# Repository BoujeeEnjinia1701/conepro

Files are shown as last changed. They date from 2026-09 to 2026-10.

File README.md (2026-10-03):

# ConePro

     

**Area:** Situational Field Hardware · **TRL:** 3 of 9 (proof of concept on paper) · **Value-engineering target:** about $400 USD (hypothetical control target; estimated instrument cost $346) · **Difficulty:** 3 of 5

Portable dynamic cone penetrometer with a digital depth encoder and blow counter that logs penetration curves to a phone.

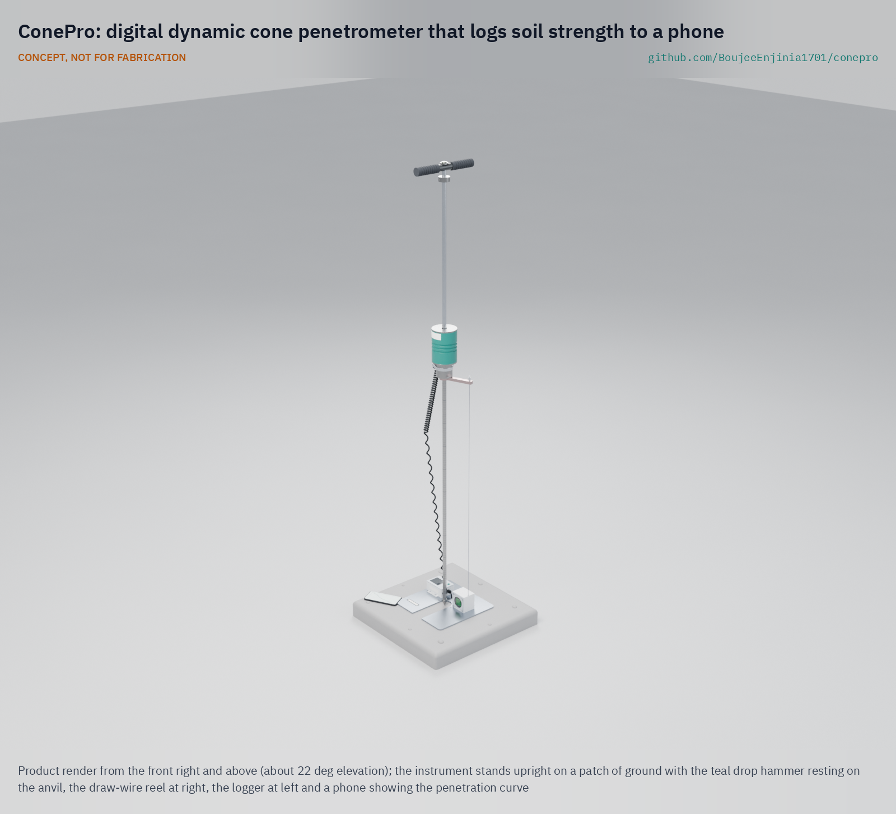
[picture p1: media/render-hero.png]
ConePro: digital dynamic cone penetrometer that logs soil strength to a phone, product render


[Exploded render](media/render-exploded.png) · [Detail render](media/render-detail.png) · [Interactive 3D model](media/viewer.html) · [Concept blueprint (PDF)](media/concept-blueprint.pdf) · [General arrangement CNP-DWG-001 (PDF)](cad/drawings/CNP-DWG-001.pdf) · [Calculations](docs/04-calcs/01-sizing.md) · [Prototype build plan](docs/05-build-plan.md) · [Design decisions](docs/06-design-decisions.md) · [Review note](docs/REVIEW.md)

## Concept rationale

The dynamic cone penetrometer is already the cheapest credible way to profile soil strength in the field, and decades of published correlations depend on its exact geometry. ConePro therefore changes nothing about the hammer, drop, rod or cone and adds only what the manual test lacks: an automatic depth reading, a blow count, a tilt check and a clean digital record. That lets one person do what took two, and keeps every result comparable with existing DCP data.

It is open and garage-buildable because the users who most need fast soil screening, such as small contractors, NGO engineers and rural road agencies, are the least able to buy or repair closed instrumented penetrometers. The steel parts are simple machined pieces any local shop can make, the electronics are off-the-shelf modules on three AA cells, and the sensor set is designed to clamp onto penetrometers people already own.

## Burning platform

Roads, shelters and water points all sit on ground whose strength is usually guessed rather than measured. The World Bank estimates that about [one billion rural people, one in eight people worldwide, live more than 2 km from an all-season road](https://datatopics.worldbank.org/sdgatlas/goal-9-industry-innovation-and-infrastructure/), and a 2026 dataset of 50 African countries and regions found an [average paved rate of only 17.4 %](https://essd.copernicus.org/articles/18/267/2026/) (Liu et al., *Earth System Science Data* 18, 267). The same authors note that most unpaved roads are dirt, and building or upgrading such a road starts from the strength of the ground beneath it.

Laboratory strength testing has long been skipped for reasons of time and cost: in 1956 Scala wrote that "very few road authorities use a strength test in evaluating the subgrade of a road" and proposed quick static and dynamic cone tests instead ([TRID record](https://trid.trb.org/View/1194062)). The DCP descends from that work. Even a well-resourced agency runs it as a two-person, pencil-and-form test: Minnesota's user guide describes one person on the hammer and a second reading and recording [the penetration for each blow](https://mdl.mndot.gov/index.php/_flysystem/fedora/2023-08/1993mrrdoc002.pdf). Removing that second person and the transcription step is what lets more points be tested per day where it matters.

## Where it could be used

### By industry

| Industry | Use |
| --- | --- |
| Low-volume and rural roads | Subgrade and gravel layer strength along a route, for DCP-based pavement design and maintenance planning |
| Humanitarian shelter and WASH | Screening ground for shelters, water tanks, latrines and access tracks where no lab is within reach |
| Utilities and civil contracting | Checking compaction of trench backfill and pipe bedding before reinstatement |
| Building and site preparation | A first look at pad and footing areas to decide where a geotechnical engineer should investigate |
| Mining and agriculture haul roads | Rapid checks of unsealed haul and farm roads after rain |
| Teaching and research | An open instrument and data format for soil mechanics courses and correlation studies |

### By country or region

| Country or region | Why it matters there |
| --- | --- |
| Burkina Faso | A Rural Access Index of [23.8 in 2020](https://datatopics.worldbank.org/sdgatlas/goal-9-industry-innovation-and-infrastructure/): only about one in four rural people live near a road usable year-round |
| Zambia and Kenya | Rural access ranges from [17 % in Zambia (2011) to 56 % in Kenya (2009)](https://datatopics.worldbank.org/sdgatlas/goal-9-industry-innovation-and-infrastructure/), so many earth and gravel roads are still to be built or upgraded |
| Peru | A Rural Access Index of [37.2 % in the 2017/18 update](https://documents1.worldbank.org/curated/en/543621569435525309/pdf/World-Measuring-Rural-Access-Update-2017-18.pdf), above 50 % in some Andean departments but below 5 % in Amazon regions, so many rural roads are still to be built on untested ground |
| Bangladesh | Rural access of [87 % in the World Bank's 2016 pilot](https://documents1.worldbank.org/curated/en/543621569435525309/pdf/World-Measuring-Rural-Access-Update-2017-18.pdf), the highest of the pilot countries, so much of the rural network already exists and the work shifts to checking and maintaining it |
| United States | Minnesota has used the DCP as an [acceptance tool for edge drain trench compaction since 1993](https://mdl.mndot.gov/index.php/_flysystem/fedora/2023-08/1993mrrdoc002.pdf), a high-income example of routine, repeated field testing |
| Australia and New Zealand | Scala's 1956 paper to the second Australia New Zealand Conference on Soil Mechanics and Foundation Engineering set out the quick cone tests from which the DCP descends ([TRID record](https://trid.trb.org/View/1194062); [Informit record](https://search.informit.org/doi/10.3316/informit.218423931293630)), a lineage ConePro keeps by leaving the hammer, rod and cone unchanged |

## What sparked the idea

The starting point was the construction of the Minnesota Road Research Project (Mn/ROAD) test road on Interstate 94 near Albertville ([MnDOT MnROAD](https://www.dot.state.mn.us/mnroad/)), where the Minnesota Department of Transportation ran more than 700 DCP tests during construction. That work led the department to write a [user guide to the dynamic cone penetrometer](https://mdl.mndot.gov/index.php/_flysystem/fedora/2023-08/1993mrrdoc002.pdf) ([catalog record](https://mdl.mndot.gov/items/m14731)). The guide shows both why the DCP spread and where it stalls: the instrument was valued for its portability and ease of use, yet the method it describes still needs a two-person crew, one on the hammer and one reading the rod against a reference and writing each blow on a standard form. ConePro takes that documented workflow and asks what it would take for one person to run it with the reading and the form done automatically.

## Problem

Early site assessments need soil bearing data, but lab geotech is slow. The manual dynamic cone penetrometer (ASTM D6951) is fast and cheap but needs two people, a rule and hand-written records, and existing instrumented penetrometers are closed and costly. Full problem statement: [docs/01-problem.md](docs/01-problem.md)

## Concept

Portable dynamic cone penetrometer with a digital depth encoder and blow counter that logs penetration curves to a phone. ConePro keeps the standard geometry (8 kg hammer, 575 mm drop, 20 mm 60 degree cone), measures penetration with a draw-wire sensor referenced to a plate on the ground, counts blows and reads rod tilt with a clamp-on Hall and accelerometer pad at the anvil, and sends each blow to a phone app that plots the profile and gives an indicative CBR. The sensor set is designed to fit existing standard penetrometers too. TRL 3 calculations give about 28 J at the cone, 850 mm per rod, about 40 h on three AA cells and $346 in parts; the instrument carried in its bag is about 15.8 kg, within the 16 kg target, and a 500 mm extension rod is an optional accessory for deeper tests. Depth accuracy and shock survival are still at risk. Results are for screening, not foundation design.

Full design precis: [docs/02-concept.md](docs/02-concept.md)

## Key components

- Hardened 20 mm, 60 degree cone and 16 mm steel rods
- 8 kg drop hammer with a 575 mm drop
- Draw-wire depth sensor on a ground reference plate (laser rangefinder as the fallback)
- Clamp-on sensor pad at the anvil: Hall-effect blow switch and tilt accelerometer on an isolator
- BLE logger on three AA cells
- Optional lever rod puller and 500 mm extension rod, carried separately

The priced bill of materials is in [bom/bom.csv](bom/bom.csv). Parametric geometry is in [cad/src/model.py](cad/src/model.py), with STEP and STL exports in `cad/step/` and `cad/stl/`.

## Building the prototype

The design has been made constructable: every part can be turned, drilled, cut, printed or bought, and every joint has a fixing (decision record CNP-DDR-004, accepted by Amish on 2026-10-02). The [prototype build plan](docs/05-build-plan.md) (CNP-BLD-001) shows how to make each of the 16 components and assemble them in 13 steps, with a making sketch for every made part (CNP-DWG-101 to 113), close-ups of the joints and a picture for every step. It is a plan, not a record of a build; building to it is TRL 4 work. Decisions still open are in the [design decisions register](docs/06-design-decisions.md).

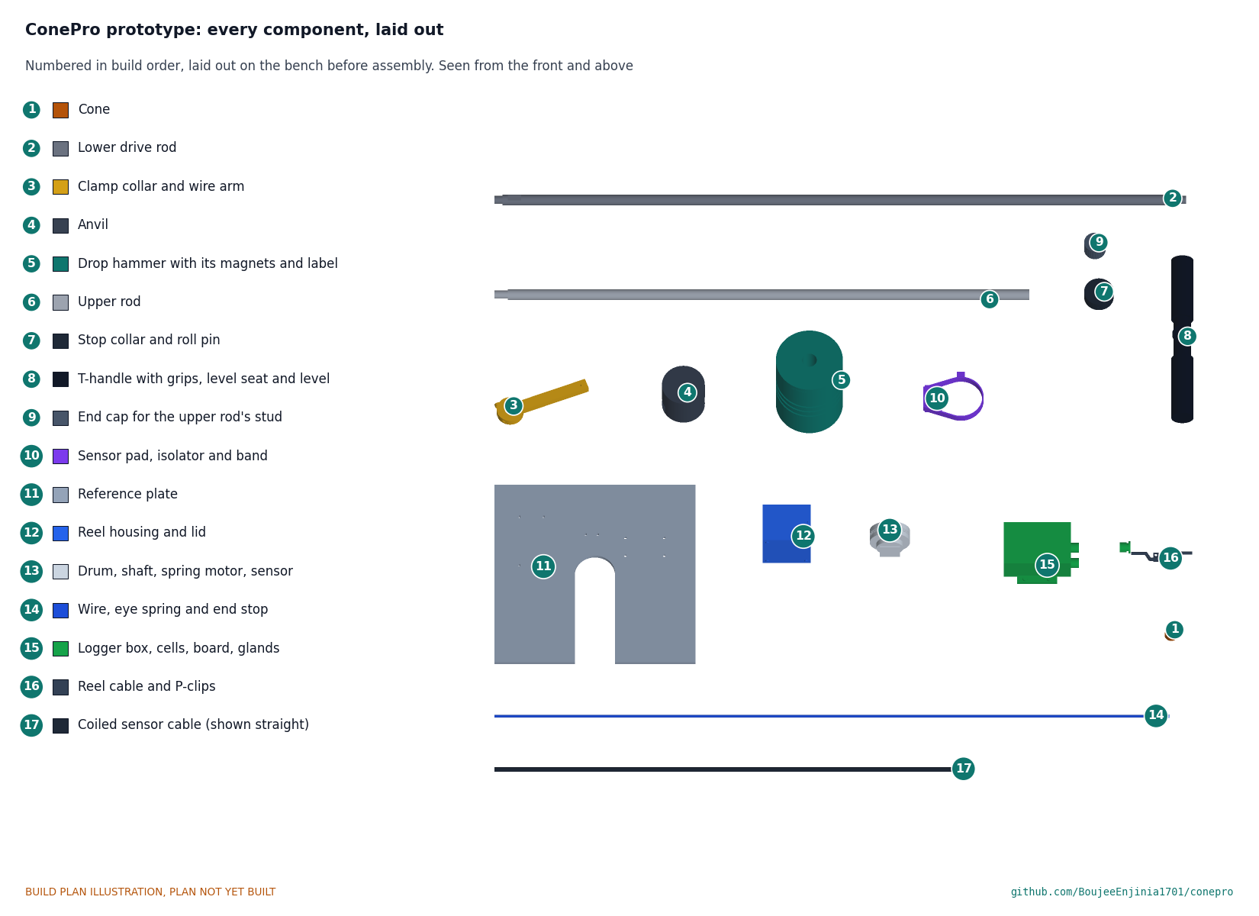
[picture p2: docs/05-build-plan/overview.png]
ConePro prototype: every component laid out in build order


## Safety

> **Safety:** Confirm utility locates before driving any rod into the ground. The 8 kg hammer can crush fingers, so keep hands on the handle only, and fit the end cap on the upper rod whenever it is off the anvil so the hammer cannot slide off; wear safety glasses and hearing protection. The hammer carries strong magnets; keep it away from implanted medical devices. ConePro results are indicative and must not be used on their own for foundation design. See the safety section of [docs/02-concept.md](docs/02-concept.md).

## Repository layout

| Folder | Contents |
| --- | --- |
| `docs/` | Problem, concept, requirements, calculations and design decisions |
| `cad/src/` | build123d Python source, the source of truth for all geometry |
| `cad/step/`, `cad/stl/` | Exported models for FreeCAD, other CAD tools and printing |
| `cad/drawings/` | 2D sketches and dimensioned drawings |
| `bom/` | Bill of materials |
| `electronics/` | KiCad schematics and PCB layouts |
| `firmware/` | Microcontroller code |
| `media/` | Renders, perspectives and photos |
| `build-log/` | Dated prototyping notes |

## Documentation

Controlled documents follow the portfolio [documentation standard](.kit/STANDARDS.md). Each carries a document ID (CNP-PRC-001 for the precis), a version and a revision history. Branded PDFs are built with `python .kit/render.py` and attached to GitHub Releases when a document is tagged, for example `CNP-PRC-001/v1.0`.

## Credits

Designed by Amish Chadha. See [CONTRIBUTORS.md](CONTRIBUTORS.md) for roles. To cite this design, use [CITATION.cff](CITATION.cff) (GitHub shows it as "Cite this repository").

AI assistance (Claude) was used to accelerate concept renders, prototype documentation and first-pass sizing calculations. Design direction and all decisions are Amish Chadha's, recorded in this repository's decision records (`docs/decisions/`).

## Licenses

- **Hardware** (CAD, drawings, BOM, electronics): [CERN-OHL-S v2](LICENSE)
- **Software** (firmware, scripts, notebooks): [MIT](LICENSE-SOFTWARE)

A project of the [Design Molecule](https://designmolecule.com) lab.

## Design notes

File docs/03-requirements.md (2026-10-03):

---
doc_id: CNP-REQ-001
title: ConePro requirements
project: ConePro
doc_type: Requirements
version: "0.9"
status: Draft
date: '2026-10-03'
author: Amish Chadha
license: CERN-OHL-S-2.0
revisions:
- version: "0.1"
  date: '2026-09-24'
  author: Amish Chadha
  change: Initial scaffold
- version: "0.2"
  date: '2026-09-25'
  author: Amish Chadha
  change: First measurable requirements for TRL 2, with status against the concept
- version: "0.3"
  date: '2026-09-25'
  author: Amish Chadha
  change: TRL 3 status from CNP-CAL-001; decisions in CNP-DDR-001 (R6 met by D1, R9 assumes the lever of D2, new R15 from D3); R10 total defined as carried in the bag
- version: "0.4"
  date: '2026-09-25'
  author: Amish Chadha
  change: Recommendations accepted by Amish (DDR-002); R5 restated to 850 mm per rod with the extension rod as a separate accessory; R10 met by the lighter plate, clamp and bag; status from CNP-CAL-001 v0.2
- version: "0.5"
  date: '2026-09-27'
  author: Amish Chadha
  change: Status from CNP-CAL-001 v0.3 after the reel housing change in CNP-DDR-003 (decided by Amish on 2026-09-27); R5 stroke 928 mm, 850 mm usable still met; R2 lean term 2.0 mm
- version: "0.6"
  date: '2026-09-30'
  author: Amish Chadha
  change: Status from CNP-CAL-001 v0.4 after the design for construction (CNP-DDR-004); R5 stroke 939 mm; R2 lean term 1.8 mm; R13 $335; R15 sensor set now includes the reel cable (line 17); no status changes
- version: "0.7"
  date: '2026-10-01'
  author: Amish Chadha
  change: Budget treated as a value-engineering target
- version: "0.8"
  date: '2026-10-02'
  author: Amish Chadha
  change: "Status from CNP-CAL-001 v0.6 after Amish's decisions of 2026-10-02 (grips, end cap, hammer grooves, spanner flats); R10 15.8 kg, heaviest piece 9.96 kg; R13 $346; no status changes"
- version: "0.9"
  date: '2026-10-03'
  author: Amish Chadha
  change: "R10 heaviest piece margin of 0.04 kg accepted by Amish on 2026-10-03"
---

# ConePro requirements

These requirements were checked by calculation at TRL 3 in CNP-CAL-001 v0.6 against the design decided in CNP-DDR-001, CNP-DDR-002 and CNP-DDR-003 and made constructable in CNP-DDR-004, with Amish's decisions of 2026-10-02 carried in. None is now not met: two are at risk, nine are met on paper and four cannot be verified until hardware exists. The two at risk are **R2** (depth accuracy) and **R11** (shock survival). Version 0.4 applies Amish's 2026-09-25 acceptance of the review recommendations (CNP-DDR-002): **R5** is restated as 850 mm per lower rod, with a 500 mm extension rod offered as a separately carried accessory instead of a 1,000 mm clause (D10), and **R10** is now met at about 15.7 kg (was 16.7 kg) with a 6 mm plate, an aluminum clamp and arm and a lighter bag (D9). Targets are still proposals, not yet validated with users, and will be revised after co-design (see CNP-PRB-001). Version 0.5 reflects the larger reel housing decided by Amish on 2026-09-27 (CNP-DDR-003): R5 stays met with a 928 mm stroke, and the lean term in R2 grows from 1.8 mm to 2.0 mm, so R2 stays at risk. R15 carries decision D3.

**Reference test.** A single test point driven to 850 mm in a medium-stiff soil averaging 15 mm per blow (about 57 blows), by one person, on level ground.

*Table 1. Requirements and status at TRL 3.*

| ID | Requirement | Target | Status at TRL 3 (CNP-CAL-001) | Verification (later) |
| --- | --- | --- | --- | --- |
| R1 | Standard DCP geometry | 8.0 kg hammer, 575 mm free drop, 16 mm rod, 20 mm cone with a 60 degree point, replaceable cone; tolerances as ASTM D6951 | Met (nominal): model gives 8.00 kg and 575 mm; tolerances to check against the standard | Drawing check against the standard |
| R2 | Depth measurement | Resolution 0.5 mm or finer; error within ±1 mm over a 1,000 mm range compared with a steel rule | **At risk:** 0.046 mm resolution; bench error ±0.98 mm worst case, ±0.49 mm root sum square; a 2 degree lean adds up to 1.8 mm at 850 mm after tilt correction; usable range set at 850 mm (D11) | Bench calibration |
| R3 | Blow detection | Every blow counted and no false counts from handling, over a 200-blow sequence | Not verifiable at TRL 3: Hall margin 2.3 times at the worst angle; three-signal logic (Hall, accelerometer peak, depth) | Bench blow sequence |
| R4 | Per-blow record | Depth after each blow logged within 0.5 s of impact, with blow number and time | Met (calculation): settled within 35 ms, recorded at 0.21 s | Firmware sketch review |
| R5 | Penetration range | 850 mm or more per lower rod; deeper tests with an optional 500 mm extension rod carried as a separate accessory, with automatic re-zero (restated by D10; was 1,000 mm or more with one extension rod) | Met: 939 mm stroke, 850 mm usable per rod; extension rod in BOM line 16 (optional); re-zero not verifiable at TRL 3 | Model check; field test |
| R6 | Verticality | Warn the operator when the rod is more than 5 degrees off vertical | Met by design (D1): accelerometer reads tilt to about ±0.3 degree; bubble level as backup | Bench tilt check |
| R7 | Phone output | Live plot of depth against blows; DCP index per layer; indicative CBR from the ASTM D6951 correlations with the soil type selected; CSV export with time, location and operator notes | Not verifiable at TRL 3 (app specified, not written) | App specification review |
| R8 | Works offline | No cell signal needed; logger stores 50 or more tests if the phone is absent or disconnects | Met (calculation): about 830 tests in 4 MB | Firmware sketch review |
| R9 | One-person test time | Reference test, including setup and rod extraction with the optional lever (D2), in 12 min or less by one person | Met (estimate), thin: 8.1 to 11.7 min | Timed trials |
| R10 | Portability | Total mass as carried in the bag, cells included and the optional lever and extension rod excluded, 16 kg or less; heaviest piece 10 kg or less; packed length 1.1 m or less | Met, thin: 15.8 kg (was 16.7 kg before D9); heaviest piece 9.96 kg with the grips and end cap, 0.04 kg under the limit (margin accepted by Amish, 2026-10-03); packed length about 1.08 m | Mass roll-up; weighing |
| R11 | Rugged electronics | Logger, sensors and connectors IP65; operate at 0 to 45 °C; anvil-mounted parts survive 10,000 blows | **At risk:** about 1,400 to 5,500 g mean at the anvil; about 540 g on the isolated pad against 10,000 g part ratings; cable and connector fatigue not calculated | Drop-count test |
| R12 | Battery life | 8 h or more of continuous logging on user-replaceable non-lithium cells | Met (calculation): about 40 h, about 20 h at 0 °C | Power measurement |
| R13 | Cost | Within the $400 value-engineering target (hypothetical control target, not a limit) for one complete instrument in parts (optional lever and extension rod excluded) | Within the value-engineering target: $346, $54 under; $412 with the lever and extension rod, $12 over the target | Priced BOM (`bom/bom.csv`) |
| R14 | Honest results | App states the correlation used and that results are indicative and not for foundation design | Not verifiable at TRL 3 (app not written) | App specification review |
| R15 | Retrofit fit (D3) | Sensor set (BOM items 8 to 12 and 17) fits a standard ASTM D6951 penetrometer with a 16 mm rod and a 50 to 80 mm anvil, without machining | Not verifiable at TRL 3: interfaces sized in the model; needs a commercial DCP to check | Fit check on a commercial DCP |

## Assumptions

- Soil behavior, blow rate and extraction time are estimates, not measurements. A practiced operator drops the hammer about once every 2.5 s; a slow one every 3.5 s.
- CBR correlations are those given in ASTM D6951 (from US Army Corps of Engineers work); other soils and regions may need local correlations.
- Mass estimates use steel at 7,850 kg/m³ and aluminum at 2,700 kg/m³ applied to the parametric model `cad/src/model.py`, plus catalog masses for bought parts (CNP-CAL-001, Table 2).
- Battery life assumes an average electronics draw of about 50 mA and about 2,000 mAh usable from AA alkaline cells at that current, halved at 0 °C.
- All other calculation assumptions are listed in CNP-CAL-001, Table 1.

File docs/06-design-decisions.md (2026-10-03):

---
doc_id: CNP-DEC-001
title: ConePro design decisions register
project: ConePro
doc_type: Design decisions register
version: "0.5"
status: Draft
date: '2026-10-03'
author: Amish Chadha
license: CERN-OHL-S-2.0
revisions:
  - version: "0.1"
    date: '2026-09-30'
    author: Amish Chadha
    change: Register opened with the open items from the review note, the decision records and the build plan work
  - version: "0.2"
    date: '2026-10-01'
    author: Amish Chadha
    change: Budget treated as a value-engineering target
  - version: "0.3"
    date: '2026-10-02'
    author: Amish Chadha
    change: Amish approved the recommendations for open decisions 1 to 7 (CNP-DDR-004 accepted with the thread-locker exception); moved to decisions made
  - version: "0.4"
    date: '2026-10-02'
    author: Amish Chadha
    change: Grips, end cap and hammer label priced in the BOM; value-engineering figures updated
  - version: "0.5"
    date: '2026-10-03'
    author: Amish Chadha
    change: "Amish accepted the R10 heaviest piece of 9.96 kg against 10 kg on 2026-10-03; row added to decisions made"
---

# ConePro design decisions register

Every design decision still to be made, and every decision made, in one place. Each decision is argued in full in its decision record under `docs/decisions/` or in the review note `docs/REVIEW.md`; this register is the index Amish works from. The build plan (`docs/05-build-plan.md`) describes the design as it stands and does not list open decisions.

## Open decisions

None. All open decisions were decided on 2026-10-02.

## To confirm when parts are bought

*Table 2. Items to check against the parts actually bought.*

| # | What to confirm | Why it matters | Source |
| --- | --- | --- | --- |
| 1 | The tolerances of ASTM D6951 for the cone, hammer mass and drop, against a copy of the standard | R1 is met only nominally until the tolerances are checked | CNP-CAL-001 section A |
| 2 | The bubble level is 20 mm across and about 6 mm tall | It sits in a 20 x 3 mm recess in the seat disc | CNP-DDR-004, P4 |
| 3 | The spring motor fits in 40 mm diameter x 8 mm and gives about 3 N retracted to 5 N extended | The reel layout and the wire slack and snap calculations assume it | CNP-CAL-001 [E5] |
| 4 | The angle sensor board is about 30 x 30 mm, 12-bit, with a matching diametric magnet | It mounts on the lid 1.4 mm from the shaft magnet | CNP-DDR-004, P8 |
| 5 | The flanged IP65 logger box, about 100 x 70 x 42 mm, and its flange hole spacing (82 mm across, 36 mm along) | It sets the four tapped holes in the plate | CNP-DDR-004, P9 |
| 6 | The M12 glands seal on 5 mm and 6 mm cable | IP65 entries for both cables (R11) | CNP-DDR-004, P10, P11 |
| 7 | The band clamp's range takes the anvil plus the pad (about 90 mm across) | It goes round the anvil and over the pad | CNP-DDR-004, P7 |
| 8 | The Hall switch and accelerometer are rated to 10,000 g shock, and the elastomer gives about 300 Hz isolation with the pad | The shock calculation assumes both | CNP-CAL-001 section G |
| 9 | The bearings are 6 x 13 x 5 mm and fit the 18 mm boss | The boss is printed to suit | CNP-DDR-004, P8 |

## Value engineering

Value-engineering target: USD 400 (a hypothetical control target, not a limit). Estimated cost of the constructable design: USD 346 (USD 54 under the target). This is the instrument; the kit with both optional accessories is USD 412 (USD 12 over the target).

- **Main cost drivers:** the mechanical penetrometer (items 1 to 7, USD 180), sensing and logging (items 8 to 12 and 17, USD 113), and the carry bag, hardware and consumables (USD 53); the optional lever (USD 50) and extension rod (USD 16) are outside the instrument total. The design for construction added USD 16 (the reel-to-logger cable at USD 6 and USD 10 of welding, fixings and reel parts).
- **Decided on 2026-10-02 and now priced:** rubber grips on the T-handle (BOM line 6, USD 6, about USD 3 each from a hardware or tool shop) and the end cap for the upper rod with the hammer label (line 14, USD 5: a small lathe part at about USD 4 and a printed label at about USD 1).
- **Savings worth trying:** trim the price of the optional accessories, which would bring the full kit closer to the target; and re-price the sensing parts at purchase.

## Decisions made

*Table 3. Decisions made, with the record that holds each.*

| Date | Decision | Decided by | Record |
| --- | --- | --- | --- |
| 2026-09-25 | TRL 2 review items D1 to D8: accelerometer tilt with a bubble level backup; optional lever extraction; sensor set designed to fit standard DCPs; draw-wire depth with a laser fallback; standard 8 kg geometry; Hall blow detection with cross-checks; electronics on the plate; three AA cells | Amish: "proceed with all of your recommendations across all batches. Make sure we don't proceed to TRL 4 on any of them." | [CNP-DDR-001](decisions/0001-trl2-review-decisions.md) |
| 2026-09-25 | D9 lighter carried set (6 mm plate, aluminum clamp, 0.40 kg bag); D10 R5 at 850 mm per rod with an optional extension rod; D11 reel details and 850 mm usable range; D12 disposable-cone practice for stiff ground | Amish: "i accept all your recommendations, go with them across all repos." | [CNP-DDR-002](decisions/0002-recommendations-accepted.md) |
| 2026-09-27 | Keep the 60 mm drum and grow the reel housing to 72 x 60 x 72 mm | Amish asked to "resolve the challenges for ConePro, BridgePulse, Grainguard and WellSense" and chose this option | [CNP-DDR-003](decisions/0003-reel-housing-size.md) |
| 2026-09-30 | Make the design physically buildable while drawing the build plan; changes recorded in CNP-DDR-004 and open for review; accepted on 2026-10-02 with one exception (below) | Amish: "If you are realising that the design cannot be built as per concept - fix the design assumptions to match and be physically feasible as you draw the illustrations." | [CNP-DDR-004](decisions/0004-design-for-construction.md) |
| 2026-09-30 | Open decisions go in this register, not in the build plan | Amish: "don't log outstanding decisions in this build plan - that is not the place for it. that should be in a separate design document logged and named as such" | This register |
| 2026-10-02 | Design for construction accepted, P1 to P12 as made, with one exception: no thread locker on the rod, anvil and cone joints; they are tightened with spanners and checked before each test, because they are undone for packing and for disposable cones | Amish: "i approve your recommendations for all 555 open decisions." | CNP-DDR-004, Tables 1 and 2 |
| 2026-10-02 | A screw-on end cap goes on the upper rod's M12 stud whenever the rod is off the anvil, with a label on the hammer saying so | Amish: "i approve your recommendations for all 555 open decisions." | CNP-DDR-004, A1 |
| 2026-10-02 | First co-design partner to approach: a low-volume road agency (a county or district road department) that already runs manual DCP tests on unpaved roads; a university pavement or geotechnical lab is the second choice, for example the civil engineering department at the University of Texas at Arlington | Amish: "i approve your recommendations for all 555 open decisions." | CNP-DDR-001 and CNP-DDR-002, O1 |
| 2026-10-02 | The clear windows in the reel housing and logger lid stay render-only features; the parts stay opaque | Amish: "i approve your recommendations for all 555 open decisions." | `docs/REVIEW.md`, 2026-09-26, item 2 |
| 2026-10-02 | Grip grooves on the hammer accepted; the hammer length is set at machining so it still weighs 8.00 kg | Amish: "i approve your recommendations for all 555 open decisions." | `docs/REVIEW.md`, 2026-09-26, item 3 |
| 2026-10-02 | Rubber grips of about 33 mm diameter added to BOM line 6 | Amish: "i approve your recommendations for all 555 open decisions." | `docs/REVIEW.md`, 2026-09-26, item 4 |
| 2026-10-02 | The coiled cable path as drawn in the renders accepted | Amish: "i approve your recommendations for all 555 open decisions." | `docs/REVIEW.md`, 2026-09-26, item 5 |
| 2026-10-03 | R10 heaviest piece of 9.96 kg against the 10 kg limit (0.04 kg margin) accepted | Amish: "TIght Margins - i accept the margins" | CNP-REQ-001, R10; CNP-CAL-001 v0.6; [REVIEW.md](REVIEW.md), session 2026-10-03 |

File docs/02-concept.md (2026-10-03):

---
doc_id: CNP-PRC-001
title: ConePro design precis
project: ConePro
doc_type: Design precis
version: "0.9"
status: Draft
date: '2026-10-02'
author: Amish Chadha
license: CERN-OHL-S-2.0
revisions:
- version: "0.1"
  date: '2026-09-24'
  author: Amish Chadha
  change: Initial scaffold
- version: "0.2"
  date: '2026-09-25'
  author: Amish Chadha
  change: Populate to TRL 2 (architecture, first-order numbers, safety, media)
- version: "0.3"
  date: '2026-09-25'
  author: Amish Chadha
  change: TRL 3 update; design choices decided (CNP-DDR-001); numbers replaced by CNP-CAL-001 results; parametric model, drawing CNP-DWG-001 and refreshed media
- version: "0.4"
  date: '2026-09-25'
  author: Amish Chadha
  change: Recommendations accepted by Amish (DDR-002); 6 mm plate, aluminum clamp and lighter bag (15.7 kg), optional extension rod, reel details accepted, stiff-ground guidance; numbers from CNP-CAL-001 v0.2; CNP-DWG-001 Rev P2
- version: "0.5"
  date: '2026-09-27'
  author: Amish Chadha
  change: Reel housing 72 x 60 x 72 mm round the 60 mm drum (CNP-DDR-003, decided by Amish on 2026-09-27); stroke 928 mm, 850 mm usable; numbers from CNP-CAL-001 v0.3; CNP-DWG-001 Rev P3
- version: "0.6"
  date: '2026-09-30'
  author: Amish Chadha
  change: Design for construction (CNP-DDR-004, open for Amish's review); M12 rod joints, one-piece clamp against the anvil, reel internals and fixings, reel-to-logger cable (BOM line 17); stroke 939 mm; $335; numbers from CNP-CAL-001 v0.4; CNP-DWG-001 Rev P5; build plan CNP-BLD-001
- version: "0.7"
  date: '2026-10-01'
  author: Amish Chadha
  change: Budget treated as a value-engineering target
- version: "0.8"
  date: '2026-10-02'
  author: Amish Chadha
  change: "Decisions of 2026-10-02 carried in: end cap for the upper rod, T-handle grips, hammer grip grooves, first co-design partner to approach"
- version: "0.9"
  date: '2026-10-02'
  author: Amish Chadha
  change: "Approved decisions carried into the model, BOM and calculations (CNP-CAL-001 v0.6): spanner flats on the cone, lower rod and anvil; grips, end cap and label priced; hammer 138.0 mm; heaviest piece 9.96 kg; 15.8 kg; $346"
---

# ConePro design precis

ConePro is a standard-geometry dynamic cone penetrometer (8 kg hammer, 575 mm drop, 20 mm 60 degree cone, as in ASTM D6951) with a draw-wire depth sensor referenced to a plate on the ground, a clamp-on sensor pad at the anvil that detects blows and reads rod tilt, and a small BLE logger, so one person can run a test while the phone plots penetration against blows and exports the record. The sensor set is designed to fit existing standard penetrometers too. The TRL 3 calculations (CNP-CAL-001 v0.4) give about 28 J at the cone per blow, 850 mm of usable penetration per lower rod, about 40 h of logging on three AA cells and $335 in parts, $65 under the $400 value-engineering target (a hypothetical control target, not a limit). With the changes Amish accepted on 2026-09-25 (CNP-DDR-002), the instrument carried in its bag weighs about 15.7 kg (was 16.7 kg) and meets the 16 kg target (R10), and a 500 mm extension rod is a separately carried accessory for tests deeper than 850 mm (R5). On 2026-09-27 Amish decided to keep the 60 mm drum and grow the reel housing to 72 x 60 x 72 mm (CNP-DDR-003), which trimmed the stroke from 940 mm to 928 mm. On 2026-09-30, under Amish's instruction to make the design physically buildable, the model was made constructable (CNP-DDR-004, accepted by Amish on 2026-10-02 with one exception: no thread locker on the rod, anvil and cone joints): threaded rod joints, a one-piece clamp that butts the anvil, a reel with its drum, spring motor and sensor inside, fixings for every part and a cable from the reel to the logger. The stroke is now 939 mm, and the prototype build plan (CNP-BLD-001, `docs/05-build-plan.md`) shows how to make and assemble every part. No requirement is now not met; depth accuracy (R2) and shock survival (R11) remain at risk.

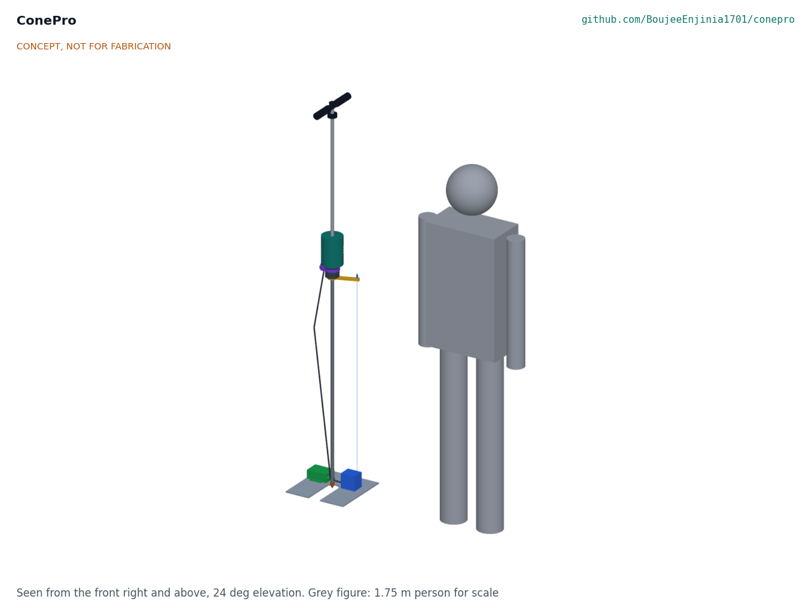
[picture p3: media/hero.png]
Hero render


*Figure 1. ConePro set up at the start of a test, with a 1.75 m person for scale. The cone tip rests on the ground through the slotted reference plate and the hammer rests on the anvil.*

## How it works

1. **Set up.** The operator lays the slotted reference plate on the ground, stands the cone in the plate's center hole, clamps the draw-wire arm to the rod just below the anvil and straps the sensor pad to the anvil. The app zeroes the depth with the cone point at the surface, and zeroes the tilt by turning the rod half a turn.
2. **Drive.** The operator holds the handle, lifts the 8 kg hammer to the top stop and lets it fall 575 mm onto the anvil. Each blow drives the rod and cone further into the soil.
3. **Sense.** A ring of magnets in the hammer face passes a potted Hall-effect switch in the sensor pad as the hammer lands, and the pad's accelerometer sees the impact peak. A blow counts only when both fire and the depth steps down or holds within 0.5 s. Between blows the accelerometer reads rod tilt. A draw-wire sensor on the plate measures how far the clamp arm has moved down, which equals the cone's penetration because the rod is rigid and the plate stays on the ground surface.
4. **Log.** The logger on the plate reads depth at 100 Hz, waits 0.2 s for the rod and wire to settle after each blow, and stores blow number, depth, tilt and time. It keeps the record even when no phone is connected.
5. **Show.** The phone app plots depth against blows, corrects depth for rod lean, splits the curve into layers of near-constant slope, and gives each layer's DCP index (mm per blow) and an indicative CBR from the ASTM D6951 correlations, with the correlation named on screen. It warns when the rod leans more than 5 degrees. The user exports a CSV with time, location and notes.
6. **Extract.** After the test the operator removes the plate over its slot and pulls the rod out with the optional lever rod puller, which is carried separately. For tests deeper than 850 mm the operator adds the optional 500 mm extension rod and the app re-zeroes. In stiff ground where the lever will not free the rod, the user guidance follows the disposable-cone practice: drive a disposable cone that stays in the ground, so the rod comes out through a hole slightly larger than itself (CNP-DDR-002, D12).

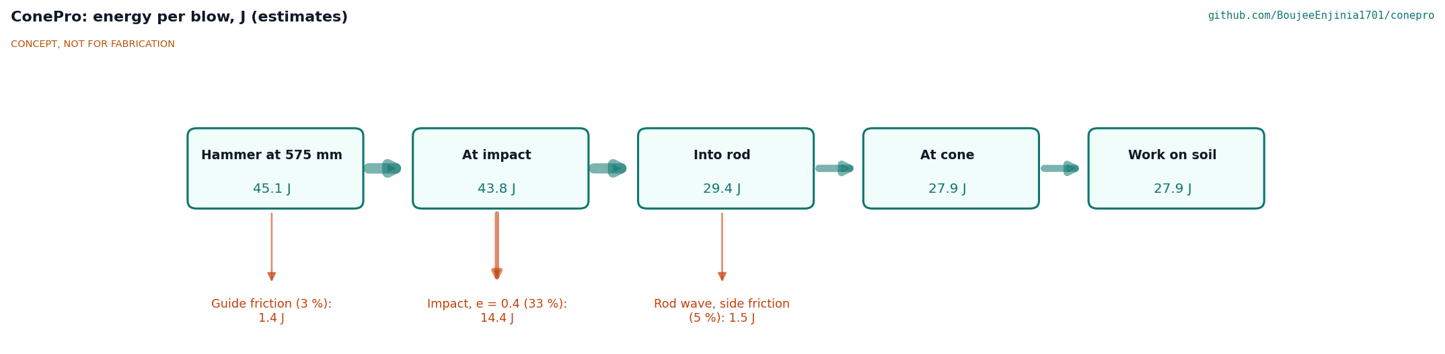
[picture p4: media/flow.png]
Energy flow


*Figure 2. Energy per blow from hammer to soil, in joules (estimates from CNP-CAL-001, section B). The impact loss depends on the restitution between hammer and anvil, which is assumed, not measured.*

## Main components

Numbers match the exploded view (Figure 3) and `bom/bom.csv`. Geometry is in the parametric model `cad/src/model.py` and on drawing CNP-DWG-001.

| # | Component | Choice | Notes |
| --- | --- | --- | --- |
| 1 | Cone | Hardened steel, 20 mm base, 60 degree point, 12 mm shoulder tapped M12 with 17 mm spanner flats, screwed onto the rod | Replaceable; a worn cone biases results |
| 2 | Lower drive rod | 16 mm steel, 1,000 mm between shoulders, M12 studs on both ends, 13 mm spanner flats near the bottom, engraved every 10 mm | Engraving is a manual backup scale and the calibration reference |
| 3 | Anvil and coupler | Steel, 64 mm diameter x 60 mm, tapped M12 at both ends, 55 mm spanner flats below the pad | Plain; the sensor pad clamps on (D3); the rod, anvil and cone joints carry no thread locker and are tightened with spanners (decided 2026-10-02) |
| 4 | Drop hammer | 8.0 kg steel, 100 mm OD x 22 mm bore x 138.0 mm, three grip grooves | Sixteen 8 x 4 mm magnets bonded in pockets in the lower face, outside the strike area; grip grooves, with the length set at machining to keep 8.00 kg (decided 2026-10-02) |
| 5 | Upper rod (hammer guide) | 16 mm steel, 778 mm above the anvil plus an M12 stud, running up through the handle; screw-on end cap on the stud whenever it is off the anvil | Gives the 575 mm free drop to the stop; the end cap keeps the hammer on the rod when packed (decided 2026-10-02) |
| 6 | Handle and top stop | 26 mm tube T-handle welded to the upper rod, 44 mm stop collar on a 6 mm roll pin, bubble level on a welded seat | Level is the tilt backup (D1); rubber grips about 33 mm across on the T-handle (decided 2026-10-02) |
| 7 | Reference plate | 300 x 300 x 6 mm aluminum, 60 mm center hole and slot | Depth reference on the ground surface; 6 mm to save mass (D9) |
| 8 | Draw-wire depth sensor | 60 mm grooved aluminum drum, single layer, constant-force spring, 12-bit angle sensor, groove keeper, preloaded eye spring | Drum must be metal for thermal stability; bought industrial sensor is the fallback |
| 9 | Anvil clamp and wire arm | One piece cut from 12 mm aluminum plate: split collar on the lower rod, butting the anvil underside, arm about 115 mm to the wire eye | Wire exit on the plate 105 mm from the rod; aluminum to save mass (D9) |
| 10 | Blow and tilt sensor pad | Hall switch and 3-axis accelerometer, potted, on a 300 Hz elastomer isolator, band clamp for 50 to 80 mm anvils | Top 8 mm below the anvil top, under the hammer overhang |
| 11 | BLE logger | Microcontroller with BLE, 4 MB flash, button and LED, three AA cells, IP65 box | Kept on the plate, away from impacts |
| 12 | Coiled sensor cable | Pad to logger, with a strain relief at each end | Follows the rod down during the test |
| 17 | Reel-to-logger cable | 4-core cable through glands, in two P-clips on the plate | Carries the angle sensor signal; added for construction (CNP-DDR-004) |
| 15 | Rod extraction lever (optional) | Lever puller with a self-gripping 16 mm rod clamp, about 10:1, about 3 kg | Carried separately; outside the R13 total (D2) |
| 16 | Extension rod (optional) | 16 mm steel, 500 mm, M12 studs and a 20 mm coupling sleeve, engraved every 10 mm, 0.79 kg | Carried separately with the lever; outside the R10 mass and R13 total (D10) |

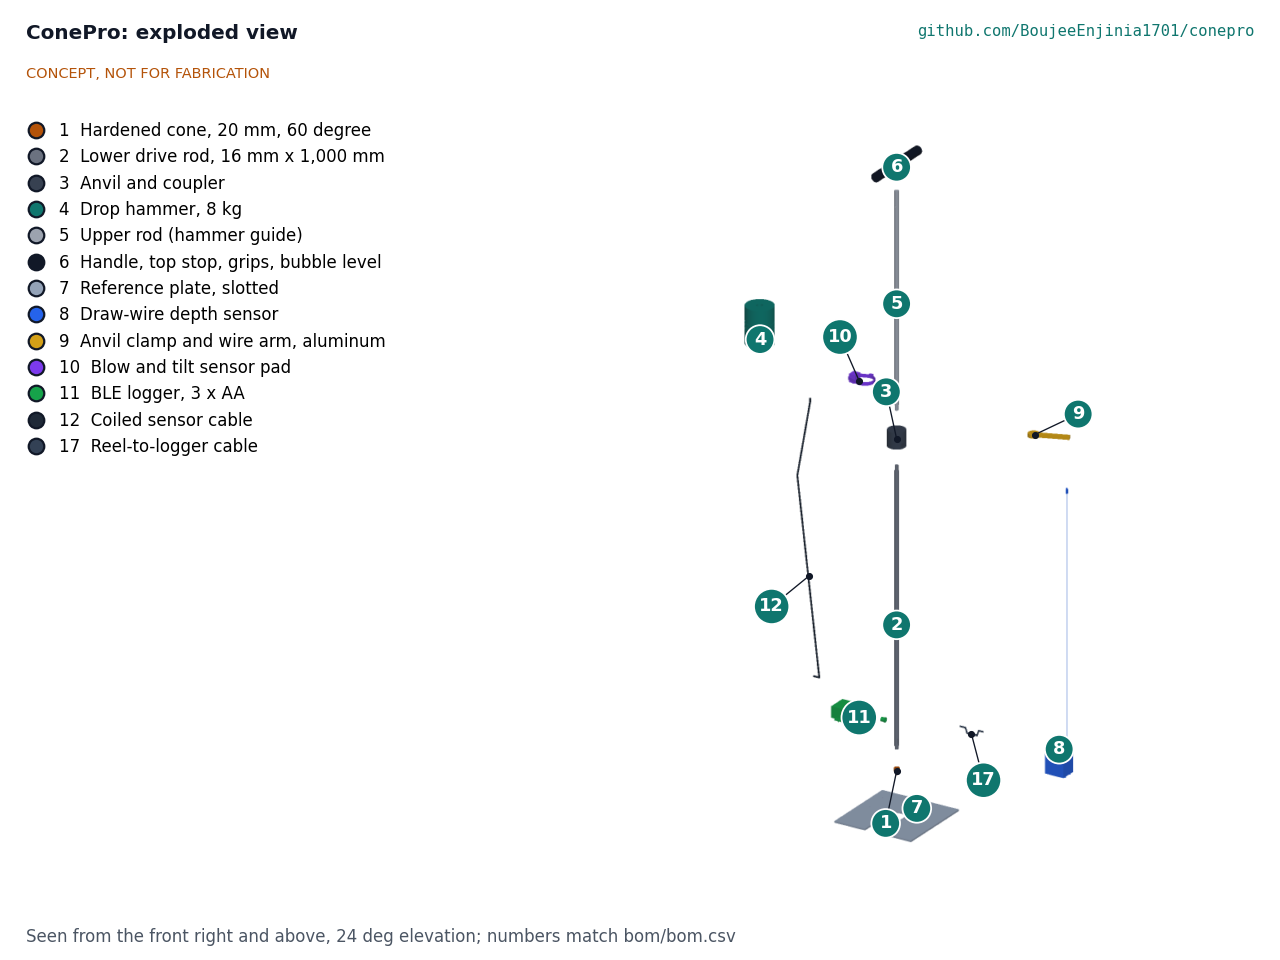
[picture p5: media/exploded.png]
Exploded view


*Figure 3. Exploded view with numbered callouts matching the BOM. The carry bag, hardware and the optional extraction lever and extension rod are not shown.*

## Key numbers

All values are estimates from CNP-CAL-001; the bracketed tag names the line of `docs/04-calcs/sizing.py` that prints each one.

*Table 1. Blow energy and timing.*

| Quantity | Estimate | Basis |
| --- | --- | --- |
| Potential energy per blow | 45.1 J [B1] | 8.0 kg x 9.81 m/s² x 0.575 m |
| Impact speed; fall time | 3.36 m/s; 0.342 s [B1] | Free fall over 575 mm |
| Energy reaching the cone | 27.9 J, 62 % (26.0 to 31.2 J) [B4] | 3 % guide friction; Hiley impact efficiency with restitution 0.4 (0.2 to 0.6) and 5.14 kg driven mass; 5 % rod and side friction |
| Mean dynamic soil resistance | 1.9 kN at 15 mm per blow; 14.0 kN at 2 mm per blow [B6] | Energy at the cone over penetration |
| Blow rate | 17 to 24 per minute | One blow every 2.5 to 3.5 s (assumed) |

**What the numbers mean for the user.** The ASTM D6951 correlation for most soils is CBR = 292 / DCP^1.12, with DCP in mm per blow (separate correlations apply to lean clays below CBR 10 and to fat clays). Table 2 shows how sharply the indicative CBR changes at small penetrations, which is why depth accuracy matters most in stiff layers.

*Table 2. Indicative CBR from the ASTM D6951 general correlation [E7].*

| DCP index (mm per blow) | 2 | 5 | 10 | 15 | 25 | 50 |
| --- | --- | --- | --- | --- | --- | --- |
| Indicative CBR (%) | 134 | 48 | 22 | 14 | 8 | 4 |

*Table 3. Depth measurement.*

| Quantity | Estimate | Requirement |
| --- | --- | --- |
| Resolution | 0.046 mm per count [E1] | R2 resolution met |
| Bench error over 1,000 mm, vertical rod | ±0.98 mm worst case; ±0.49 mm root sum square [E3] | R2 (±1 mm) at risk |
| Extra error from rod lean at 850 mm, after tilt correction | 0.95 mm at 1 degree; 1.79 mm at 2 degrees [E4] | Why the usable range stops at 850 mm (accepted, D11) |
| DCP index error, 10 blows at 2 mm per blow | ±4.9 % RSS (±9.8 % worst); CBR ±5.5 % [E8] | |
| Wire slack after a blow | 1.9 to 17 mm for 5 to 35 ms [E5] | Groove keeper and preloaded eye spring needed |
| Record latency | 0.21 s after impact [E6] | R4 met |
| Plate settlement or heave | Not calculable; static pressure only 0.24 kPa [E9] | Open question |

*Table 4. Range, mass, time, shock and power.*

| Quantity | Estimate | Requirement |
| --- | --- | --- |
| Stroke per lower rod | 939 mm, limited by the wire arm meeting the reel housing (72 x 60 x 72 mm round the 60 mm drum, CNP-DDR-003); 850 mm usable [D1, D2]; optional 500 mm extension rod [C7] | R5 (restated, D10) met |
| Assembled height | 1,875 mm [A3] | |
| Mass as carried in the bag | 15.8 kg (was 16.7 kg); 15.4 kg without the bag [C2, C6] | R10 (16 kg) met, thin |
| Heaviest piece | 9.96 kg, hammer captive on the upper rod with the grips and end cap [C3] | R10 (10 kg) met, 0.04 kg to spare |
| Packed length | About 1.08 m (longest piece 1,029 mm) [C4] | R10 met |
| Reference test time | 8.1 to 11.7 min [J1] | R9 met, thin |
| Shock at the anvil; at the isolated pad | 1,400 to 5,500 g mean; about 542 g [G1, G2] | R11 at risk |
| Tilt reading | ±0.3 degree after rotation zeroing [H1] | R6 met by design |
| Average current; battery life | 50.2 mA; 40 h, 20 h at 0 °C [K1, K2] | R12 met |
| Storage | About 830 tests in 4 MB [I1] | R8 met |

*Table 5. Cost [L1].*

| Group | Indicative cost |
| --- | --- |
| Mechanical DCP (items 1 to 7) | $180 |
| Sensing and logging (items 8 to 12, 17) | $113 |
| Carry bag, hardware and consumables (items 13, 14) | $53 |
| **Instrument total** | **$346** (R13, within the $400 value-engineering target) |
| Optional extraction lever (item 15) and extension rod (item 16) | $50 and $16, outside the instrument total |

## Key design choices

Amish decided the TRL 2 review items on 2026-09-25 by accepting every recommendation (CNP-DDR-001). The choices below are therefore decided, not proposed.

- **ASTM D6951 geometry (D5).** The standard 8 kg hammer and 575 mm drop, so users can apply published correlations and compare with existing DCP data. The 4.6 kg option is noted for later.
- **Depth by draw-wire from a ground plate (D4).** A draw-wire reel on the plate measures the clamp arm's movement. A laser time-of-flight sensor is the fallback to compare later. TRL 3 adds three details to meet the calculations: a metal, single-layer grooved drum; a groove keeper for the slack after each blow; and a preloaded spring at the arm eye to limit the snap tension.
- **Blow detection by Hall sensor with cross-checks (D6).** A blow counts when the Hall switch sees the hammer arrive, the accelerometer sees an impact peak and the depth steps down or holds within 0.5 s. A peak below half the full-drop value flags a short drop.
- **Tilt by accelerometer, with a bubble level as backup (D1).** The accelerometer in the sensor pad reads tilt between blows, and the app warns above 5 degrees and corrects depth for lean.
- **Electronics on the plate (D7).** Only the isolated sensor pad sees impacts.
- **Three AA cells (D8).** No lithium safety or shipping issues; sold everywhere.
- **Optional lever for extraction (D2).** A lever puller with a rod clamp, carried separately and outside the instrument cost and mass.
- **Sensor set fits standard DCPs (D3).** The clamp, band-mounted pad, plate and reel need no machining of the penetrometer (R15). The prototype is a complete instrument.

The TRL 3 calculations raised four further items, which Amish decided on 2026-09-25 by accepting every recommendation (CNP-DDR-002):

- **Lighter carried set (D9).** A 6 mm aluminum plate (1.29 kg, was 1.72 kg), an aluminum clamp and arm (0.12 kg, was 0.34 kg) and a 0.40 kg nylon roll bag (was 0.80 kg) bring the carried mass from 16.7 kg to 15.7 kg, within R10.
- **Extension rod as an accessory (D10).** R5 is restated as 850 mm per lower rod. A 500 mm extension rod is carried separately with the lever for deeper tests.
- **Reel details accepted (D11).** The metal single-layer grooved drum, groove keeper and preloaded eye spring stay in BOM line 8, and the usable range stays at 850 mm per rod. The bought industrial draw-wire sensor remains the fallback.
- **Stiff ground (D12).** No hardware change; the user guidance states the disposable-cone practice for ground where the lever cannot free the rod.

## Safety

> **Safety:** ConePro drops an 8 kg steel hammer onto a steel anvil every few seconds and drives a pointed steel rod into the ground. Treat buried services, crushed fingers, flying fragments, noise, back strain and misuse of the results as hazards at every test point.

- **Buried services.** A rod driven 1 m into the ground can strike electric cables, gas pipes and water mains. Get a utility locate before every test (in the United States, call 811 or use the state one-call service) and do not test within the marked tolerance zone.
- **Crushed fingers and hands.** The hammer lands with about 44 J. Keep hands on the handle only, never on the anvil, the hammer's lower face, the sensor pad or the clamp arm. The pad sits 8 mm under the hammer overhang, which is a pinch point: fit and remove it only with the hammer held at the top stop or removed.
- **Flying fragments and mushrooming.** Repeated steel-on-steel impact at thousands of g can chip the anvil or hammer face and spall hardened steel. Wear safety glasses, inspect the faces, and replace them when they mushroom or crack.
- **Magnets.** The hammer carries sixteen strong magnets. Keep it away from pacemakers and other implanted devices, and from cards and instruments that magnets can damage.
- **Draw-wire.** A wire that breaks or is released under tension can whip. Keep faces away from the reel and never let the arm snap back.
- **Noise.** Steel-on-steel impact is loud at close range. Hearing protection is recommended; the level is not yet estimated.
- **Lifting and posture.** The hammer is lifted about 57 times per test and the upper assembly weighs about 10 kg. Use a straight back and swap operators on long test days. Pull the rod only with the lever, never by back strength; stop if the lever will not move it (the pull force can exceed 3 kN in stiff ground), and use a disposable cone for further tests at that site (D12).
- **Rod whip and tipping.** A leaning rod can bend or kick sideways when struck. Stop when the app warns of lean (R6).
- **Hammer sliding off when packed.** Whenever the upper rod is off the anvil, a screw-on end cap on its M12 stud stops the 8 kg hammer sliding off onto the user's feet; a label on the hammer says so (decided 2026-10-02).
- **Sharp cone.** Cover the cone in transport.
- **Ground and site hazards.** Contaminated land, trench edges and traffic: follow site rules and do not test at the edge of an open excavation.
- **Misuse of results.** CBR values are indicative correlations. ConePro results must not be used on their own to design foundations or to decide that ground is safe to build on; they show where a qualified geotechnical engineer should investigate.
- **Batteries.** Alkaline AA cells carry little risk; remove them for storage to avoid leakage.

## Open questions

- Approach the first co-design partner: a low-volume road agency (a county or district road department) that already runs manual DCP tests on unpaved roads, with a university pavement or geotechnical lab as the second choice (decided 2026-10-02; not yet agreed).
- Measure the restitution, the magnet field with the steel hammer, the isolator response and the draw-wire error on a bench.
- Estimate plate settlement or heave under blows, and how to detect it (for example a second reference point).
- Define the blow and depth data format and the layer-splitting method; check against ORN 8 practice.
- Confirm commercial prices for instrumented penetrometers (not yet checked online).

Concept media: [blueprint sheet](../media/concept-blueprint.pdf), [interactive 3D model](../media/viewer.html). General arrangement: [CNP-DWG-001](../cad/drawings/CNP-DWG-001.pdf).

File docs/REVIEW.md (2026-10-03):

# Review note: ConePro

## Session 2026-09-25: /populate to a strong TRL 2

### What was done

- `docs/01-problem.md` (CNP-PRB-001 v0.2): problem, prior work (ASTM D6951, Scala, Kleyn, US Army Corps, TRL Overseas Road Note 8, PANDA), users, what ConePro does and does not give, constraints, out of scope, open questions. There was no co-design checklist to keep.
- `docs/03-requirements.md` (CNP-REQ-001 v0.2): 14 measurable requirements (R1 to R14) with targets and a status column, a reference test and assumptions.
- `docs/02-concept.md` (CNP-PRC-001 v0.2): how it works, numbered components, blow energy, CBR sensitivity, depth error, range, mass, test time, shock, power and cost estimates, design choices with options, safety, open questions.
- `cad/src/concept_media.py`: massing model of a standard DCP (cone, rods, anvil, 8 kg hammer, handle) with the reference plate, draw-wire sensor, anvil clamp, blow sensor, logger and cable, each with a BOM number; 1.75 m scale figure. It redraws the exploded view with leader lines, because the kit's on-part callouts hid the small sensor parts on a 1.9 m tall assembly, and it removes the renderer's temporary `media/_views*` folders.
- `media/`: `hero.png`, `concept-blueprint.png`, `.pdf` and `.svg`, `exploded.png`, `flow.png` (energy per blow, all values labeled as estimates), `model.glb` and `viewer.html`. No cutaway: the parts are solid or simple annular steel pieces, and the hero and exploded views already show how they fit.
- `bom/bom.csv`: 14 lines with indicative USD prices, lines 1 to 12 numbered to match the exploded view; `bom/bom-notes.md` updated.
- `README.md`: hero image and links line inserted before "## Problem"; problem, concept, key components and safety text brought in line with the precis.
- `docs/pdf/`: branded PDFs of the three controlled documents.

### Key results (estimates, to be checked at TRL 3)

| Quantity | Estimate | Requirement |
| --- | --- | --- |
| Energy per blow | about 45.1 J, about 33 J at the cone | R1 (standard geometry) met |
| Penetration per lower rod | about 850 mm | R5 met |
| Depth resolution and accuracy | about 0.05 mm resolution; about ±2 mm accuracy for a low-cost reel | **R2 at risk** (±1 mm target) |
| Total mass, heaviest piece | about 15.2 kg, about 9.8 kg | R10 met, thin margins |
| Reference test time (850 mm, 57 blows) | about 8 to 10 min | **R9 at risk** until extraction is chosen |
| Impact shock at the anvil | hundreds to a few thousand g | **R11 at risk** |
| Battery life, three AA cells | about 40 h | R12 met |
| Parts cost | about $296 | R13 ($400) met; `budget_usd` unchanged |

Requirements not met or at risk:

- **R6 (verticality warning) not met:** the concept has no tilt sensing on the rod.
- **R2 (depth ±1 mm) at risk:** a low-cost draw-wire reel may reach only about ±2 mm.
- **R3 (blow detection) and R11 (shock) at risk:** the Hall sensor pad sits on the anvil.
- **R9 (test time) at risk:** depends on the extraction method, which is open.

### Proposed, awaiting Amish

Status update: items 1 to 8 were Decided by Amish, 2026-09-25: go with recommendation (CNP-DDR-001, D1 to D8). Item 9 has no recommendation and remains Proposed, awaiting Amish.

1. **Verticality (R6).** (a) accelerometer in the anvil sensor pad; (b) bubble level on the handle; (c) accept no tilt sensing. Recommendation: (a) with (b) as a backup.
2. **Rod extraction.** (a) optional lever or farm jack with a rod clamp, about $40 to $60, carried separately; (b) upward hammer blows; (c) two-person pull. Recommendation: (a), outside the BOM total. Adding it would bring parts to about $336 to $356, still within budget.
3. **Complete instrument or also a retrofit sensor kit** for existing 16 mm ASTM DCPs (about $86 of sensing and logging parts). Recommendation: design the sensor set to fit standard DCPs and build the complete instrument for the prototype. This widens the pitch slightly; `project.yaml` is unchanged.
4. Depth sensing by draw-wire referenced to a ground plate, with a laser time-of-flight sensor as the fallback.
5. Standard 8 kg hammer geometry rather than the 4.6 kg option.
6. Blow detection by Hall sensor with a depth cross-check.
7. Electronics on the plate rather than on the rod.
8. Three AA cells rather than a lithium-ion cell.
9. First co-design partner and user group.

`project.yaml` pitch and problem were left unchanged: the findings do not make them wrong. The problem line says "soil bearing data"; the docs make clear ConePro gives a strength index and indicative CBR, not allowable bearing pressure.

### Safety concerns

- Buried services struck by the rod: utility locate before every test.
- Crushed fingers between the 8 kg hammer and the anvil or clamp arm (about 45 J per blow).
- Chipping and mushrooming of hardened steel faces: eye protection and face inspection.
- Impact noise (level not estimated) and back strain from lifting and extraction.
- Misuse of indicative CBR results for foundation design.

### Problems and gaps against the brief

- **Sources not checked online.** Web search was unavailable in this session (search budget used up and page fetches blocked), so prior work is cited from the literature by author, title and report number, with a link only for ASTM D6951. Commercial prices for instrumented penetrometers were not checked and are described only qualitatively. Confirm all citations at TRL 3.
- The legacy `cad/src/model.py` placeholder is untouched (TRL 3 work).

### Recommended next step

Review this note and the media, then decide items 1 to 3. If approved, run `/advance-trl3` to calculate the draw-wire error budget, anvil shock, blow energy transfer and mass roll-up, and to produce the parametric model and drawing sheet.

## Session 2026-09-25: TRL 3

Amish approved the TRL 2 review on 2026-09-25 ("proceed with all of your recommendations across all batches. Make sure we don't proceed to TRL 4 on any of them."). This session ran `/advance-trl3` and stopped at TRL 3.

### What was done

- `docs/decisions/0001-trl2-review-decisions.md` (CNP-DDR-001 v0.1): the eight TRL 2 items with a recommendation recorded as "Decided by Amish, 2026-09-25: go with recommendation" (D1 to D8); the co-design partner (O1) left open.
- `docs/04-calcs/01-sizing.md` (CNP-CAL-001 v0.1) and `docs/04-calcs/sizing.py`: geometry, blow energy, mass, range, draw-wire error budget, tilt error, wire slack dynamics, magnet field, shock, tilt, storage, test time, extraction force, power and cost, with a results table for R1 to R15. The script imports the model and the BOM and prints every number the note quotes.
- `cad/src/model.py`: parametric build123d model (ASTM geometry, derived hammer length and upper rod, plate, reel, clamp and arm, band-clamped sensor pad, logger, cable). Exports `cad/step/` and `cad/stl/` for `conepro-assembly`, `hammer-assembly`, `drive-train` and `sensor-set`.
- `cad/src/sheets.py` and `cad/drawings/CNP-DWG-001.svg`, `.pdf`, `.png`: general arrangement at Rev P1, front, top and right views at 1:20, detail A (anvil, sensor pad and clamp) at 1:5, isometric view and a dimension table, marked "CONCEPT, NOT FOR FABRICATION" and "PRELIMINARY, NOT FOR FABRICATION". The concept sheet keeps CNP-DWG-010, so DWG-001 was free.
- `bom/bom.csv`: 15 lines, all priced, with supplier types; `bom/bom-notes.md` updated.
- `cad/src/concept_media.py` now renders from `model.py`; `media/` refreshed (hero, blueprint, exploded, flow with the new energy split, GLB and viewer). All images were inspected; no `media/_views*` folders remain.
- CNP-PRB-001, CNP-PRC-001 and CNP-REQ-001 revised to v0.3; `project.yaml` at `trl: 3`, `trl_target: 3` with the evidence files; `README.md` updated. Pitch, problem and `budget_usd` ($400) unchanged, since the review recommended no change to them.
- Citations checked online: ASTM D6951 geometry and the CBR correlations, Scala (1956), Webster, Grau and Williams (GL-92-3, DTIC ADA251960), ORN 8 and PANDA were confirmed. Kleyn's report number was wrong (L2/74); it is L2/75, now corrected. The ORN 8 title and publisher (TRRL) were corrected. Scala's volume and issue number were not confirmed. Commercial prices for instrumented penetrometers are still unchecked.

### Requirements summary (CNP-CAL-001)

7 met, 2 at risk, 2 not met, 4 not verifiable at TRL 3.

| ID | Status | Key number |
| --- | --- | --- |
| **R5** | **Not met** (1,000 mm clause) | 938 mm stroke, 850 mm usable; no extension rod in the BOM |
| **R10** | **Not met** (total mass) | 16.7 kg carried in the bag against 16 kg; heaviest piece 9.8 kg and packed length 1.08 m are met |
| R2 | At risk | Bench error ±0.98 mm worst case, ±0.49 mm RSS against ±1 mm; a 2 degree lean adds up to 1.8 mm at 850 mm |
| R11 | At risk | About 1,400 to 5,400 g mean at the anvil; about 533 g on the isolated pad; cable and connector fatigue not calculated |
| R1, R4, R6, R8, R9, R12, R13 | Met | 8.00 kg and 575 mm; record at 0.21 s; tilt ±0.3 degree; 830 tests; 8.1 to 11.7 min; 40 h; $321 |
| R3, R7, R14, R15 | Not verifiable at TRL 3 | Blow sequence, app and retrofit fit need hardware |

Other findings: about 27.6 J reaches the cone, not 33 J as estimated at TRL 2; the impact at the anvil is thousands of g, not hundreds; the draw-wire goes slack for 5 to 36 ms after each blow, and with a rigid eye the snap tension could reach 291 N at 50 mm per blow, near or above the breaking load of the wire.

### Decisions recorded (CNP-DDR-001)

D1 accelerometer tilt sensing with a bubble level backup; D2 optional lever extraction, outside the BOM total; D3 sensor set designed to fit standard DCPs, complete instrument for the prototype; D4 draw-wire depth with a time-of-flight fallback; D5 standard 8 kg geometry; D6 Hall blow detection with cross-checks; D7 electronics on the plate; D8 three AA cells. The SwapCell cross-cutting decisions do not apply (ConePro uses AA cells).

### Proposed, awaiting Amish

Status update: items 2 to 5 are now Decided by Amish, 2026-09-25: go with recommendation (CNP-DDR-002, D9 to D12; see the next session). Item 1 has no recommendation and remains Proposed, awaiting Amish.

1. **First co-design partner and user group (O1).** No recommendation; to be picked per area later.
2. **R10 mass (new).** (a) a 0.40 kg bag, an aluminum clamp and arm, and a 6 mm plate, giving about 15.7 kg; (b) redefine R10 to exclude the bag (15.9 kg); (c) relax R10 to 17 kg. Recommendation: (a).
3. **R5 extension rod (new).** (a) add a 500 mm extension rod (about $15, 0.79 kg; total 16.4 kg even with item 2a, so R10 fails again); (b) relax R5 to 850 mm per rod and offer the extension rod as a separately carried accessory; (c) a longer lower rod (breaks the 1.1 m packed length). Recommendation: (b).
4. **Draw-wire reel details (new).** A metal single-layer grooved drum, a groove keeper and a preloaded eye spring (8 N, 2 N/mm), already in BOM line 8, and a usable range of 850 mm because of the tilt error near the end of the stroke. Recommendation: accept; the alternative is the bought industrial draw-wire sensor at higher cost.
5. **Stiff ground extraction (new).** The upper bound on the pull force is 5.5 kN at 5 mm per blow, beyond the 3 kN lever. Recommendation: note the disposable-cone practice for stiff ground in the user guidance; no hardware change now.

### Safety concerns

- Buried services struck by the rod: utility locate before every test.
- Crushed fingers between the hammer and the anvil; the sensor pad sits 8 mm under the hammer overhang, a new pinch point.
- Chipping and spalling of hardened steel faces under impacts of thousands of g: eye protection and face inspection.
- Strong magnets in the hammer (implanted medical devices) and a draw-wire that can whip if it breaks.
- Impact noise (level not estimated), back strain from lifting, and extraction forces that can exceed 3 kN in stiff ground.
- Misuse of indicative CBR results for foundation design.

### Problems and gaps

- No existing TRL 4 material was found (no tests, build procedures or firmware); `build-log/README.md` is the scaffold only.
- R3, R7, R14 and R15 cannot be shown on paper. The magnet field ignores the steel hammer, and the restitution, isolator and wire-stretch values are assumptions.

### Recommended next step

TRL 4 is on hold by Amish's instruction; do not start it. The next step is for Amish to decide items 1 to 5 above, after which CNP-REQ-001 and the BOM can be revised within TRL 3. For the record, TRL 4 would need: a bench build of the instrument, a test plan and report (TST, `environment: lab`) covering the draw-wire error against a steel rule, a 200-blow detection sequence, a 10,000-blow drop count on the sensor pad, tilt accuracy, battery life and timed trials, a firmware and app sketch, and build log entries.

## Session 2026-09-25: recommendations accepted

Amish wrote on 2026-09-25: "i accept all your recommendations, go with them across all repos." Every open item with a recommendation is now Decided by Amish, 2026-09-25: go with recommendation, recorded in `docs/decisions/0002-recommendations-accepted.md` (CNP-DDR-002 v0.1). The work stayed at TRL 3.

### Decisions applied and what changed

| # | Decision | Before | After |
| --- | --- | --- | --- |
| D9 | R10 mass, option (a): 6 mm plate, aluminum clamp and arm, 0.40 kg bag | 16.7 kg carried (plate 1.72 kg, steel clamp 0.34 kg, bag 0.80 kg); R10 not met | 15.7 kg carried (plate 1.29 kg, aluminum clamp 0.12 kg, bag 0.40 kg); R10 met, thin |
| D10 | R5, option (b): 850 mm per rod, extension rod as a separate accessory | R5 required 1,000 mm with an extension rod; no rod in the BOM; not met | R5 restated to 850 mm per rod; BOM line 16, optional 500 mm rod ($15, 0.79 kg); met |
| D11 | Draw-wire reel details and 850 mm usable range | Proposed | Accepted; BOM line 8 unchanged |
| D12 | Stiff-ground extraction: disposable-cone practice in user guidance | Proposed | Stated in CNP-PRC-001 (How it works, Safety); no hardware change |

Knock-on numbers from CNP-CAL-001 v0.2: instrument cost $321 to $319 (kit with lever and extension rod $384); stroke 938 to 940 mm; driven mass 5.35 to 5.12 kg; energy at the cone 27.6 to 28.0 J; isolated pad peak 533 to 543 g; `budget_usd` stays $400 (no change was recommended).

Files changed: `cad/src/model.py` (plate 6 mm, aluminum clamp), `cad/step/`, `cad/stl/`, `cad/src/sheets.py` and `cad/drawings/CNP-DWG-001.*` (Rev P1 to P2), `cad/src/concept_media.py` and `media/`, `docs/04-calcs/sizing.py` and CNP-CAL-001 v0.2, CNP-REQ-001 v0.4, CNP-PRC-001 v0.4, CNP-DDR-001 v0.2, new CNP-DDR-002 v0.1, `bom/bom.csv` (16 lines), `bom/bom-notes.md`, `project.yaml` (evidence list only), `README.md`, `docs/pdf/`.

README: added "Concept rationale", "Burning platform", "Where it could be used" and "What sparked the idea" before "Problem". The inspiration point is the Mn/ROAD test road construction in Minnesota (more than 700 DCP tests, two-person crew recording each blow on a form, per the Mn/DOT DCP user guide). `docs/01-problem.md` did not attribute the idea to any review, so it was left unchanged. PDFs, drawings and media were regenerated with the designmolecule.com footer.

### Requirement status (CNP-REQ-001 v0.4)

9 met, 2 at risk, 0 not met, 4 not verifiable at TRL 3 (was 7 met, 2 at risk, 2 not met, 4 not verifiable).

| ID | Status | Key number |
| --- | --- | --- |
| R2 | At risk | Bench ±0.98 mm worst case against ±1 mm; up to 1.8 mm more at 850 mm with a 2 degree lean |
| R11 | At risk | About 543 g at the isolated pad; cable, connector and isolator fatigue not calculated |
| R1, R4, R5, R6, R8, R9, R10, R12, R13 | Met | R5: 850 mm per rod; R10: 15.7 kg; R13: $319 |
| R3, R7, R14, R15 | Not verifiable at TRL 3 | Need hardware or the app |

### Still Proposed, awaiting Amish

1. **First co-design partner and user group (O1).** No recommendation; to be picked per area later.

### Cross-repo actions

None. No ConePro decision needs a change in another repo.

### TRL 4

TRL 4 remains on hold by Amish's instruction. The TRL 4 work these decisions imply (weighing the kit, fitting the extension rod and checking re-zero, stiff-ground extraction trials, plus the bench tests listed in the previous session) is decided in principle but not started.

### Safety

No new hazards. The extension rod adds one more joint to check before driving; the stiff-ground guidance tells the operator to stop rather than force the lever.

## Session 2026-09-26: sources strengthened

Amish asked for the weaker sources in the README to be fixed. Every link kept or added was fetched and checked against the claim. No controlled document changed; `docs/01-problem.md` did not share any of the replaced sources.

| Where | Old source | New source |
| --- | --- | --- |
| Burning platform, subgrade sentence | Uncited claim that most roads to be built are gravel and earth | Rewritten to what Liu et al. (*Earth System Science Data* 18, 267) state: most unpaved roads are dirt |
| Burning platform, lab testing sentence | Uncited claim that CBR testing is slow and far away | Scala (1956) abstract on why road authorities skip strength tests, [TRID record](https://trid.trb.org/View/1194062) |
| Burning platform and United States row | Mn/DOT catalog page (does not carry the quoted text) | Mn/DOT *User Guide to the Dynamic Cone Penetrometer* PDF itself |
| South Africa row | Uncited (Kleyn 1975 report, no online record found) | Row replaced by Peru: Rural Access Index 37.2 %, World Bank *Measuring Rural Access: Update 2017/18* |
| Bangladesh row | World Bank 2017/18 update, plus an uncited claim about embankment roads | Same World Bank report, row limited to what it states (87 % in the 2016 pilot, highest of the pilot countries) |
| Australia row | Informit record alone, plus an uncited claim about unsealed networks | Row reframed as Australia and New Zealand; TRID record of the 1956 conference paper added beside Informit; unsealed-network claim removed |
| What sparked the idea | Mn/DOT guide only, with the I-94 and Albertville location unsupported by it | MnDOT MnROAD page added for the location; "to characterize the pavement foundations" trimmed to "during construction", as the guide states |

The inspiration event (Mn/ROAD construction and the Mn/DOT DCP user guide) is unchanged. No budget change.

## Session 2026-09-26: product appearance model and photoreal renders

Amish chose this repo for the first batch of product renders on 2026-09-26. This session adds an appearance model for photoreal renders; the render images themselves (`media/render-hero.png`, `media/render-exploded.png` and a detail view) are produced later from it.

### What was done

- `cad/src/product_model.py` (new): `product_parts()` returns 52 appearance parts (39 shell, 5 internal, 2 accessory, 6 context), with color, material, BOM line, group and explode offset for each, plus `TITLE` and three `RENDER_VIEWS` (hero, exploded, detail). It imports `PARAMS`, `derived()` and `build_parts()` from `cad/src/model.py`, so every main dimension and interface is unchanged. It adds:
  - filleted and chamfered steel parts: hardened cone, anvil with its coupler seam, top stop collar with its set screw;
  - rod graduations every 10 mm (heavier every 100 mm) on the lower rod;
  - a painted teal drop hammer with bare steel strike faces, six grip grooves, the ring of 16 magnets in the lower face and an "8.0 kg" label patch;
  - a powder-coated T-handle with a tee, ribbed rubber grips and a bubble level with a clear vial;
  - an anodized reference plate with rounded corners, zero-depth ticks round the hole and a nameplate;
  - a two-part draw-wire reel housing with a parting line, lid screws, a clear window onto a grooved drum, the wire exit eyelet and the wire;
  - a split clamp collar with its clamp screw, a filleted wire arm, the wire eye and the preload spring;
  - a potted sensor pad on an elastomer isolator, with the stainless band clamp and its worm housing;
  - a logger box with a parting line, lid screws, a clear lid window onto three AA cells in a holder, a teal button, a lit green status LED, a cable gland and a label;
  - a coiled sensor cable with a strain relief;
  - a spare cone and rubber cone cover (accessory, exploded view only);
  - context: a compact patch of soil with a few pebbles, and a phone lying on the ground showing a penetration curve.
- Self-check previews with the kit's matplotlib renderer (clear parts left out): `/tmp/conepro-prod/prev-hero.png`, `prev-exploded.png`, `prev-detail.png` (scratch files, not in the repo).
- `README.md`: hero image now points to `media/render-hero.png`, and an "Exploded render" link opens the links line.

### Where the appearance model differs from model.py

Each item is Proposed, awaiting Amish.

1. **Draw-wire drum drawn at 48 mm, not 60 mm.** A 60 mm drum (`drum_d`) cannot fit inside the 60 x 56 x 60 mm reel housing (`reel_box`) once it has walls, so the render shows a 48 mm drum. The calculations need the 60 mm drum (0.046 mm per count). Recommendation: keep the 60 mm drum and grow the housing to about 72 x 60 x 72 mm; that raises the reel top by 12 mm and cuts the stroke from 940 mm to about 928 mm, which still clears the 850 mm usable range.
2. **Reel housing and logger lid windows.** Both housings get a clear window so the drum and cells show in the renders. Recommendation: keep them as render features only and use opaque parts in the design unless Amish wants inspection windows, since each window adds a seal to an IP65 box.
3. **Hammer grip grooves and magnet pockets.** Six shallow grooves and 16 magnet pockets change the hammer mass slightly. Recommendation: accept; the BOM already says the mass is trimmed to 8.0 kg, so length is set at machining.
4. **Rubber grips on the T-handle.** Grips of about 33 mm diameter over the 26 mm tube are not in BOM line 6. The overall 260 mm width is unchanged. Recommendation: add grips to the BOM line 6 spec (a few dollars).
5. **Coiled cable path.** The cable keeps the model's end points and bend point but is drawn as a tight coil near the pad and a stretched coil below, and ends in a gland on the logger lid. Recommendation: accept as drawn.
6. **No cable from the reel to the logger.** Neither `model.py` nor the BOM shows how the angle sensor board in the reel reaches the logger, so none is drawn. Recommendation: add a short cable (or a connector on the plate) to BOM line 12 and to the model at the next update.

### TRL

This is an appearance model only: no tolerances, no fabrication detail, nothing past TRL 3. `trl` stays 3, and TRL 4 remains on hold.

## Session 2026-09-27: owner decision applied

Amish asked on 2026-09-27 to "resolve the challenges for ConePro, BridgePulse, Grainguard and WellSense". For ConePro that is item 1 of the 2026-09-26 session: the draw-wire drum drawn at 48 mm because the 60 mm drum did not fit its housing. Decided by Amish on 2026-09-27: keep the 60 mm drum and grow the reel housing to about 72 x 60 x 72 mm, accepting about 12 mm less stroke. Recorded in `docs/decisions/0003-reel-housing-size.md` (CNP-DDR-003 v0.1, new, added to `trl_evidence` in `project.yaml`).

### What changed

- `cad/src/model.py`: `reel_box` 60 x 56 x 60 mm to 72 x 60 x 72 mm. The reel exit point and every other dimension and interface are unchanged.
- `cad/src/product_model.py`: the 48 mm `DRUM_SHOWN` stand-in is removed; the drum is drawn from `drum_d` (60 mm) inside the larger housing, with the drum axis, window, window bezel and lid parting line resized to suit. 52 parts, all valid; no interference between drum and housing.
- `cad/step/`, `cad/stl/` regenerated; `cad/src/sheets.py` and `cad/drawings/CNP-DWG-001.*` Rev P2 to P3; `media/` concept media regenerated (`hero.png`, `concept-blueprint.*`, `exploded.png`, `flow.png`, `model.glb`, `viewer.html`).
- CNP-CAL-001 v0.3 (`docs/04-calcs/01-sizing.md`), CNP-REQ-001 v0.5, CNP-PRC-001 v0.5, `bom/bom.csv` line 8 (housing size stated), `bom/bom-notes.md`, `docs/pdf/` rebuilt.

### Result

- Reel top 66 to 78 mm above the ground. Stroke per lower rod 940 to 928 mm, still limited by the wire arm on the reel housing; the 850 mm usable range holds with a 78 mm margin [D1, D2]. R5 stays met.
- Knock-on from the shorter free wire: lean error at 850 mm after tilt correction 0.94 to 1.07 mm at 1 degree and 1.77 to 2.02 mm at 2 degrees [E4]; rigid-eye snap tension 41 to 283 N became 44 to 304 N, still limited to 9 to 35 N by the preloaded eye spring [E5]. R2 stays at risk.
- Cost ($319), carried mass (15.7 kg) and `budget_usd` ($400) unchanged. Requirement count unchanged: 9 met, 2 at risk (R2, R11), 4 not verifiable at TRL 3.

### Renders

The photoreal renders (`media/render-hero.png`, `media/render-exploded.png`, `media/render-detail.png`) need regenerating: YES, all three views. The reel housing is larger in every view, and the drum is now 60 mm (visible through the window in the hero and detail views and as a separate part in the exploded view). The render images were not regenerated in this session.

### Still Proposed, awaiting Amish

- Items 2 to 6 of the 2026-09-26 session (render-only windows, hammer grooves and magnet pockets, T-handle grips in BOM line 6, coiled cable path, reel-to-logger cable).
- O1: first co-design partner and user group.

### TRL

`trl` stays 3; TRL 4 remains on hold. No fabrication detail was added. No new safety concerns.

## Session 2026-09-27: kit 1.5.0 and image quality

- Kit 1.5.0 synced: STANDARDS v1.5 (sections 12 to 15: product renders, storefront images and image quality, public release, authorship and signing), `.kit/cards.py`, `.kit/image_qc.py`, `.kit/release_gate.py`, issue templates, and the `/render-product` and `/release` commands. `CLAUDE.md` now matches `.kit/CLAUDE.md`.
- Every `media/render-*.png` recaptioned from its original render with the new layout: the title, concept label and repository sit in a band above the render and the view note in a band below it, each line wrapped to the image width, so no text overlaps other text or the render or runs off the image. `media/card.png` and `media/social-preview.png` regenerated with the same rules.
- `python .kit/image_qc.py` and `python .kit/release_gate.py` pass. trl stays 3.

## Session 2026-09-30: design for construction and prototype build plan (kit 1.7.0)

Amish approved the build plan format on 2026-09-30 and asked for it across all repos, with outstanding decisions kept out of the build plan and in a separate design decisions register. He also wrote: "If you are realising that the design cannot be built as per concept - fix the design assumptions to match and be physically feasible as you draw the illustrations." This session applies both to ConePro. `trl` stays 3; nothing was built or bought.

### What was done

- Kit 1.7.0 installed (`.kit/`, `.claude/commands/`); `CLAUDE.md` matches `.kit/CLAUDE.md`.
- `cad/src/model.py` rewritten to a constructable model: `build_components()` gives 39 separate parts and fixing sets; `build_parts()` fuses them into the BOM-numbered parts the calculations, drawing and concept media use; `python cad/src/model.py --check` runs 64 constructability checks (contacts, clearances, and no overlap between any two components). All 64 pass.
- New decision record `docs/decisions/0004-design-for-construction.md` (CNP-DDR-004 v0.1, Draft), made under Amish's 2026-09-30 instruction to make the design physically buildable; open for his review.
- `bom/bom.csv`: specs of lines 1 to 11, 14 and 16 now carry the joints and fixings; line 17 (reel-to-logger cable) added; `bom/bom-notes.md` updated.
- Calculations rerun: CNP-CAL-001 v0.4 (`docs/04-calcs/sizing.py` now also allows for the magnet recess and line 17); CNP-PRC-001 v0.6; CNP-REQ-001 v0.6. No requirement changes status: 9 met, 2 at risk (R2, R11), 4 not verifiable at TRL 3.
- STEP and STL regenerated; general arrangement CNP-DWG-001 Rev P4 to P5; concept media regenerated (`hero.png`, `concept-blueprint.*`, `exploded.png` now with the kit's own numbered callouts, `flow.png`, `model.glb`, `viewer.html`).
- `cad/src/build_plan_media.py` (new): overview, 13 making sketches (CNP-DWG-101 to 113, rods drawn as broken views), 10 joint close-ups, 13 step pictures, a plate hole layout and a block wiring diagram, all from the model.
- `docs/05-build-plan.md` (CNP-BLD-001 v0.1) and `docs/06-design-decisions.md` (CNP-DEC-001 v0.1) written; both added to `trl_evidence`; `design_state: constructable` in `project.yaml`; README links line and "Building the prototype" section added.

### Design changes made for construction (CNP-DDR-004)

1. Cone shoulder 5 to 12 mm, tapped M12 x 1.75, 14 mm deep (cone 29.3 mm overall); instrument 1,867 to 1,874 mm tall.
2. M12 studs on the rod ends and M12 tapped holes 24 mm deep in both anvil faces; every joint seats on a square shoulder.
3. Upper rod runs through the stop collar (6 mm roll pin, drilled at the set drop) and through the T-handle tube (welded); upper rod 776 mm above the anvil plus a 20 mm stud.
4. Bubble level is a 20 mm bullseye in a seat disc welded to the rod top.
5. Sixteen magnet pockets on an 82 mm circle, outside the anvil strike area, magnets 0.5 mm below the face; hammer 136.5 mm long to stay at 8.00 kg.
6. Clamp collar and arm cut in one piece from 12 mm aluminum plate (was a collar with an arm through the rod), with a saw slit and M5 clamp screw; its top now butts the anvil underside (was 4 mm below it), so the anvil carries it at every blow.
7. Sensor pad face curved on a curved 4 mm isolator; the band goes round the anvil and over the pad (it ran through the pad); cable strain relief boss.
8. Reel housing given walls, posts, a bearing boss, a screwed lid, a drum on a shaft in two bearings, a spring motor, shaft magnet and sensor board; the drum's edge is under the wire exit, so the housing centre moved 30.7 mm toward the rod (exit point and housing size unchanged).
9. Reel screwed to the plate from below into heat-set inserts; logger is a flanged box screwed to tapped plate holes.
10. Reel-to-logger cable added (BOM line 17, $6), with glands and two P-clips (closes item 6 of the 2026-09-26 session, subject to Amish's review of CNP-DDR-004).
11. Two M12 glands in the logger end wall for the coiled cable and the reel cable.
12. Wire through the arm eye, preload spring and a crimped end stop drawn.
13. Optional extension rod gets M12 studs and a 20 mm coupling sleeve ($15 to $16).

Knock-on numbers: stroke 928 to 939 mm (850 mm usable unchanged); lean error at 850 mm after tilt correction 1.07 to 0.95 mm (1°) and 2.02 to 1.79 mm (2°); rigid-eye snap tension 44 to 304 N became 42 to 284 N; driven mass 5.12 to 5.09 kg; carried mass 15.7 kg unchanged; heaviest piece 9.83 kg; instrument cost $319 to $335; kit with both optional accessories $401 ($1 over the $400 value-engineering target; instrument $65 under it).

### Proposed, awaiting Amish

All are in `docs/06-design-decisions.md`:

1. Accept CNP-DDR-004 as a whole.
2. Hammer can slide off the upper rod when it is unscrewed from the anvil; recommendation: a screw-on end cap on the stud (adds to the safety case).
3. Carried over: O1 co-design partner; render windows, hammer grip grooves, T-handle grips and coiled cable path (2026-09-26 items 2 to 5).

### Stale images (made on Amish's Mac, not regenerated here)

`media/render-hero.png`, `media/render-exploded.png`, `media/render-detail.png`, `media/card.png` and `media/social-preview.png` are stale: the clamp is now one piece against the anvil, the handle has a seat and bullseye level instead of a block level, the pad sits under its band, the reel housing sits 30.7 mm nearer the rod and the logger has flanges, glands and a second cable. `cad/src/product_model.py` needs the same updates before they are rendered again.

### Safety

No new hazard in the product. The build adds welding (handle) and lathe work on hardened steel, covered by the build plan's safety stops. The packing hazard of the hammer sliding off the upper rod is listed as open decision 2.

### Recommended next step

Amish reviews CNP-DDR-004 and the open decisions in the register. TRL 4 remains on hold; when it is released, the build plan is the starting point for the bench build.

## Session 2026-10-02: open decisions decided

On 2026-10-02 Amish approved every recommendation written for the open decisions: "i approve your recommendations for all 555 open decisions." Nothing was built or tested; TRL 4 remains on hold.

### Decisions recorded

7 decisions moved from "Open decisions" to "Decisions made" in the design decisions register, dated 2026-10-02. Design for construction (CNP-DDR-004) accepted with one exception (no thread locker on the rod, anvil and cone joints) and its item A1 (end cap on the upper rod); a low-volume road agency named as the first co-design partner to approach; render-only windows, hammer grip grooves, T-handle grips and the cable path accepted.

### Documents changed

- `docs/01-problem.md` (CNP-PRB-001 v0.4)
- `docs/02-concept.md` (CNP-PRC-001 v0.8)
- `docs/05-build-plan.md` (CNP-BLD-001 v0.2)
- `docs/06-design-decisions.md` (CNP-DEC-001 v0.3)
- `docs/decisions/0001-trl2-review-decisions.md` (CNP-DDR-001 v0.3)
- `docs/decisions/0002-recommendations-accepted.md` (CNP-DDR-002 v0.2)
- `docs/decisions/0004-design-for-construction.md` (CNP-DDR-004 v0.3)
- `README.md` (not a controlled document)
- `bom/bom-notes.md` (not a controlled document)
- `docs/pdf/`: every controlled document re-rendered.

### Follow-up actions to carry approved decisions into the design

The model, drawings, build plan pictures, BOM quantities and prices, and calculations were not changed in this session. These actions carry the approved decisions into them:

1. Decision 1 (model): Add spanner flats to the rods (and the anvil and cone if needed) in cad/src/model.py so the joints can be tightened with spanners now that no thread locker is used; re-run the constructability checks.
2. Decision 1 (drawings): CNP-DWG-001 and the making sketches of the rods, anvil and cone (CNP-DWG-101 to 104): add the spanner flats; remove any thread-locker note.
3. Decision 1 (pictures): Build plan pictures of joints 1 and 2 and steps 1, 3 and 6: remove any thread-locker callout and show the spanner flats.
4. Decision 2 (model): Model the screw-on end cap for the upper rod's M12 stud and the label position on the hammer.
5. Decision 2 (bom): Add the end cap and the hammer label to BOM line 14 and price them.
6. Decision 2 (calcs): CNP-CAL-001: add the end cap's mass to the packed mass and heaviest-piece checks (R10); a few grams.
7. Decision 2 (pictures): Build plan pictures: show the end cap in step 5 and in the packing stop S6.
8. Decision 5 (drawings): Hammer making sketch: add the grip grooves and the note that the length is set at machining to keep 8.00 kg.
9. Decision 5 (model): Add the grip grooves to the hammer in cad/src/model.py and adjust its length to keep 8.00 kg.
10. Decision 6 (bom): BOM line 6: add rubber grips of about 33 mm diameter and reprice the line.
11. Decision 6 (model): Add the rubber grips to the T-handle in the model and the appearance model.
12. Decision 4 (pictures): At the next render session on Amish's Mac, keep the windows render-only and redraw the renders, card and social preview to the constructable design (clamp, handle, pad and reel position).

### Points found in the review

Raised when the recommendations were written (2026-10-01) and not yet acted on:

- The value-engineering section compares the kit with both optional accessories (USD 401) against the USD 400 target; the like-for-like figure is the instrument at USD 335, USD 65 under.
- The build plan applies medium thread locker to joints that must be undone for packing (upper rod to anvil) and for disposable cones, which conflicts with routine disassembly.
- Renders and appearance model still show the concept clamp, handle, pad and reel position.

## Session 2026-10-02: approved follow-ups carried out

Amish approved on 2026-10-02 that every follow-up action from the open-decision sign-off be carried out ("APPROVED CHANGES, COMPLETE THESE"). Nothing was built or tested; TRL 4 remains on hold.

### Follow-ups

1. Decision 1 (model): done. Spanner flats in `cad/src/model.py`: 17 mm across on the top 10 mm of the cone shoulder (3.4 mm wall left to the tapping drill), 13 mm across and 20 mm long on the lower rod 8 mm above its bottom shoulder, 55 mm across and 17 mm long on the anvil 3 mm above its bottom face (2 mm below the sensor pad). The upper rod has no flats: it is turned by its T-handle. New checks added; 73 checks, 0 failed. STEP and STL regenerated.
2. Decision 1 (drawings): done. CNP-DWG-001 Rev P6 (flats, no thread locker, grooves, grips, end cap in the notes); CNP-DWG-101, 102 and 104 at Rev P2 with the flats and no thread-locker note (CNP-DWG-103, the clamp, has no rod joint and is unchanged).
3. Decision 1 (pictures): done. Joints 1 and 2 and steps 1, 3 and 6 redrawn: no thread locker, flats shown and named.
4. Decision 2 (model): done. `end_cap()` in `cad/src/model.py` (aluminum, 32 mm diameter x 24 mm, tapped M12 21 mm deep, fluted grip); checks for the cap on the stud, the hammer resting on it and the cap 10 mm wider than the hammer bore; `hammer-assembly.step` and `.stl` now show the packed state with the cap. The hammer label is modeled (25 x 50 mm, front face, above the grooves).
5. Decision 2 (BOM): done. Line 14 adds the end cap (about USD 4) and the label (about USD 1): USD 18 to USD 23.
6. Decision 2 (calcs): done. End cap 0.045 kg in the packed and heaviest-piece masses (CNP-CAL-001 v0.6, [C1] to [C4]); packed hammer assembly 810 mm long.
7. Decision 2 (pictures): done. Step 5 shows the end cap going on; a new picture, `docs/05-build-plan/packing-s6.png`, shows it at safety stop S6.
8. Decision 5 (drawings): done. CNP-DWG-105 Rev P2: three grip grooves 6 mm wide and 2 mm deep, length set at machining to keep 8.00 kg, label position.
9. Decision 5 (model): done. Grooves in the model; the derived hammer length grows from 136.5 mm to 138.0 mm to keep 8.00 kg, so the upper rod is 778 mm above the anvil (798 mm cut), the stop collar 713.0 mm and the pin hole 722.0 mm above the shoulder, and the instrument 1,875 mm tall. CNP-DWG-106 and 107 Rev P2 carry the new lengths.
10. Decision 6 (BOM): done. Line 6 adds two closed-end rubber grips about 33 mm across (about USD 3 each): USD 20 to USD 26.
11. Decision 6 (model): done. Grips (33 mm OD, 100 mm long) on the tube ends in `cad/src/model.py`, with fit checks, and ribbed grips in the appearance model; CNP-DWG-108 Rev P2 and joint 5 show them.
12. Decision 4 (renders): not done: the photoreal renders, card and social preview are made on Amish's Mac. The appearance model is ready for it (below).

### Appearance model and render scenes

`cad/src/product_model.py` now builds on the constructable parts of `cad/src/model.py`: the one-piece clamp and arm, the pinned stop collar and welded T-handle with the 33 mm grips, the curved pad under its band, the reel at its constructable position (drum edge under the exit), the flanged logger with its glands, the grooved hammer with its label, the spanner flats, and the end cap lying beside the plate. The windows in the reel lid and logger lid stay render-only, as decided. Views kept: hero, exploded, detail. Scenes exported to `/home/claude/renders/conepro` (one .npz and .json per view and `conepro__jobs.json`). No photoreal images, card or social preview were made.

### Key results

- No requirement changed status: 9 met, 2 at risk (R2, R11), 0 not met, 4 not verifiable at TRL 3.
- R10: carried mass 15.7 kg to 15.8 kg (grips 0.08 kg, end cap 0.04 kg); heaviest piece 9.83 kg to 9.96 kg, **only 0.04 kg under the 10 kg limit**. Any further mass on the hammer assembly breaks R10.
- R13: value-engineering target: USD 400. Estimated cost of the constructable design: USD 346 (USD 54 under the target). The kit with both optional accessories is USD 412 (USD 12 over).
- Small knock-on changes in CNP-CAL-001 from the heavier handle: driven mass 5.14 kg, 27.9 J at the cone, isolated pad peak about 542 g.

### Documents changed

- `cad/src/model.py`, `cad/src/sheets.py`, `cad/src/build_plan_media.py`, `cad/src/concept_media.py`, `cad/src/product_model.py`; `cad/step/`, `cad/stl/`
- `cad/drawings/CNP-DWG-001` Rev P6; `CNP-DWG-101`, `102`, `104`, `105`, `106`, `107`, `108` Rev P2 (others regenerated unchanged)
- `docs/05-build-plan/`: overview, joints 1, 2 and 5, steps 1, 3, 5, 6 and 13, new `packing-s6.png` (all pictures regenerated)
- `media/`: hero, concept blueprint, exploded, flow, model.glb
- `docs/04-calcs/sizing.py` and `docs/04-calcs/01-sizing.md` (CNP-CAL-001 v0.6)
- `docs/03-requirements.md` (CNP-REQ-001 v0.8)
- `docs/02-concept.md` (CNP-PRC-001 v0.9)
- `docs/05-build-plan.md` (CNP-BLD-001 v0.3)
- `docs/06-design-decisions.md` (CNP-DEC-001 v0.4)
- `bom/bom.csv`, `bom/bom-notes.md`, `README.md` (not controlled documents)

### Cross-repo actions

None.

### Safety

The end cap and the hammer label carry decision A1 into the design; safety stop S6 now has its own picture. With no thread locker, the joint check before each test (S4) is the only guard against a joint working loose.

### Recommended next step

Render session on Amish's Mac from the exported scenes (hero, exploded, detail), then card and social preview.

## 2026-10-02: photoreal renders redone on the constructable design

Rendered with Blender Cycles on Amish's Mac from the updated appearance model; captioned with `.kit/photo_caption.py`; `media/card.png` and `media/social-preview.png` regenerated with `.kit/cards.py`. Views: hero, exploded, detail. image_qc passes. Appearance deviations are those logged above as proposed, awaiting Amish.

## 2026-10-03: decisions recorded

Amish decided on 2026-10-03: "TIght Margins - i accept the margins". For ConePro this is the heaviest piece at 9.96 kg against the 10 kg limit of R10 (0.04 kg margin).

- `docs/06-design-decisions.md` (CNP-DEC-001) and `docs/03-requirements.md` (CNP-REQ-001) updated.

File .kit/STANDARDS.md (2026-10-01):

---
doc_id: OHP-STD-001
title: Documentation and drawing standard
project: Open Hardware Portfolio
doc_type: Standard
version: "1.7"
status: Released
date: 2026-09-30
author: Amish Chadha
license: CC-BY-SA-4.0
revisions:
  - version: "1.0"
    date: 2026-09-24
    author: Amish Chadha
    change: First release of the standard
  - version: "1.1"
    date: 2026-09-24
    author: Amish Chadha
    change: Adopt Technology Readiness Levels (section 9) for project maturity
  - version: "1.2"
    date: 2026-09-24
    author: Amish Chadha
    change: Portfolio phase cap (section 10), concept media standard (section 11), CLAUDE.md guardrails
  - version: "1.3"
    date: 2026-09-24
    author: Amish Chadha
    change: Scale figure, interactive 3D viewer and flow diagrams added to concept media; session slash commands
  - version: "1.4"
    date: 2026-09-26
    author: Amish Chadha
    change: Every sheet and render names the project and its GitHub repository; overall dimensions, ISO centre lines and 300 dpi PNG on sheets; titles name the device and view labels state the viewing direction; optional photoreal renders with Blender
  - version: "1.5"
    date: 2026-09-27
    author: Amish Chadha
    change: Product renders (section 12), storefront images and image quality check (section 13), public release and release gate (section 14), authorship, citation and commit signing (section 15)
  - version: "1.6"
    date: 2026-09-29
    author: Amish Chadha
    change: Licensing metadata with REUSE (section 16), Zenodo DOI and Software Heritage archiving (section 17), release gate checks REUSE and a single CITATION.cff license, archive.py
  - version: "1.7"
    date: 2026-09-30
    author: Amish Chadha
    change: Concept and constructable design states; design decisions register (DEC) kept apart from the build plan; prototype build plan (BLD, section 18) with pictures by component is required TRL 3 evidence; every repo targets TRL 3 during the populate phase; build_views.py; /to-trl3 and /build-plan commands
---

# Documentation and drawing standard

Every project in the portfolio uses this standard, so that each precis, write-up and sketch looks the same and carries its own version history. The standard ships as a kit in each repo's `.kit/` folder. The kit version is in `.kit/KIT_VERSION`.

## 1. Document types and IDs

Every controlled document has a unique ID in the form `PRJ-TYP-NNN`.

- `PRJ` is the three-letter project code listed in section 7.
- `TYP` is the document type code from the table below.
- `NNN` is a sequence number within that project and type, starting at 001.

| Code | Type | Typical file |
| --- | --- | --- |
| PRC | Design precis | `docs/02-concept.md` |
| PRB | Problem statement | `docs/01-problem.md` |
| REQ | Requirements | `docs/03-requirements.md` |
| CAL | Calculation or sizing note | `docs/04-calcs/*.md` |
| DDR | Design decision record | `docs/decisions/*.md` |
| BOM | Bill of materials | `bom/bom.csv` |
| DWG | Drawing or sketch sheet | `cad/drawings/*.svg` |
| BLD | Prototype build plan (section 18) | `docs/05-build-plan.md` |
| DEC | Design decisions register (section 18) | `docs/06-design-decisions.md` |
| TST | Test plan or test report (front matter adds `environment: lab` or `relevant`) | `docs/05-tests/*.md` |

Example: `TBK-PRC-001` is the ThermaBrick design precis.

## 2. Revision scheme

| Artifact | While in draft | When released | Change after release |
| --- | --- | --- | --- |
| Documents | 0.1, 0.2, 0.3 ... | 1.0 | 1.1 for minor edits, 2.0 for a design change |
| Drawings | Rev P1, P2 ... (preliminary) | Rev A | Rev B, C ... |

- Every change to a controlled document adds a row to its revision history before the commit.
- The `version` field in front matter always equals the newest row in `revisions`. The renderer rejects a document where they differ.
- Status is one of `Draft`, `In review`, `Released` or `Superseded`. Draft and In review documents print with a status band on every page.
- Every release is tagged in Git as `<doc_id>/v<version>`, for example `TBK-PRC-001/v1.0`. Drawings are tagged `TBK-DWG-001/revA`.
- Git history is the full audit trail. The in-document revision table is the human-readable summary.

## 3. Document front matter

Every Markdown document under version control starts with this block:

```yaml
---
doc_id: TBK-PRC-001
title: ThermaBrick design precis
project: ThermaBrick
doc_type: Precis
version: "0.1"
status: Draft
date: 2026-09-24
author: Amish Chadha
license: CERN-OHL-S-2.0
revisions:
  - version: "0.1"
    date: 2026-09-24
    author: Amish Chadha
    change: Initial draft
---
```

Quote version numbers so YAML keeps `1.0` as text instead of turning it into a number. List revisions newest last.

## 4. Writing style

- Chicago Manual of Style.
- No em dashes. Restructure the sentence instead.
- Lead each section with its conclusion, then support it.
- SI units throughout, in the form `12 kW`, `450 °C`, `3.2 m`. Imperial values may follow in parentheses.
- Number every figure and table ("Figure 2", "Table 1") and give each a caption.
- State every assumption in the calculation that depends on it.
- Put safety notes in a blockquote starting with **Safety:**.

## 5. Visual identity

| Element | Specification |
| --- | --- |
| Typeface | IBM Plex Sans for text, IBM Plex Mono for code and values (SIL Open Font License, bundled in `.kit/fonts`) |
| Ink | `#111827` |
| Secondary text | `#4B5563` |
| Rules and grid | `#D1D5DB` |
| Accent (one only) | `#0F766E` teal |
| Document page | US Letter, 20 mm margins |
| Drawing sheet | ANSI B landscape (431.8 x 279.4 mm) |
| Footer | Document ID, version, status, license and designmolecule.com on every page |

## 6. Drawing and sketch conventions

- Units are millimeters unless the title block says otherwise.
- Third-angle projection, marked with the symbol in the title block.
- Line weights: visible outlines 0.5 mm, hidden lines 0.25 mm dashed, center lines 0.18 mm chain.
- The title block contains the project, title, drawing number, revision, scale, units, projection, sheet, author, date, material or notes, and license.
- Every sheet and every render names the project and its GitHub repository (from `repo:` in `project.yaml`), at the top of the sheet and in the title block, so a printed or forwarded sheet is never anonymous.
- The drawing title names the device, not only the drawing type (for example "Handheld near-infrared resin scanner: general arrangement").
- Every view label states its scale and viewing direction (for example "Scale 1:1; side elevation looking along +Y"), and every isometric or render states where it is seen from.
- Orthographic views generated with `add_ortho` carry overall dimensions (length and depth on the top view, height on the front view) and ISO 128 centre lines on cylinders; hidden lines are dashed. Tolerances are not shown before TRL 4.
- Sheets are exported as SVG, PDF and a 300 dpi PNG.
- The revision table in the top right of the sheet lists every revision.
- Concept sketches use the same sheet and title block and carry the label "CONCEPT, NOT FOR FABRICATION".
- Geometry comes from `cad/src/*.py` (build123d). Sheets are generated by `.kit/drawing.py` and never edited by hand.

## 7. Project codes

| Code | Project | Code | Project | Code | Project |
| --- | --- | --- | --- | --- | --- |
| TBK | ThermaBrick | PCF | PicoFlow | HLT | HelioLite |
| CCB | CharCube | DRN | DustRunner | TRT | TremorTrace |
| STC | StepCue | FXH | FlexHand | CPD | ColdPod |
| SCL | SunClave | STR | SteamRoot | GGD | GrainGuard |
| SDL | SeedLine | ZBX | ZeerBox | RMS | RootMesh |
| DWD | DewDrive | SSK | StillStack | PPR | PotPress |
| WWT | WaterWatch | LMF | LumaFlow | FCL | FieldCell |
| CNP | ConePro | CVC | CulvertCrawl | EGD | EmberGuard |
| SNF | SnapFrame | CGM | CargoMule | SCM | StepClimber |
| SWC | SwapCell | PLP | PalletPilot | FTK | FlatTrike |
| WWK | WaterWalker | GRR | GrowRider | SSP | SunSpoke |
| SGN | StepGen | PBX | PowerBox | WML | WasteWise-ml |
| WSC | WasteWise Scan | RFE | ReflowEconomy | | |
| OHP | Portfolio-wide | | | | |

## 8. Build and publish

- `python .kit/render.py` checks every controlled document and renders it to `docs/pdf/<doc_id>_v<version>.pdf`.
- `python .kit/drawing.py` (called from each project's `cad/src/sheets.py`) builds drawing sheets as SVG and PDF in `cad/drawings/`.
- The GitHub Action in `.github/workflows/docs.yml` runs the checks on every push and attaches PDFs to a GitHub Release whenever a release tag is pushed.
- Public releases follow section 14: `python .kit/release_gate.py` must pass, and the release tag is `v0.<TRL>.0` (for example `v0.3.0` at TRL 3).

## 9. Technology Readiness Level (TRL)

Each project states its maturity as a Technology Readiness Level on the NASA and US DOE 1 to 9 scale. The TRL rates this specific design, not the underlying technology. A sand battery is commercial elsewhere, but a new sand battery design starts at TRL 2 until evidence shows otherwise.

| TRL | Definition | Evidence the repo must contain |
| --- | --- | --- |
| 1 | Basic principles observed | Problem statement (PRB) |
| 2 | Technology concept formulated | Draft precis (PRC) and requirements (REQ) |
| 3 | Analytical or experimental proof of concept | Calculation note (CAL), working build123d model with STEP export, drawing sheet (DWG), priced BOM with every unit cost filled in, prototype build plan (BLD) with pictures, `design_state: constructable` |
| 4 | Components validated in the lab | Test report (TST) with `environment: lab`, build log entries |
| 5 | Validated in a relevant environment | Test report (TST) with `environment: relevant` |
| 6 | System prototype demonstrated in a relevant environment | Precis at version 1.0 or later with status Released, a drawing at a lettered revision (Rev A or later), and a system-level TST with `environment: relevant` |
| 7 to 9 | Operational demonstration through proven in service | Beyond portfolio scope; claim only with a named deployment partner and evidence |

Rules:

- `project.yaml` records `trl` (current level), `trl_target` (the level the current effort aims for) and `trl_evidence` (the files that support the claim).
- `python .kit/render.py --check` fails if the evidence for the claimed TRL is missing. CI runs this check on every push.
- Documentation alone cannot go past TRL 3. TRL 4 and above require hardware and a test report.
- TRL and visibility are independent. A repo can be public at TRL 3 as a documented design ready to build.
- A change of TRL is recorded in the build log with the date and the evidence that justified it.

## 10. Portfolio phase and TRL cap

`.kit/PHASE.yaml` sets the current phase. During the **populate** phase every repo is capped at **TRL 3**: `trl` and `trl_target` may not exceed 3, and the check fails if they do. Every repo targets the cap: `trl_target` must equal 3, so a new repo is taken all the way to TRL 3 (scaffold, populate and advance, see `/to-trl3`). Work that belongs to TRL 4 or later (building or testing hardware, test articles, test plans and reports, build-log entries, purchasing lists, PCB layouts) must not be started. The prototype build plan (BLD, section 18) is TRL 3 paper work and is required. Where it already exists it is kept, flagged in the check output, and not extended. Only Amish changes `PHASE.yaml`.

Every repo carries a `CLAUDE.md` with the working rules for AI sessions: the TRL cap, decision rights (nothing is recorded as decided unless Amish decided it), one step per session, and a mandatory `docs/REVIEW.md` before stopping.

## 11. Concept media

Every repo at TRL 2 or above explains its idea visually. Media are generated from a build123d massing model with `.kit/concept.py`, never drawn by hand, so they stay in step with the design.

| File | Required | Purpose |
| --- | --- | --- |
| `media/hero.png` | TRL 2+ | Shaded isometric render with a 1.75 m person for scale; the website card image |
| `media/concept-blueprint.png` and `.pdf` | TRL 2+ | Blueprint concept sheet: orthographic and isometric views, scale, key figures, title block |
| `media/model.glb` and `media/viewer.html` | TRL 2+ | Interactive 3D viewer (glTF plus model-viewer) for the website |
| `media/cutaway.png` | When the inside matters | Section view showing internal parts |
| `media/exploded.png` | Recommended | Exploded view with numbered callouts matching the BOM |
| `media/flow.png` | When energy or material moves | System, energy or material flow diagram with losses |

Session commands in `.claude/commands/` (`/populate`, `/advance-trl3`, `/rein-in`, `/refresh-media`) carry the standard prompts, so every Claude Code session starts from the same instructions.

At TRL 2 a massing model is enough: correct overall proportions and main components. All concept media carry "CONCEPT, NOT FOR FABRICATION". The check warns when required media are missing at TRL 2 and fails at TRL 3.

## 12. Product renders

Every repo at TRL 3 shows the product as it would look, not only as a massing model.

- `cad/src/product_model.py` is the appearance model. It defines `product_parts()` (named parts with a shape and a material), `TITLE` ("Name: what it is") and `RENDER_VIEWS`. It is for renders only: every main dimension comes from `cad/src/model.py`, never typed in again.
- Where the appearance model departs from `model.py` (a chamfer, a label, a fastener drawn for realism), record the deviation in `docs/REVIEW.md` as "Proposed, awaiting Amish".
- Scale comes from context, not from a floating figure: a hand or forearm for handheld objects, and the posed mannequin (`mannequin()` in `.kit/context_parts.py`: stand, walk, push, ride, sit, reach) for anything a person uses at body scale.
- Renders are made with `.kit/export_views.py` (one scene per view) and `.kit/photoreal.py` (Blender Cycles), then captioned with `.kit/photo_caption.py`. Files are `media/render-<view>.png`; `media/render-hero.png` is required.
- Every caption names the project, the repository and the viewing direction, and carries "CONCEPT, NOT FOR FABRICATION".
- Captions never sit on the render. `.kit/photo_caption.py` adds a header band (title, concept label, repository) above the render and a footer band (view note) below it, wraps every line to the image width, and steps the font down to a floor before adding a line.
- The README opens with `media/render-hero.png`.
- Software-only and scene repositories (no single product) may use a scene render as the hero instead of a product model.

## 13. Storefront images

Two images, both made from `media/render-hero.png` by `python .kit/cards.py .`:

| File | Size | Purpose |
| --- | --- | --- |
| `media/card.png` | 800 x 800 | Square thumbnail for the organization profile page |
| `media/social-preview.png` | 1280 x 640, under 1 MB | GitHub social preview, shown when a repository link is shared |

- The social preview shows the area, name, one-line description, the first sentence of the pitch, the brand line and the repository address. Design Molecule repos read "Design Molecule · open hardware concept, TRL n"; OpenRatio repos read "OpenRatio · research and educational prototype, TRL n".
- GitHub has no API for the social preview. Upload it under the repository's Settings, Social preview, on release day.
- Regenerate both images whenever `render-hero.png` changes.

### Image quality

Every render, card and social preview must be clear and readable. `python .kit/image_qc.py` checks each one, and the release gate blocks on any failure:

| Check | Rule |
| --- | --- |
| Layout | Made by the current `photo_caption.py` or `cards.py`, which store the text layout in the PNG |
| Text inside the image | Every line at least 1.2 % of the image width from each edge; nothing runs off the side |
| No overlap | No line of text touches another line, and no caption text sits on the render |
| Text size | Render captions at least 1.05 % of the image width in pixel height (17 px at 1600 px); social preview text at least 16 px |
| Resolution | Renders at least 1200 px wide; card 800 x 800; social preview 1280 x 640 and under 1 MB |
| Sharpness | The render is not blurred or upscaled (edge sharpness at least 15 on the `image_qc.py` scale) |

Long titles and notes wrap to more lines rather than shrinking below the floor. The social preview shortens the pitch sentence with an ellipsis only if it cannot fit at the smallest size.

## 14. Public release

A repository goes public only when Amish approves it, and only after `python .kit/release_gate.py` passes. The gate checks:

1. `render.py --check` passes (document control, TRL cap, concept media).
2. Storefront: hero render, card, social preview under 1 MB, README leading with the hero, and every image passing the image quality check (section 13).
3. Issue templates in `.github/ISSUE_TEMPLATE/`: question, build report, design suggestion. The build report template restates that the design is a TRL 3 concept, not released for fabrication (OpenRatio: a research and educational prototype, not a medical device).
4. `CITATION.cff` valid, with an author ORCID.
5. License files match `project.yaml`.
6. No em dashes in the repository's own text.
7. BioMedical and OpenRatio repos use soft, non-clinical wording: "research and educational prototype, not a medical device".
8. No secrets anywhere in the history (gitleaks).
9. No links to sibling repositories that are still private.
10. REUSE files present (`REUSE.toml`, `LICENSES/`, `.github/workflows/reuse.yml`) and `reuse lint` passes (section 16).
11. `CITATION.cff` names exactly one license, because Zenodo rejects a list (section 17).

It warns, without blocking, when the README lacks a Safety heading or a "not for fabrication" statement, when `CITATION.cff` has no DOI yet, and when the README lacks the Zenodo DOI, REUSE or Software Heritage badge, so a person can confirm.

On release day, per repository:

- A signed, annotated tag `v0.<TRL>.0` on `main`.
- A GitHub release with short notes (what it is, TRL, status, licenses, how to cite) and a design pack, `<repo>-v0.<TRL>.0-design-pack.zip`, holding `cad/step`, `cad/drawings`, `docs/pdf`, `bom`, README, licenses and `CITATION.cff`.
- Description from the first sentences of `pitch` (350 characters at most), website `https://designmolecule.com` (OpenRatio: `https://openratio.ai`), topics from `project.yaml`.
- Before the first release, the repository is switched on in Zenodo (section 17), so the release is archived and gets a DOI.
- Visibility switched to public last, after the release exists.
- The social preview uploaded and the organization profile updated with the new cards.
- After the release: the concept DOI written to `CITATION.cff` and a Software Heritage save requested (section 17).

The internal working files (`CLAUDE.md`, `.kit/CLAUDE.md`, `.claude/commands/`, `docs/REVIEW.md`) stay public, and open "Proposed, awaiting Amish" items stay visible as open questions (Amish, 2026-09-27).

## 15. Authorship, citation and signing

- Amish Chadha is the author of every design, ORCID 0009-0000-8079-7141. Commits are authored as Amish Chadha <amish@designmolecule.com>.
- `CITATION.cff` lists Amish (with ORCID) first, then any credited contributors; `CONTRIBUTORS.md` and the README Credits section agree with it.
- `CITATION.cff` names one license: the hardware license (CERN-OHL-S-2.0), or the software license in a software-only repository. The full split between hardware and software licenses lives in `REUSE.toml` and the README. Once the repository is archived, `CITATION.cff` carries the concept DOI in `doi:`.
- Work done with Claude carries the trailer `Co-Authored-By: Claude <noreply@anthropic.com>` (with the model name), and the README Credits section says designs are developed with AI assistance.
- Every commit and tag pushed to GitHub is signed with Amish's SSH signing key, so GitHub shows it as Verified. Commits prepared elsewhere are re-signed on Amish's Mac before they are pushed.
- Once a repository is public, its history is never rewritten.

## 16. Licensing metadata (REUSE)

Every file states its copyright and license in a machine-readable way, following the REUSE Specification 3.3 (https://reuse.software). A repository is set up with:

```
python .kit/archive.py reuse
```

This writes three things and adds the REUSE and Software Heritage badges to the README badge line:

- `REUSE.toml`, built from the licenses in `project.yaml`. Everything is under the hardware license by default. Scripts, firmware, notebooks, web viewers, workflows and agent commands are under the software license. `cad/` and `electronics/` stay under the hardware license even where they are written as Python. The bundled IBM Plex fonts are OFL-1.1 (IBM Corp.). Copyright is "<first commit year> Amish Chadha".
- `LICENSES/`, with the full text of each license used (`reuse download`). The root `LICENSE` and `LICENSE-SOFTWARE` files stay for GitHub's license detection.
- `.github/workflows/reuse.yml`, which runs the REUSE check (fsfe/reuse-action) on every push and drives the README badge.

A new kind of file that falls outside these rules gets a new annotation in `REUSE.toml` rather than a header comment. `reuse lint` must pass before every commit that adds files, and the release gate enforces it.
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

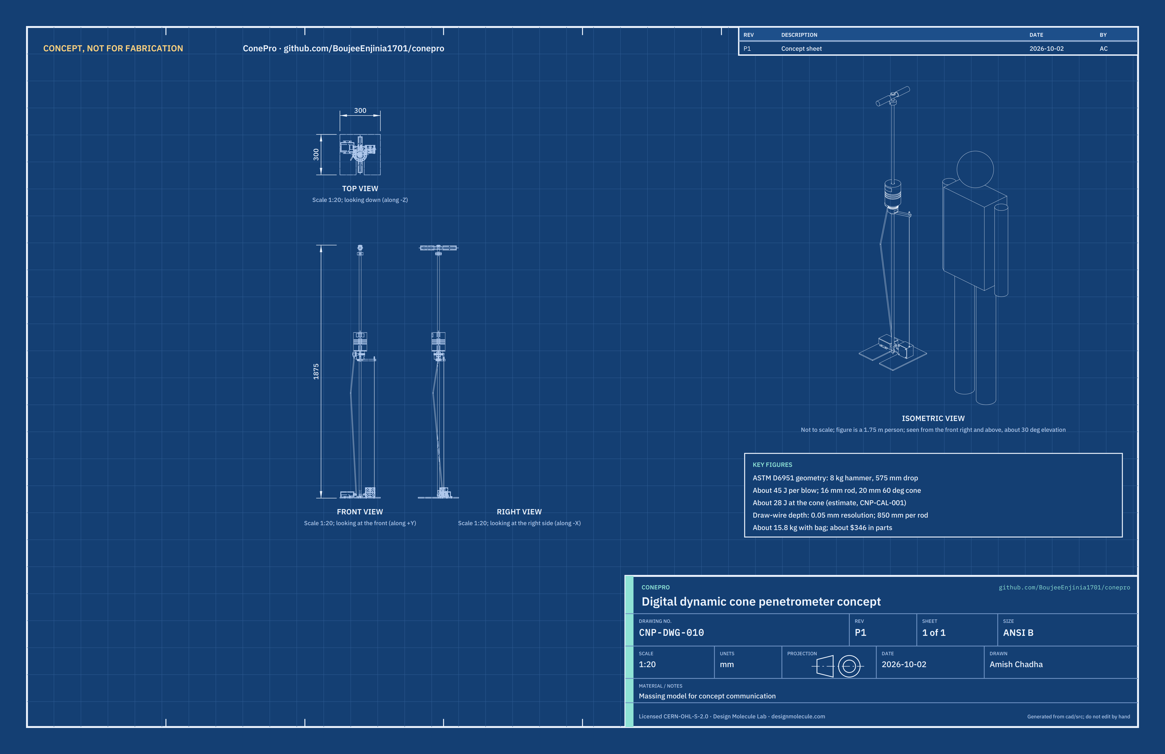
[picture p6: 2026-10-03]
media/concept-blueprint.png

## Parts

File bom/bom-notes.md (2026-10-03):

# BOM notes

- Costs are indicative USD prices for one prototype, estimated in September 2026 without supplier quotes. Every line is priced.
- Line numbers 1 to 12 and 17 match the exploded-view callouts in `media/exploded.png`. Lines 13 to 16 have no callout.
- Instrument total (lines 1 to 14 and 17): $346 against the $400 value-engineering target in `project.yaml` (a hypothetical control target; R13 within the target). Checked by `docs/04-calcs/sizing.py` [L1].
- Line 15, the rod extraction lever ($50), and line 16, the 500 mm extension rod with its coupling sleeve ($16), are optional and carried separately (CNP-DDR-001, D2; CNP-DDR-002, D10), so they are excluded from the instrument total and the R10 carried mass. With both the kit is $412, $12 over the value-engineering target; see the Value engineering section of the design decisions register (`docs/06-design-decisions.md`).
- TRL 3 changes: accelerometer and isolator added to the sensor pad (line 10, D1) with a band clamp instead of an anvil pocket (D3); bubble level on the handle (line 6, D1); magnets specified in the hammer (line 4); grooved aluminum drum, groove keeper and preloaded eye spring on the draw-wire reel (line 8, CNP-CAL-001 section E); optional lever (line 15, D2).
- DDR-002 changes (Amish, 2026-09-25): 6 mm plate, $28 to $24 (line 7); aluminum clamp and arm, $8 to $10 (line 9); 0.40 kg nylon roll bag instead of a 0.80 kg canvas bag, price unchanged (line 13); optional extension rod added (line 16). Instrument total $321 to $319; carried mass 16.7 kg to 15.7 kg.
- DDR-003 change (decided by Amish on 2026-09-27): the printed reel housing on line 8 grows from 60 x 56 x 60 mm to about 72 x 60 x 72 mm so the 60 mm drum fits with walls. The extra printed plastic is a few grams and a few cents, so the line price ($35) and the 0.30 kg reel mass estimate are unchanged. Stroke falls from 940 mm to 928 mm; the 850 mm usable range is unchanged.
- Decided on 2026-10-02 (CNP-DEC-001) and priced on 2026-10-02: two closed-end rubber grips about 33 mm across on the T-handle, line 6 $20 to $26 (about $3 each, hardware or tool shop price); a turned aluminum end cap for the upper rod's M12 stud (about $4, a small lathe part) and a printed "fit the end cap" label for the hammer (about $1), line 14 $18 to $23; no thread locker on the rod, anvil and cone joints, which now carry spanner flats (lines 1 to 3; no price change, a few minutes of milling each); hammer grip grooves and length set at machining (line 4, no price change). Instrument total $335 to $346. Mass: grips 0.08 kg and end cap 0.04 kg; carried mass 15.7 kg to 15.8 kg, heaviest piece 9.96 kg (CNP-CAL-001 v0.6).
- Not included: AA cells, the user's phone, and disposable cones for stiff ground (user guidance only, CNP-DDR-002, D12).
- Supplier types are given where no single supplier is known. Machined parts assume a local machine shop.
- DDR-004 changes (design for construction, 2026-09-30, made under Amish's instruction to make the design physically buildable; accepted by Amish on 2026-10-02 with one exception: no thread locker on the rod, anvil and cone joints): specs of lines 1 to 11, 14 and 16 now give the joints, fixings and sizes the build plan uses (M12 studs and tapped holes, magnet pockets, pinned stop collar and welded handle, one-piece clamp, reel internals and inserts, flanged logger box and glands, 20 mm coupling sleeve on the extension rod); line 17, the reel-to-logger cable, added ($6). Prices: line 6 $16 to $20 (welding), line 8 $35 to $38 (bearings, inserts, spring motor), line 14 $15 to $18 (screws, pin, inserts, epoxy), line 16 $15 to $16 (sleeve). Instrument total $319 to $335.

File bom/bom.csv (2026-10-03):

item | qty | spec | supplier | unit_cost_usd | make_buy | notes
1 Hardened cone | 2 | 20 mm base diameter, 60 degree point, 12 mm parallel shoulder (about 29 mm overall), M12 tapped 14 mm deep in the top face, 17 mm spanner flats on the top 10 mm of the shoulder, hardened tool steel (ASTM D6951 geometry); one spare | Local machine shop | 6.00 | make | Indicative price; replace when worn
2 Lower drive rod | 1 | 16 mm steel rod (hardened or 4140 class), 1,000 mm between shoulders, M12 x 12 mm stud turned on the bottom end (cone) and M12 x 20 mm stud on the top end (anvil), 13 mm spanner flats 20 mm long starting 8 mm above the bottom shoulder, engraved every 10 mm | Local machine shop | 25.00 | make | Indicative price; engraving is a manual backup scale and the scale-factor calibration reference
3 Anvil and coupler | 1 | Steel, 64 mm diameter x 60 mm, M12 tapped 24 mm deep in both end faces, 55 mm spanner flats 17 mm long starting 3 mm above the bottom face; no sensor pocket (pad clamps on) | Local machine shop | 20.00 | make | Indicative price
4 Drop hammer | 1 | 8.0 kg steel, 100 mm OD x 22 mm bore x about 138 mm (length set at machining to keep 8.00 kg), three grip grooves 6 mm wide and 2 mm deep at mid-height, a "fit the end cap" label (line 14), with 16 magnets (8 mm x 4 mm, N42) bonded in 8.2 mm pockets on an 82 mm circle in the lower face, 0.5 mm below the face and outside the anvil strike area | Local machine shop or steel stockist | 55.00 | make | Indicative price; mass trimmed to 8.0 kg; magnets about $5 from a magnet supplier
5 Upper rod (hammer guide) | 1 | 16 mm steel rod, about 778 mm plus an M12 x 20 mm stud on its bottom end, 6 mm cross hole for the stop collar pin; runs through the T-handle tube to the level seat, giving a 575 mm free drop to the stop collar | Local machine shop | 18.00 | make | Indicative price
6 Handle and top stop | 1 | 26 x 2.5 mm tube T-handle 260 mm wide with a 16 mm cross hole, welded to the upper rod, with two closed-end rubber grips about 33 mm diameter x 100 mm pushed over the tube ends; 44 x 18 mm stop collar fixed by a 6 mm roll pin; 30 x 5 mm level seat disc welded to the rod top; 20 mm bullseye bubble level (D1 backup) | Local machine shop plus hardware shop | 26.00 | make | Indicative price; level about $4; rubber grips about $3 each from a hardware or tool shop (added 2026-10-02); welding by a local shop if needed
7 Reference plate | 1 | 300 x 300 x 6 mm aluminum plate with a 60 mm center hole and a 60 mm slot to lift off around the rod; 4 countersunk holes for the reel, 6 holes tapped M4 for the logger flanges and P-clips | Metal stockist | 24.00 | make | Indicative price; 6 mm to save mass (CNP-DDR-002)
8 Draw-wire depth sensor | 1 | Printed IP65 housing (body and screwed lid, 72 x 60 x 72 mm) with four heat-set M4 inserts, grooved single-layer aluminum drum 60 mm diameter x 20 mm on a 6 mm shaft in two bearings, constant-force spring motor, about 1,000 mm of 0.45 mm coated 7x7 steel wire, groove keeper, exit eyelet, shaft magnet and 12-bit magnetic angle sensor board, preloaded eye spring and wire end stop | Electronics distributor plus local machine shop and print | 38.00 | make | Indicative price; bought industrial draw-wire sensor is the fallback at higher cost
9 Anvil clamp and wire arm | 1 | Aluminum (6061 class) collar and arm cut in one piece from 12 mm plate: 40 mm boss with a 16 mm bore, saw slit and M5 clamp screw, arm 16 mm wide reaching about 115 mm to a 3.2 mm wire eye; the collar butts the anvil underside | Local machine shop | 10.00 | make | Indicative price; aluminum to save mass (CNP-DDR-002)
10 Blow and tilt sensor pad | 1 | Hall-effect switch and 3-axis MEMS accelerometer (rated 10000 g shock) potted in a printed pad with a curved face, on a 4 mm curved elastomer isolator, with a cable strain relief; stainless band clamp (12 mm band) round the anvil and over the pad, for 50 to 80 mm anvils | Electronics distributor | 14.00 | buy | Indicative price; shock survival to be shown at TRL 4
11 BLE logger | 1 | BLE microcontroller module, 4 MB flash, button, LED, three AA cell holder, IP65 box about 100 x 70 x 42 mm with mounting flanges, two M12 cable glands | Electronics distributor | 35.00 | buy | Indicative price; cells not included
12 Coiled sensor cable | 1 | Coiled 6-core cable about 1.2 m extended, with strain reliefs and an IP65 connector | Electronics distributor | 10.00 | buy | Indicative price
13 Carry bag | 1 | Lightweight coated nylon roll bag, about 0.40 kg, for rods, hammer assembly and plate, about 1.08 m long | Outdoor or tool supplier | 30.00 | buy | Indicative price; replaces a 0.80 kg canvas bag (CNP-DDR-002); no exploded-view callout
14 Hardware and consumables | 1 | Thread locker for the screws only (not the rod, anvil and cone joints), epoxy, M4 countersunk and pan-head screws, M5 clamp screw, 6 mm roll pin, heat-set inserts, cone cover, cable ties, spare magnet; aluminum end cap for the upper rod's M12 stud (32 mm diameter x 24 mm, tapped M12 21 mm deep, fluted grip); printed vinyl label for the hammer ("fit the end cap when the rod is off the anvil") | Local hardware shop | 23.00 | buy | Indicative price; end cap about $4 as a small lathe part and label about $1 (added 2026-10-02); no exploded-view callout
15 Rod extraction lever | 1 | Lever rod puller with a self-gripping 16 mm rod clamp and foot plate, about 10:1, rated about 5 kN, about 3 kg | Local machine shop or tool supplier | 50.00 | make | Optional; carried separately; excluded from the R13 instrument total (D2); no exploded-view callout
16 Extension rod | 1 | 16 mm steel rod, 500 mm, M12 x 20 mm stud on each end, engraved every 10 mm, with a 20 mm OD x 40 mm coupling sleeve tapped M12 through, for tests deeper than 850 mm | Local machine shop | 16.00 | make | Optional; carried separately with the lever; excluded from the R13 instrument total and the R10 carried mass (CNP-DDR-002); no exploded-view callout
17 Reel-to-logger cable | 1 | 4-core shielded cable about 0.5 m, 5 mm OD, through M12 glands at both ends, held to the plate by two P-clips | Electronics distributor | 6.00 | buy | Indicative price; added for construction (CNP-DDR-004)

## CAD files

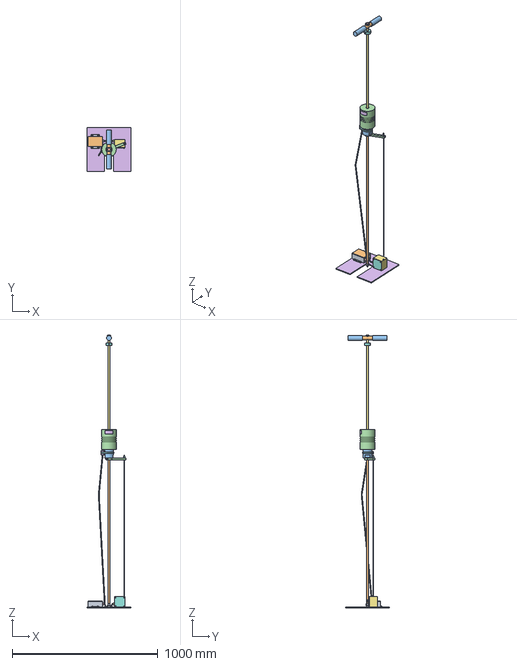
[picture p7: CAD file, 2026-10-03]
cad/step/conepro-assembly.step
300.0 x 300.0 x 1875.3 mm

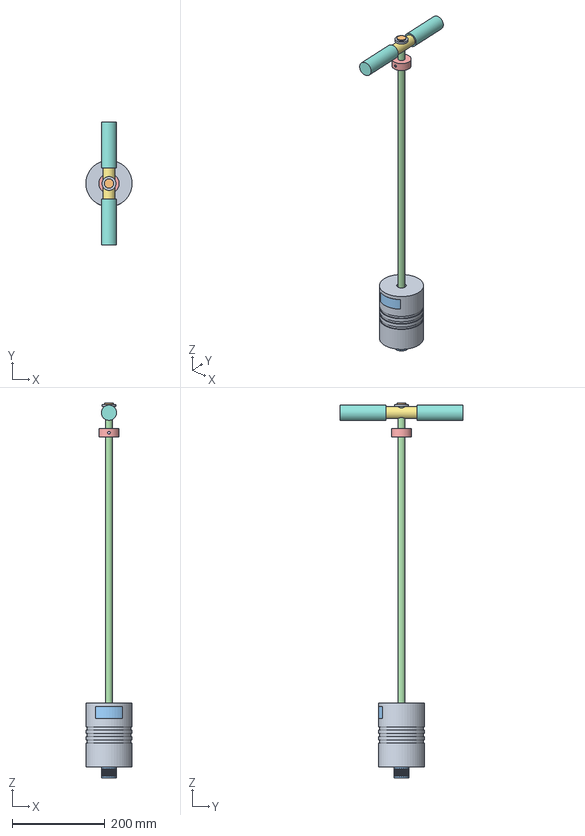
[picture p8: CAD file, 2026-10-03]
cad/step/hammer-assembly.step
99.9 x 266.0 x 810.0 mm

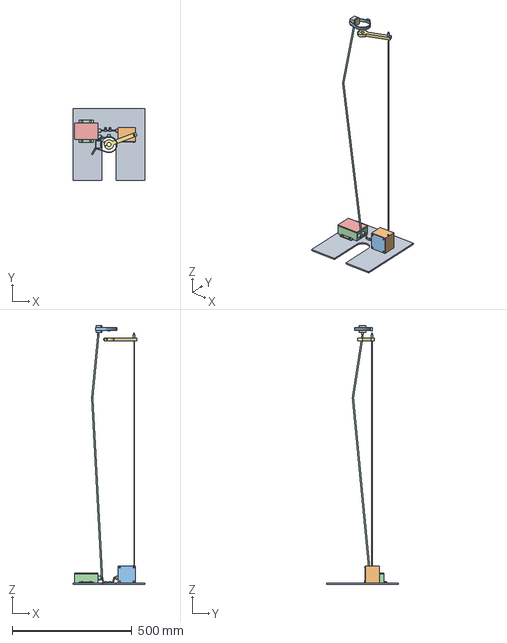
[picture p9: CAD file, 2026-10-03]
cad/step/sensor-set.step
300.0 x 300.0 x 1081.3 mm

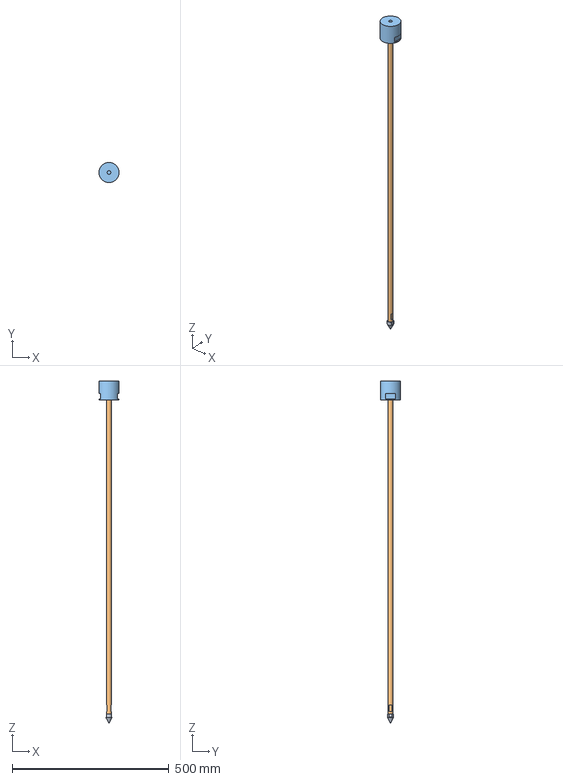
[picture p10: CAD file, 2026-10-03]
cad/step/drive-train.step
63.9 x 64.0 x 1089.3 mm

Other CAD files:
cad/stl/conepro-assembly.stl
cad/stl/drive-train.stl
cad/stl/hammer-assembly.stl
cad/stl/sensor-set.stl

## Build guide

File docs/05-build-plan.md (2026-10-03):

---
doc_id: CNP-BLD-001
title: ConePro prototype build plan
project: ConePro
doc_type: Build plan
version: "0.3"
status: Draft
date: '2026-10-02'
author: Amish Chadha
license: CERN-OHL-S-2.0
revisions:
  - version: "0.1"
    date: '2026-09-30'
    author: Amish Chadha
    change: First build plan; design made constructable (CNP-DDR-004)
  - version: "0.2"
    date: '2026-10-02'
    author: Amish Chadha
    change: "Decisions of 2026-10-02 carried in: no thread locker on the rod, anvil and cone joints (checked before each test); end cap on the upper rod's stud when off the anvil"
  - version: "0.3"
    date: '2026-10-02'
    author: Amish Chadha
    change: "Approved decisions carried into the model and pictures: spanner flats on the cone, lower rod and anvil; hammer grip grooves and label; rubber grips; end cap shown in step 5 and at safety stop S6; sketches CNP-DWG-101, 102 and 104 to 108 at Rev P2"
---

# ConePro prototype build plan

**Plan, not yet built.** How to build the first proof-of-concept prototype, component by component. Building and testing to it is TRL 4 work. Decisions still to be made are kept in the design decisions register ([docs/06-design-decisions.md](06-design-decisions.md)), not here.

## 1. What you are building

Figure 1. Every component, laid out and numbered in build order

*Figure 1. Every component laid out on the bench and numbered in build order.*

The prototype is a complete dynamic cone penetrometer with its sensor set: a hardened cone and a 1 m steel drive rod, a steel anvil, an 8 kg drop hammer sliding on an upper rod with a stop collar and a T-handle, and, on a slotted aluminium plate that lies on the ground, a draw-wire reel that measures how far the rod has gone down and a small logger box. A sensor pad strapped to the anvil counts the blows and reads the rod's lean. Figure 1 shows the 17 components in the order you make or fit them. Thirteen are made in a small workshop: the cone, both rods, the anvil, the hammer, the stop collar, the T-handle, the end cap for the upper rod, the clamp and arm, the reference plate, the printed reel housing and pad, and the turned drum; the bought logger box is drilled. The rest are bought and fitted: the bearings, spring motor and sensor boards, the wire, the band clamp, the cables, glands and fixings. The work is lathe turning and threading, sawing, drilling and tapping steel and aluminium, one welding job (the handle), two 3D prints, and wiring bought modules. The parts cost about $346 from the bill of materials.

> **Safety:** The finished instrument drops an 8 kg hammer 575 mm onto a steel anvil. Keep fingers off the anvil, the hammer face and the sensor pad whenever the hammer is on the rod, and never stand the upper rod on its end with the hammer free to slide off; whenever the upper rod is off the anvil, its M12 stud carries the screw-on end cap. The hammer carries sixteen strong magnets: keep it away from pacemakers and other implanted devices. Hardened steel can chip: wear safety glasses for turning, drilling and every test blow. Welding needs a welding screen, gloves and a clear, ventilated space, or have a local shop do it.

## 2. What changed to make it buildable

The concept showed what ConePro does; some of its parts could not be made or joined as drawn. Each change below keeps what the instrument does. They are recorded in decision record CNP-DDR-004, accepted by Amish on 2026-10-02, and, for the changes Amish decided that day, in the design decisions register.

*Table 1. Changes from the concept.*

| Component | The concept had | The buildable design has | Why |
| --- | --- | --- | --- |
| Cone | A 5 mm parallel shoulder above the point | A 12 mm shoulder with an M12 tapped hole (Figure 2) | Room for the thread; the 20 mm, 60° point is unchanged |
| Rod joints | Plain rod ends meeting the cone and anvil | M12 studs on the rod ends, tapped holes in the cone and anvil, each seated on a square shoulder (Figures 3 and 6) | Blows pass through the shoulders; one thread size throughout |
| Stop collar and handle | A collar and handle stem overlapping the rod, with no fixing | The upper rod runs through the collar (roll pin) and through the handle tube (welded) (Figures 12 and 14) | The drop is set on the real hammer before pinning |
| Bubble level | A block resting on the round handle tube | A bullseye level bonded in a seat welded to the rod top (Figure 14) | Sits square on the rod axis |
| Hammer magnets | No defined position, in the striking face | Pockets on an 82 mm circle, outside the anvil strike area, 0.5 mm below the face (Figure 9) | The magnets are never struck |
| Clamp and wire arm | An arm through the rod, joined to nothing, and a collar held only by friction | One piece cut from 12 mm plate, its top butting the anvil underside (Figures 5 and 6) | The anvil carries it at every blow |
| Sensor pad and band | A band running through a flat pad | A curved pad on a curved isolator, with the band over the pad (Figure 16) | Full contact; a stock band clamp |
| Draw-wire reel | A solid block, drum under the exit | Housing, lid, drum, shaft, spring motor and sensor, with the drum's edge under the exit (Figures 21 and 22) | The wire leaves the drum straight up |
| Reel and logger | No fixing to the plate | Screws from below into the reel; a flanged logger box screwed down (Figures 20 and 26) | The plate still lies flat |
| Rod joint fixing | Thread locker on the rod, anvil and cone joints | No thread locker; spanner flats on the cone, the lower rod and the anvil, and the upper rod turned by its handle (Figures 2, 4 and 7) | The joints are undone for packing and for disposable cones; tightened with spanners and checked before each test |
| Hammer | A plain cylinder | Three grip grooves and a "fit the end cap" label, its length set at machining to keep 8.00 kg (Figure 8) | A safer grip when lifting and packing |
| Handle | A bare tube with end caps | Closed-end rubber grips about 33 mm across on both tube ends (Figure 13) | A firmer, warmer grip |
| Packing | Nothing to stop the hammer sliding off the upper rod | A screw-on end cap on the upper rod's stud whenever it is off the anvil (step 5 and safety stop S6) | The hammer cannot fall onto the user's feet |
| Wiring | No cable from the reel to the logger; no cable entries | A reel-to-logger cable in two P-clips; two glands in the logger (Figures 25 and 26) | The depth sensor can reach the logger; IP65 entries |

## 3. Making the components

Make and check each component before the assembly step that needs it. Sizes are in millimetres. Lathe tolerance is 0.1 mm and workshop tolerance 0.5 mm unless a step says otherwise; drawings do not carry tolerances before TRL 4. On the plate, positions are measured from its centre: "X" toward the reel side, "Y" away from the slot.

### 3.1 Cone (make 2, one spare)

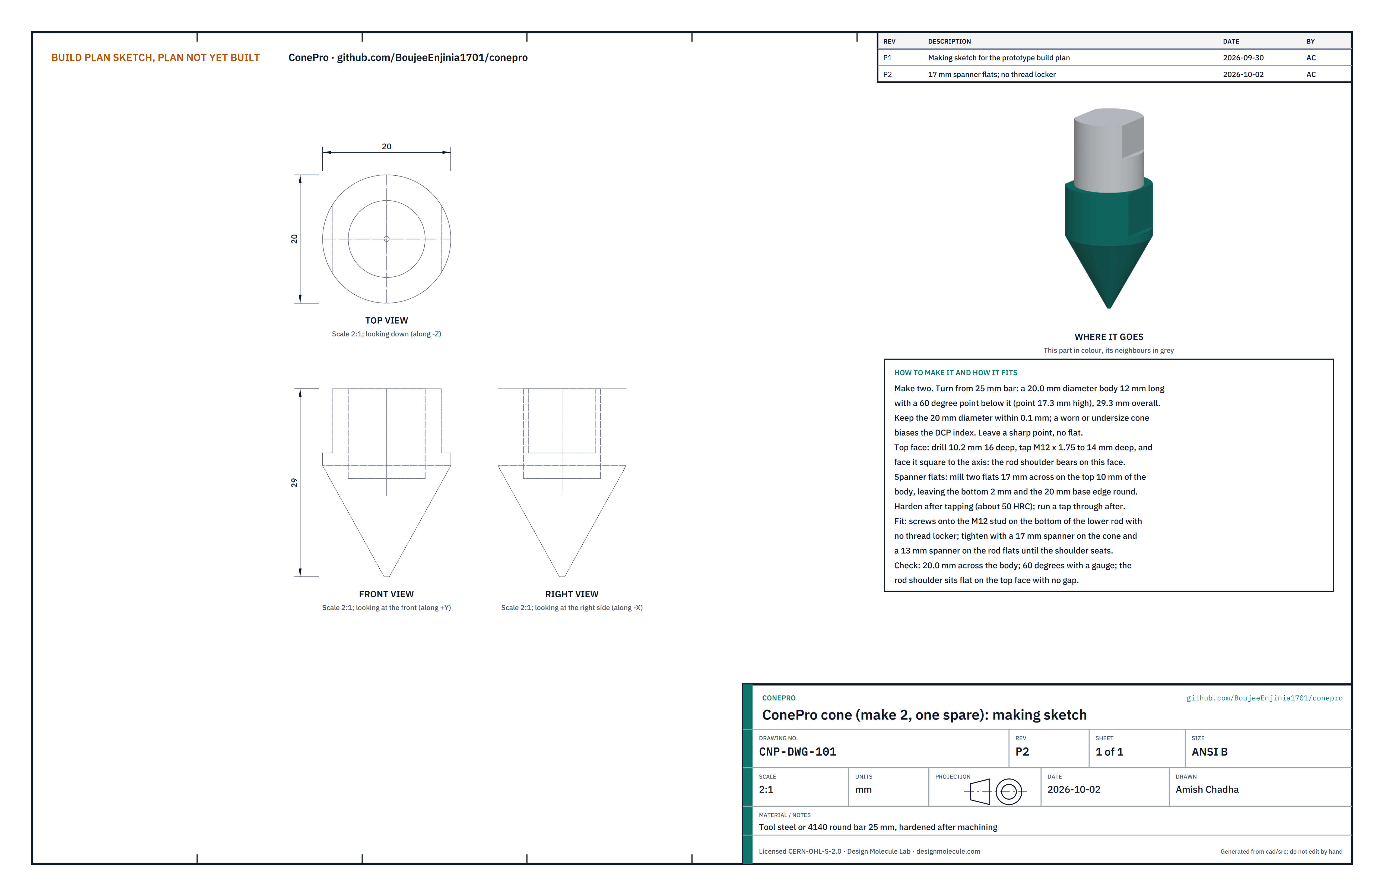
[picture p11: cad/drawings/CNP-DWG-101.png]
Figure 2. Making sketch of the cone


*Figure 2. Cone making sketch (CNP-DWG-101).*

**What it is and what it is made from.** The hardened point that is driven into the soil. Tool steel or 4140 class round bar 25 mm, hardened after machining.

**How to make it.**

1. Turn a 20.0 mm diameter body 12 mm long with a 60° point below it; the point is 17.3 mm high and the cone 29.3 mm overall. Leave a sharp point.
2. Face the top square to the axis: the rod's shoulder bears on it.
3. Drill 10.2 mm 16 mm deep in the top face and tap M12 x 1.75 to 14 mm deep.
4. Mill two spanner flats 17 mm across on the top 10 mm of the body, leaving the bottom 2 mm and the 20 mm base edge round.
5. Harden to about 50 HRC, then run the tap through again.

**How it fits the parts next to it.**

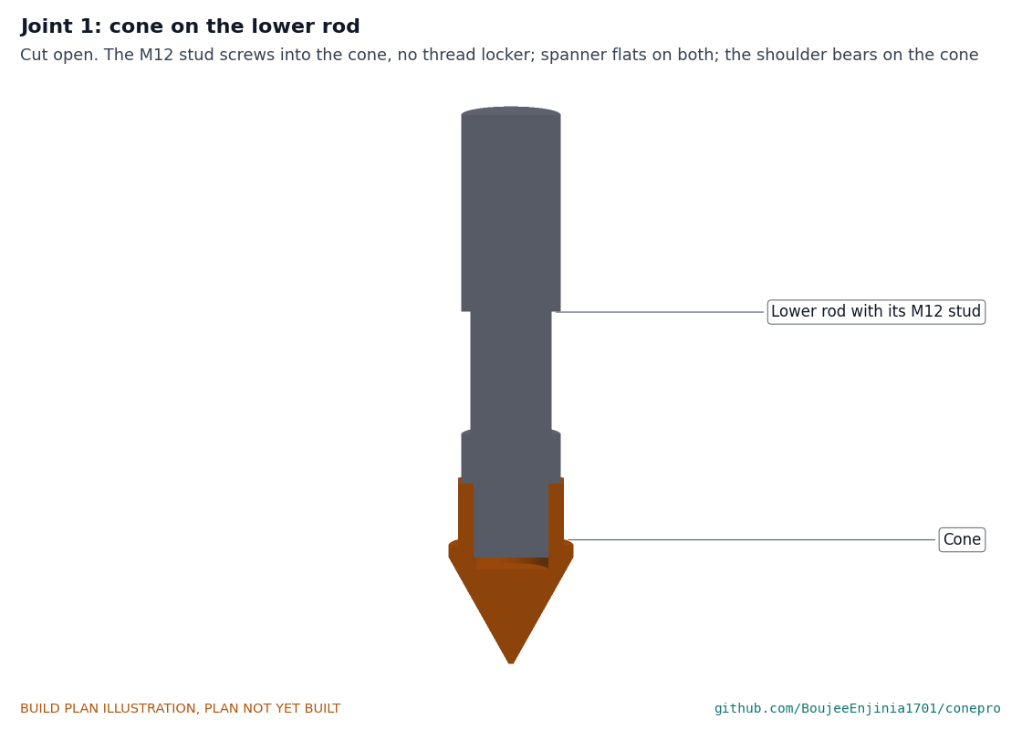
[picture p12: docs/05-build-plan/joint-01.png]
Figure 3. Joint 1: cone on the lower rod


*Figure 3. The rod's 12 mm stud screws into the cone; the rod's shoulder seats on the cone's top face.*

The cone screws onto the bottom stud of the lower rod, with no thread locker, until the shoulder seats; it is tightened with a 17 mm spanner on the cone's flats and a 13 mm spanner on the rod's flats, and checked before each test. A 2 mm gap is left at the bottom of the tapped hole, so the shoulder, not the stud, carries the blows.

**Check before moving on.** 20.0 mm across the body; 17 mm across the flats; 60° against a gauge; the rod shoulder sits flat on the cone with no visible gap.

### 3.2 Lower drive rod

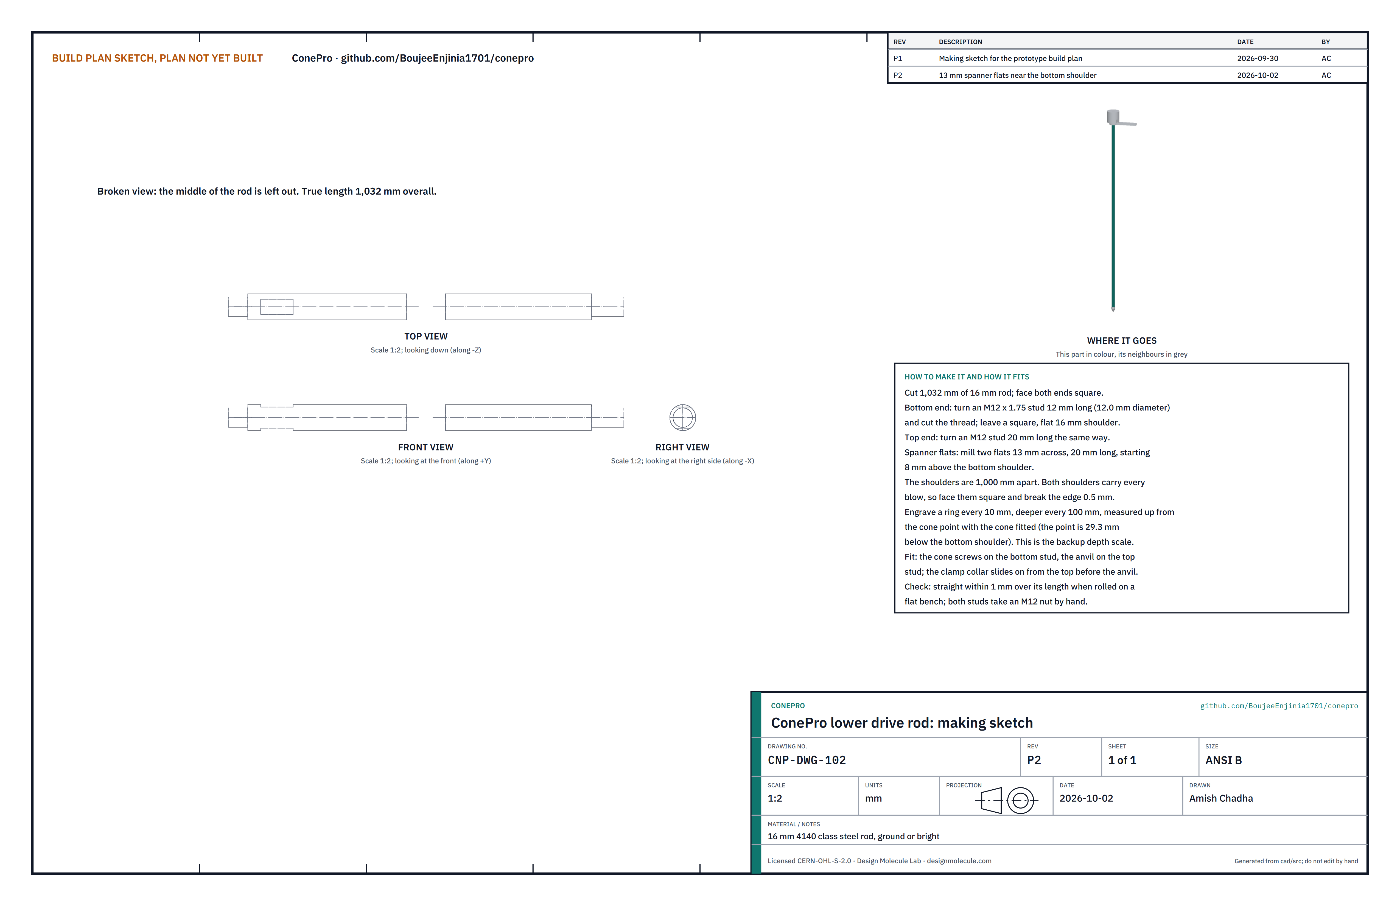
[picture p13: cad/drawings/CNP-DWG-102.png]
Figure 4. Making sketch of the lower drive rod


*Figure 4. Lower drive rod making sketch (CNP-DWG-102), drawn broken; it is 1,032 mm overall.*

**What it is and what it is made from.** The 1 m rod that carries the blows from the anvil to the cone. 16 mm steel rod, 4140 class, ground or bright.

**How to make it.**

1. Cut 1,032 mm and face both ends square.
2. Turn an M12 x 1.75 stud 12 mm long on the bottom end and one 20 mm long on the top end, each with a square, flat shoulder; the shoulders are 1,000 mm apart. Break the shoulder edges 0.5 mm.
3. Mill two spanner flats 13 mm across and 20 mm long, starting 8 mm above the bottom shoulder.
4. Engrave a ring every 10 mm, deeper every 100 mm, measured up from the cone point with the cone fitted (the point is 29.3 mm below the bottom shoulder). This is the backup depth scale and the calibration reference.

**How it fits the parts next to it.** The cone screws onto the bottom stud (Figure 3), the anvil onto the top stud (Figure 6). The clamp collar slides on from the top before the anvil goes on.

**Check before moving on.** Straight within 1 mm when rolled on a flat bench; both studs take an M12 nut by hand.

### 3.3 Clamp collar and wire arm

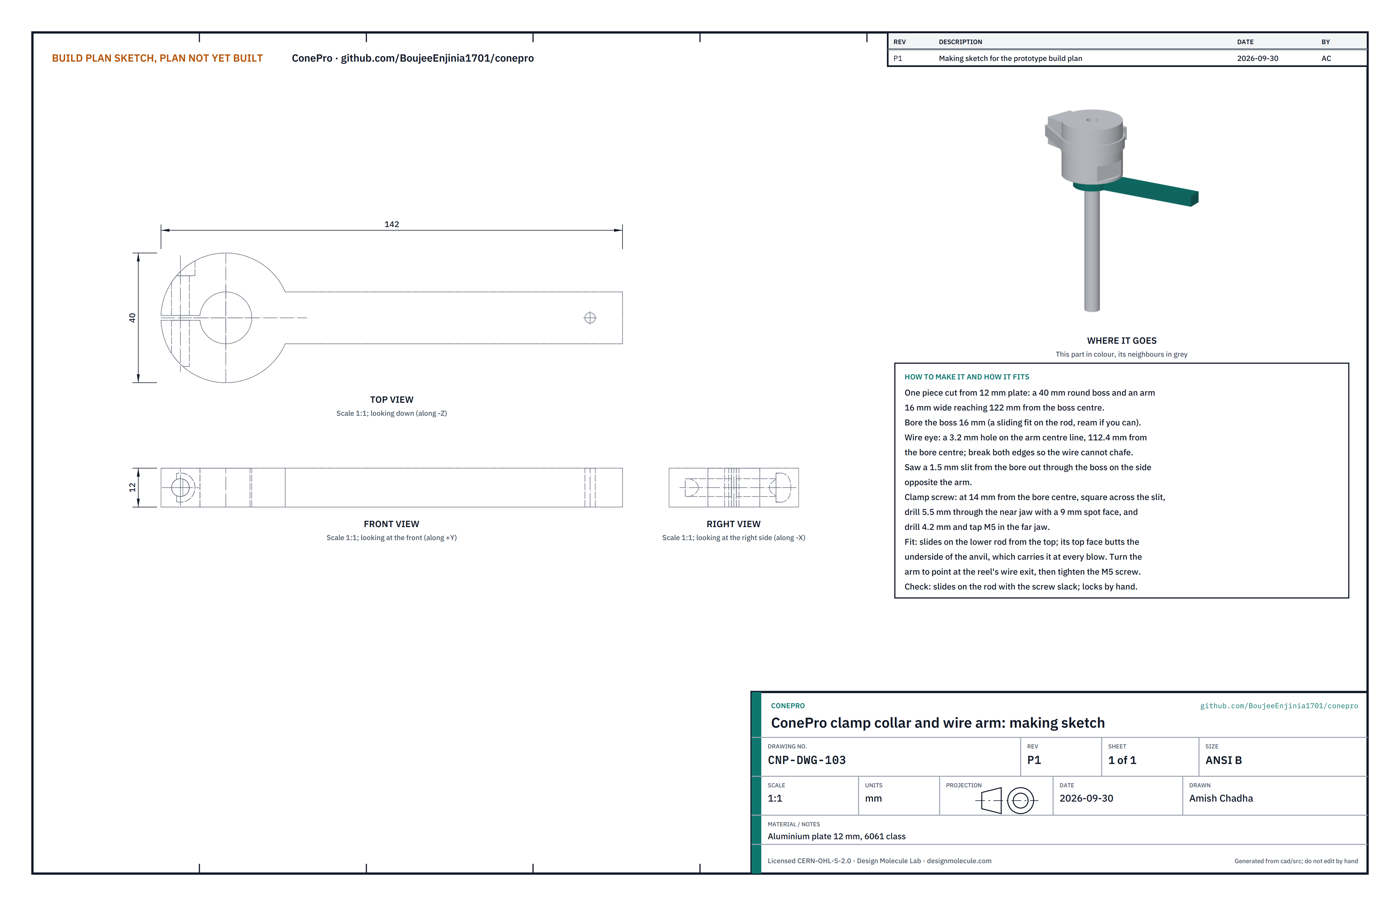
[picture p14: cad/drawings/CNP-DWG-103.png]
Figure 5. Making sketch of the clamp collar and wire arm


*Figure 5. Clamp collar and wire arm making sketch (CNP-DWG-103).*

**What it is and what it is made from.** The arm that the draw wire pulls on: it goes down with the rod, so the wire measures the cone's penetration. One piece of 6061 class aluminium plate 12 mm thick.

**How to make it.**

1. Mark out a 40 mm round boss and an arm 16 mm wide reaching 122 mm from the boss centre. Cut it out with a bandsaw or jigsaw and file to the lines.
2. Bore the boss 16 mm, a sliding fit on the rod (ream if you can).
3. Drill the 3.2 mm wire eye on the arm's centre line, 112.4 mm from the bore centre, and round both edges of the hole so the wire cannot chafe.
4. Saw a 1.5 mm slit from the bore out through the boss on the side opposite the arm.
5. Clamp screw: 14 mm from the bore centre and square across the slit, drill 5.5 mm through the near jaw with a 9 mm spot face for the head, then drill 4.2 mm and tap M5 in the far jaw. Fit an M5 x 25 socket screw.

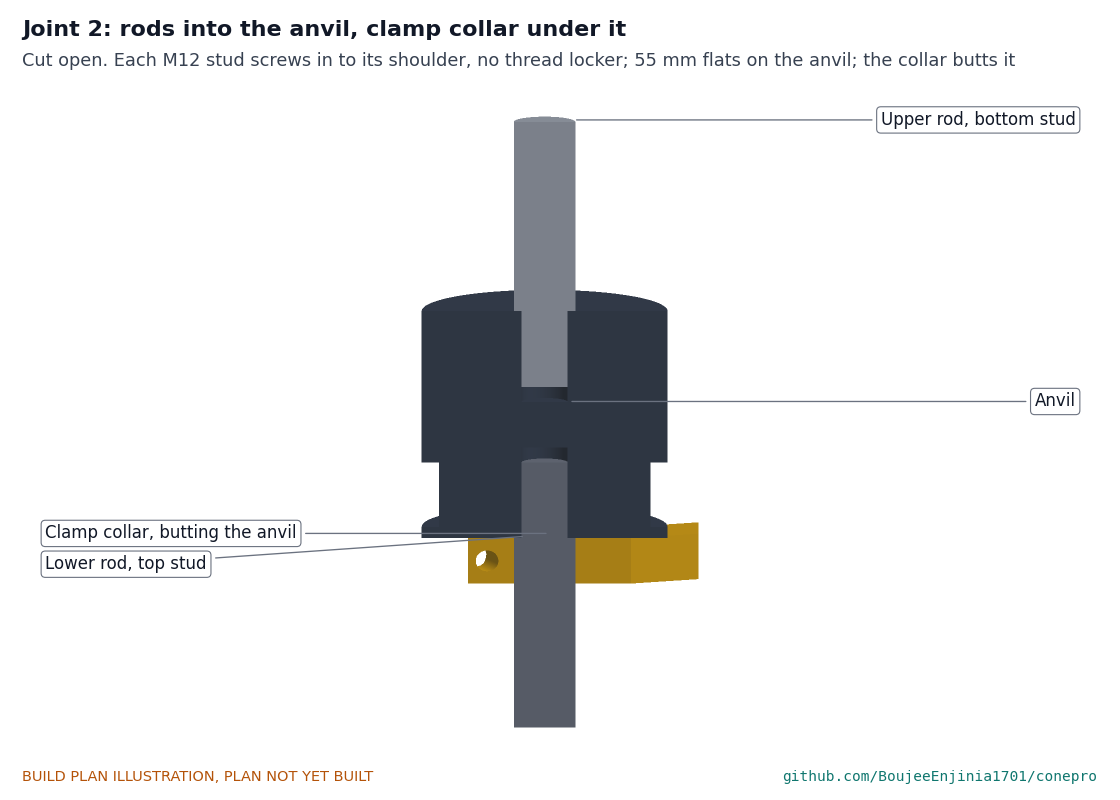
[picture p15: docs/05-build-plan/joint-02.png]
Figure 6. Joint 2: rods into the anvil, clamp collar under it


*Figure 6. The collar's top face butts the underside of the anvil.*

**How it fits the parts next to it.** The collar slides onto the lower rod from the top and is pushed up against the anvil's underside, which carries it at every blow. Turn the arm until its eye is straight above the reel's wire exit, then tighten the M5 screw.

**Check before moving on.** The collar slides on the rod with the screw slack and locks by hand with it tight.

### 3.4 Anvil

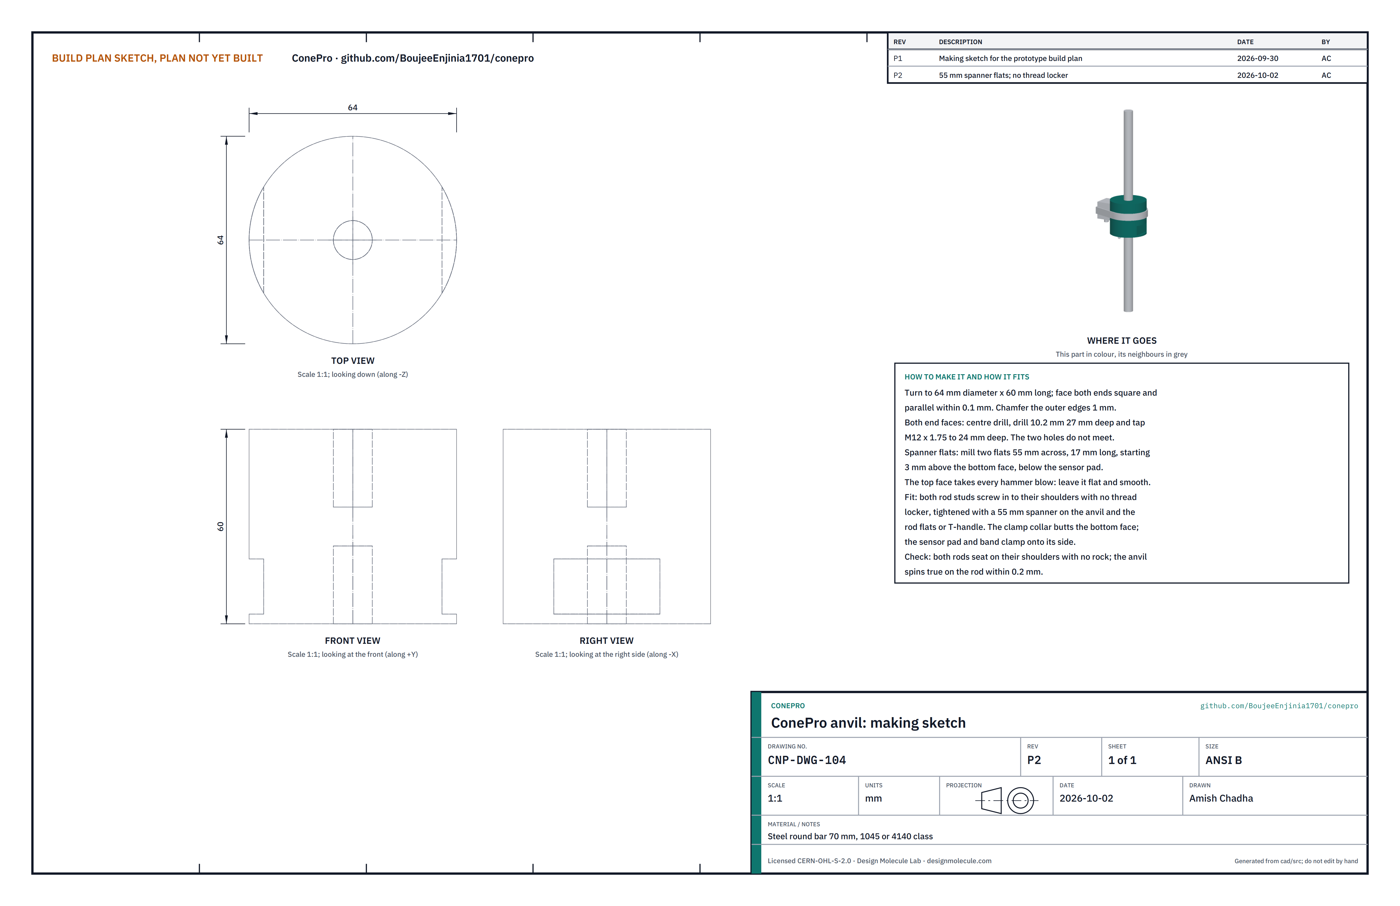
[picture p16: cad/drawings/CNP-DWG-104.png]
Figure 7. Making sketch of the anvil


*Figure 7. Anvil making sketch (CNP-DWG-104).*

**What it is and what it is made from.** The steel block the hammer strikes; it also joins the two rods. 1045 or 4140 class round bar 70 mm.

**How to make it.**

1. Turn to 64 mm diameter x 60 mm; face both ends square and parallel within 0.1 mm; chamfer the outer edges 1 mm.
2. In both end faces, centre drill, drill 10.2 mm 27 mm deep and tap M12 x 1.75 to 24 mm deep. The two holes do not meet.
3. Mill two spanner flats 55 mm across and 17 mm long, starting 3 mm above the bottom face, so they stay below the sensor pad.

**How it fits the parts next to it.** The lower rod's top stud screws into the bottom hole and the upper rod's stud into the top hole, each to its shoulder with no thread locker, tightened with a 55 mm spanner on the anvil's flats and a 13 mm spanner on the lower rod's flats, or by turning the T-handle for the upper rod (Figure 6). The clamp collar butts the bottom face; the sensor pad and band clamp onto the side.

**Check before moving on.** Both rods seat on their shoulders with no rock; the anvil spins true on the rod within 0.2 mm.

### 3.5 Drop hammer

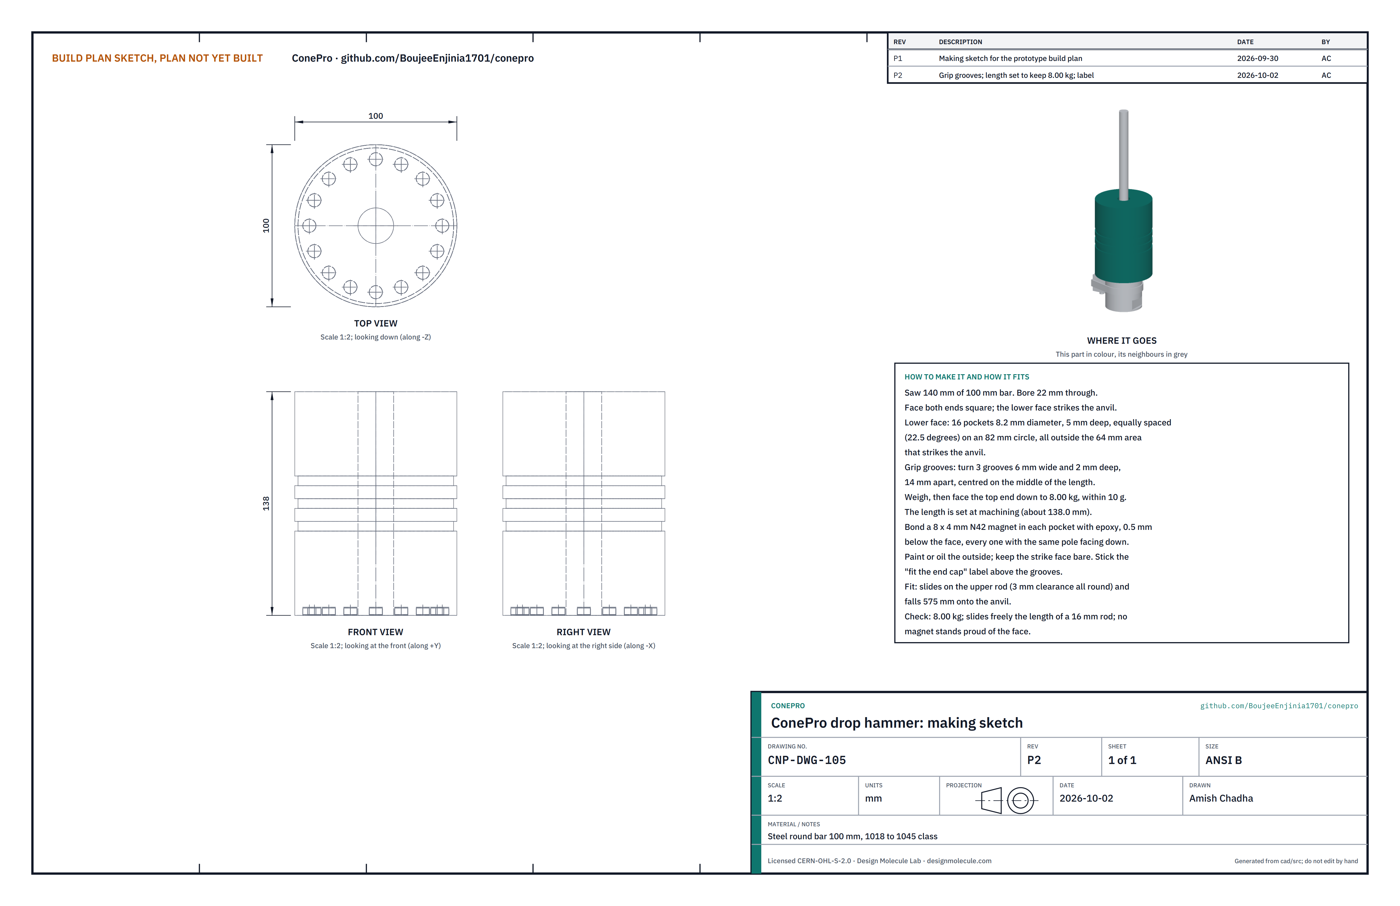
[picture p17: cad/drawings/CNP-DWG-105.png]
Figure 8. Making sketch of the drop hammer


*Figure 8. Drop hammer making sketch (CNP-DWG-105).*

**What it is and what it is made from.** The 8.00 kg weight that is lifted and dropped 575 mm onto the anvil. 1018 to 1045 class round bar 100 mm, with sixteen 8 x 4 mm N42 disc magnets.

**How to make it.**

1. Saw 140 mm of bar and bore 22 mm through.
2. Face both ends square. The lower face strikes the anvil.
3. In the lower face, cut sixteen pockets 8.2 mm diameter and 5 mm deep, equally spaced (22.5° apart) on an 82 mm circle. They all lie outside the 64 mm area that strikes the anvil.
4. Turn three grip grooves 6 mm wide and 2 mm deep, 14 mm apart, centred on the middle of the length.
5. Weigh it, then face the top end down until it weighs 8.00 kg within 10 g. The length is set here, at machining (about 138.0 mm).
6. Bond a magnet in each pocket with epoxy, 0.5 mm below the face, every one with the same pole facing down. Mark that pole.
7. Paint or oil the outside; leave the strike face bare. Stick the "fit the end cap when the rod is off the anvil" label on the side, above the grooves.

**How it fits the parts next to it.** It slides on the upper rod with 3 mm clearance all round and lands on the anvil's top face. As it lands, the magnets pass over the sensor pad:

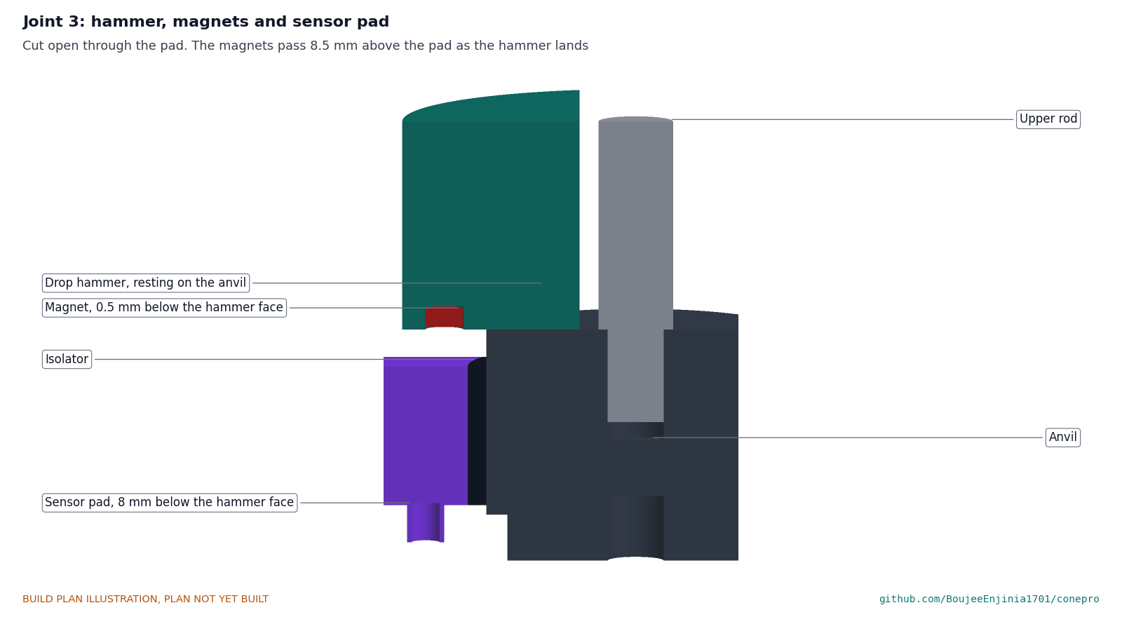
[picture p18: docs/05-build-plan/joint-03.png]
Figure 9. Joint 3: hammer, magnets and sensor pad


*Figure 9. The magnets sit 8.5 mm above the pad's top face when the hammer rests on the anvil.*

**Check before moving on.** 8.00 kg; slides freely along a 16 mm rod; no magnet stands proud of the face.

### 3.6 Upper rod

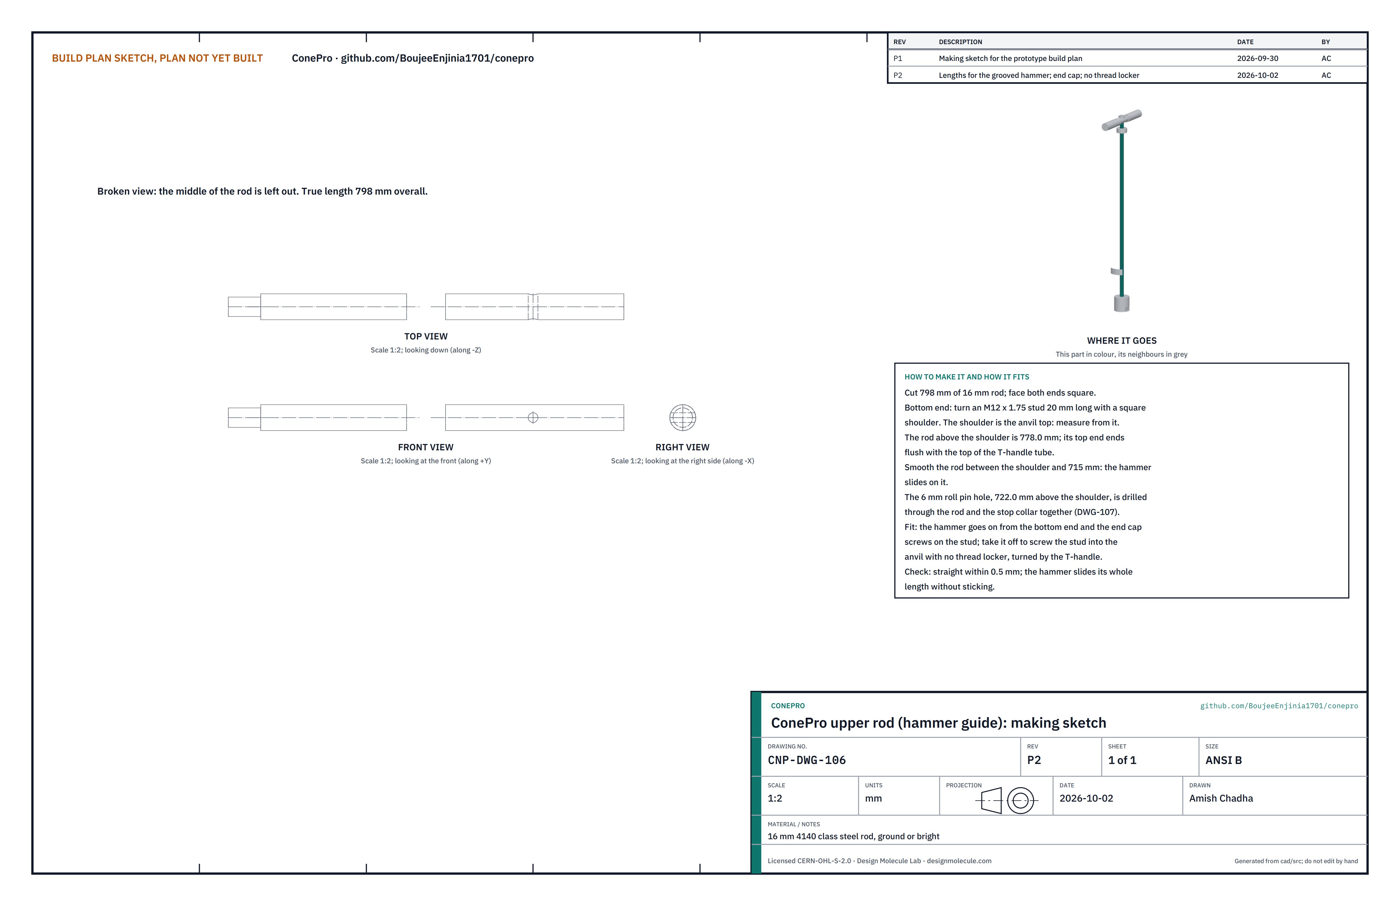
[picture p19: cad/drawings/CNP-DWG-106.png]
Figure 10. Making sketch of the upper rod


*Figure 10. Upper rod making sketch (CNP-DWG-106), drawn broken; it is 798 mm overall.*

**What it is and what it is made from.** The rod the hammer slides on; it carries the stop collar and the handle. 16 mm steel rod, 4140 class.

**How to make it.**

1. Cut 798 mm and face both ends square.
2. Turn an M12 x 1.75 stud 20 mm long on the bottom end with a square shoulder. Measure everything from this shoulder: it sits on the anvil.
3. Smooth the rod from the shoulder up to 715 mm, where the hammer slides.
4. The 6 mm pin hole, 722.0 mm above the shoulder, is drilled later through rod and collar together (section 3.7).

**How it fits the parts next to it.** The hammer goes on from the bottom end and the end cap screws onto the stud to keep it there; the cap comes off when the stud screws into the anvil (Figure 6). The rod needs no spanner flats: it is turned by its T-handle. The top end passes through the handle tube and ends flush with its top (Figure 14).

**Check before moving on.** Straight within 0.5 mm; the hammer slides its whole working length without sticking.

### 3.7 Top stop collar

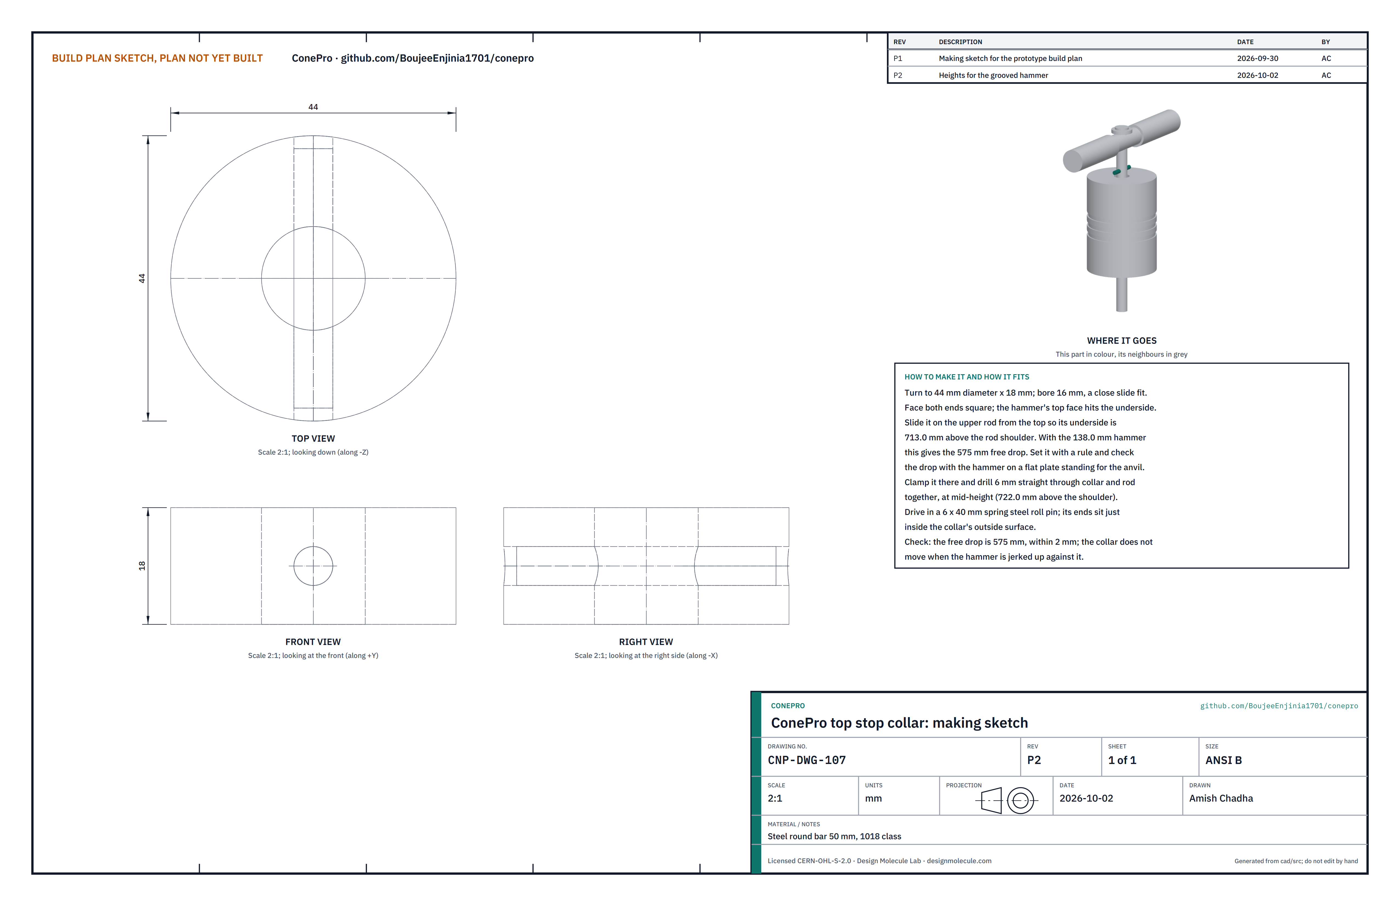
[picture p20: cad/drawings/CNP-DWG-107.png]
Figure 11. Making sketch of the top stop collar


*Figure 11. Top stop collar making sketch (CNP-DWG-107).*

**What it is and what it is made from.** The collar the hammer is lifted up to; it sets the 575 mm drop. 1018 class round bar 50 mm and a 6 x 40 mm spring steel roll pin.

**How to make it.**

1. Turn to 44 mm diameter x 18 mm and bore 16 mm, a close slide fit on the rod. Face both ends square.
2. Slide it onto the upper rod from the top so its underside is 713.0 mm above the rod's shoulder: the 138.0 mm hammer plus the 575 mm drop. Check the drop with the hammer on the rod and the shoulder standing on a flat plate.
3. Clamp it there and drill 6 mm straight through collar and rod together at its mid-height, 722.0 mm above the shoulder.
4. Drive in the roll pin; its ends sit just inside the collar's outside surface.

**How it fits the parts next to it.**

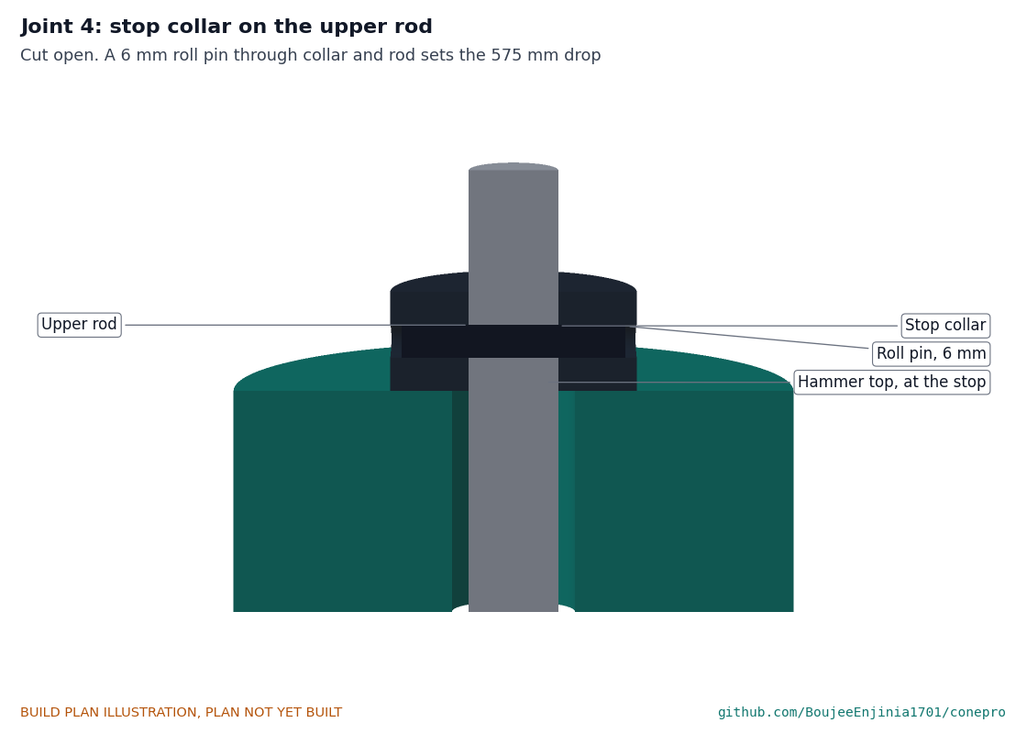
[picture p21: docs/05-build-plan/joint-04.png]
Figure 12. Joint 4: stop collar on the upper rod


*Figure 12. The roll pin passes through collar and rod; the hammer's top face stops against the collar's underside.*

**Check before moving on.** The free drop is 575 mm within 2 mm; the collar does not move when the hammer is jerked up against it.

### 3.8 T-handle, level seat and bubble level

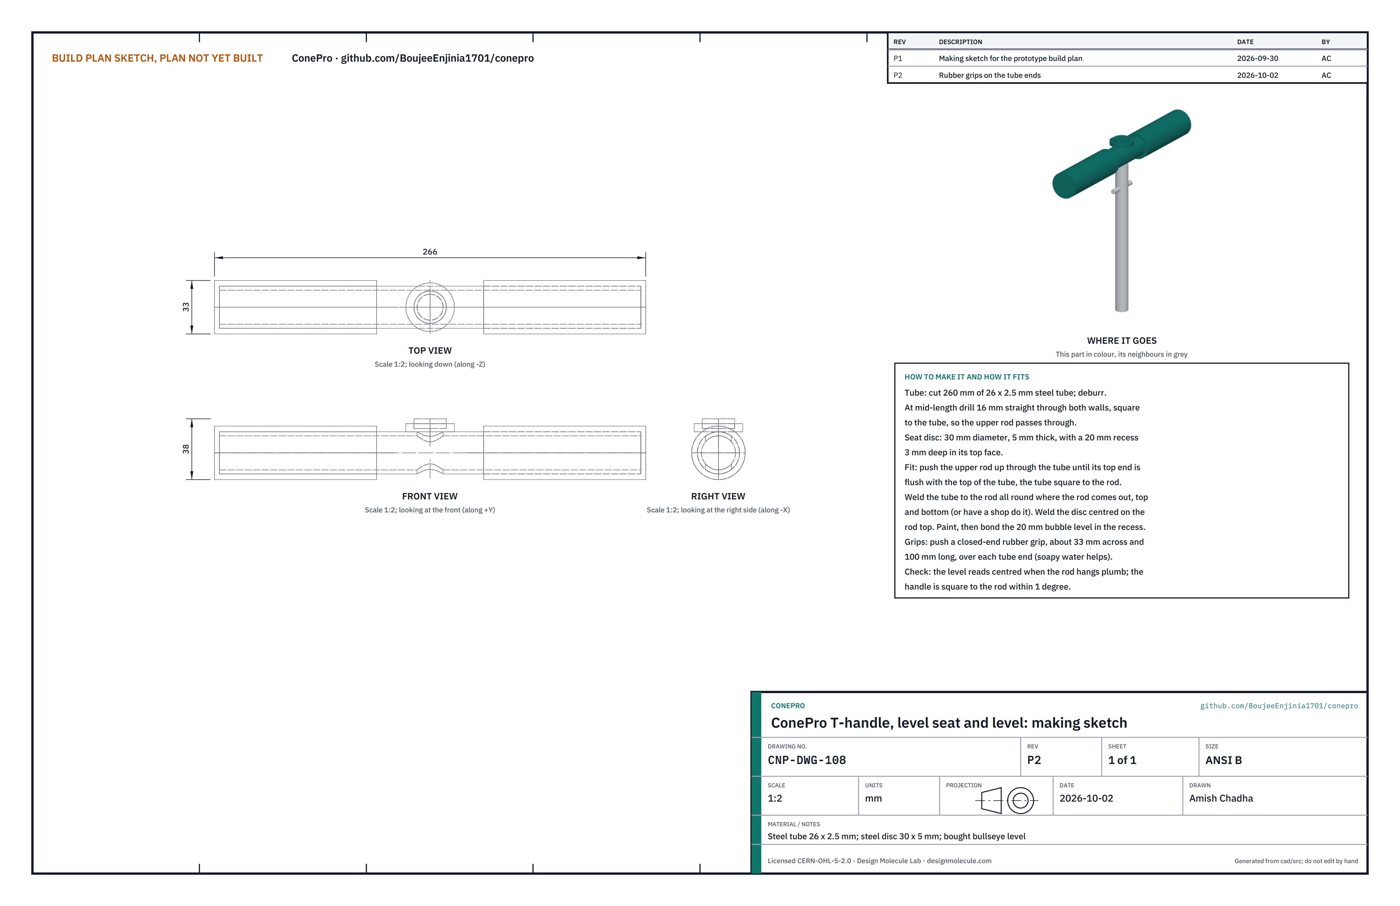
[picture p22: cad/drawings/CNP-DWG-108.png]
Figure 13. Making sketch of the T-handle and level seat


*Figure 13. T-handle, level seat and level making sketch (CNP-DWG-108).*

**What it is and what it is made from.** The handle the operator holds, and the backup level that shows when the rod is plumb. Steel tube 26 x 2.5 mm, a 30 x 5 mm steel disc, a bought 20 mm bullseye level and two rubber grips.

**How to make it.**

1. Cut 260 mm of tube and deburr it. At mid-length drill 16 mm straight through both walls, square to the tube.
2. Turn the seat disc 30 mm diameter and 5 mm thick with a 20 mm recess 3 mm deep in its top face.
3. Push the upper rod (with the stop collar already pinned) up through the tube until its top end is flush with the top of the tube and the tube is square to the rod.
4. Weld the tube to the rod all round where the rod comes out, top and bottom, or have a local shop do it. Weld the disc centred on the rod top.
5. Paint, then bond the level in the recess.
6. Push a closed-end rubber grip, about 33 mm across and 100 mm long, over each tube end; soapy water helps it slide on.

**How it fits the parts next to it.**

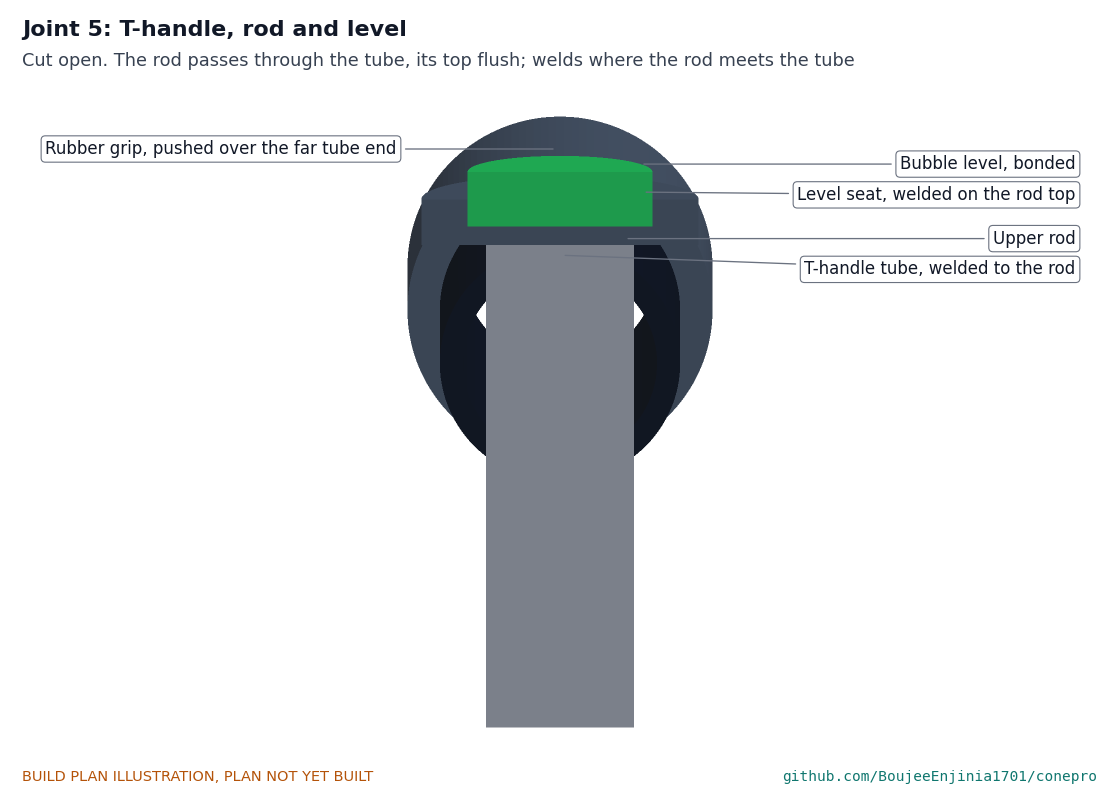
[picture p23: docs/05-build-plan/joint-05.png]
Figure 14. Joint 5: T-handle, rod and level


*Figure 14. The rod passes through the tube, its top flush; the seat sits on the rod top and the level in the seat.*

**Check before moving on.** With the rod hanging plumb the level reads centred; the handle is square to the rod within 1°.

### 3.9 Sensor pad and isolator

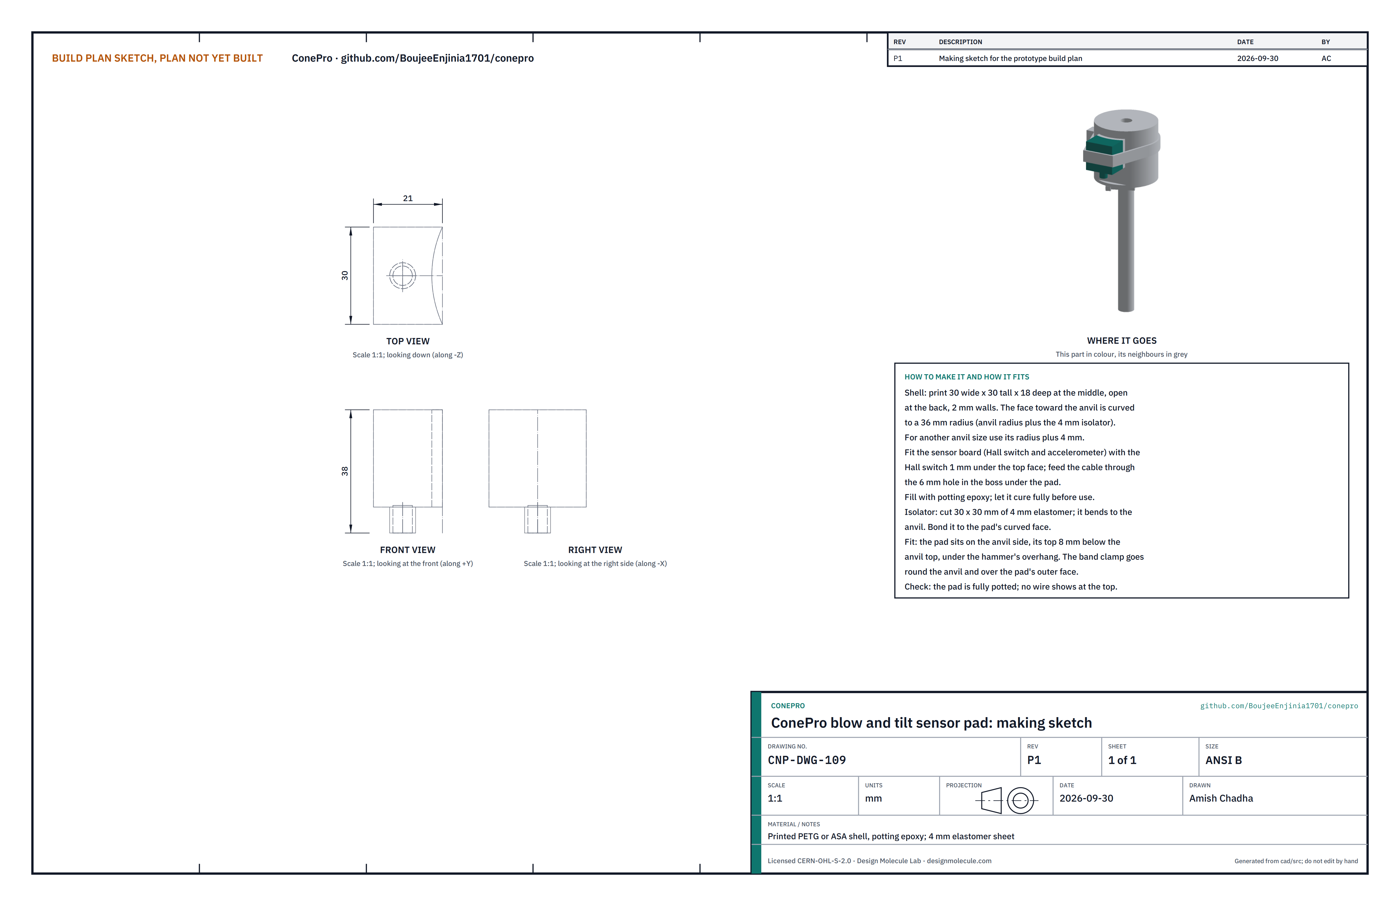
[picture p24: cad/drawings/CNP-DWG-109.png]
Figure 15. Making sketch of the sensor pad


*Figure 15. Blow and tilt sensor pad making sketch (CNP-DWG-109).*

**What it is and what it is made from.** A small potted block on the side of the anvil: its Hall switch counts the blows as the hammer's magnets pass over it, and its accelerometer reads the impact and the rod's lean. A printed PETG or ASA shell, potting epoxy, the bought sensor board, a 4 mm elastomer sheet and a 12 mm stainless worm-drive band clamp.

**How to make it.**

1. Print the shell 30 wide x 30 tall x 18 deep at the middle, open at the back, with 2 mm walls. The face toward the anvil is curved to a 36 mm radius (the anvil radius plus the 4 mm isolator); for another anvil, use its radius plus 4 mm. A boss underneath has a 6 mm hole for the cable.
2. Fit the sensor board with the Hall switch 1 mm under the top face. Feed the coiled cable's pad end through the boss.
3. Fill with potting epoxy and let it cure fully.
4. Cut 30 x 30 mm of the elastomer sheet and bond it to the curved face.

**How it fits the parts next to it.**

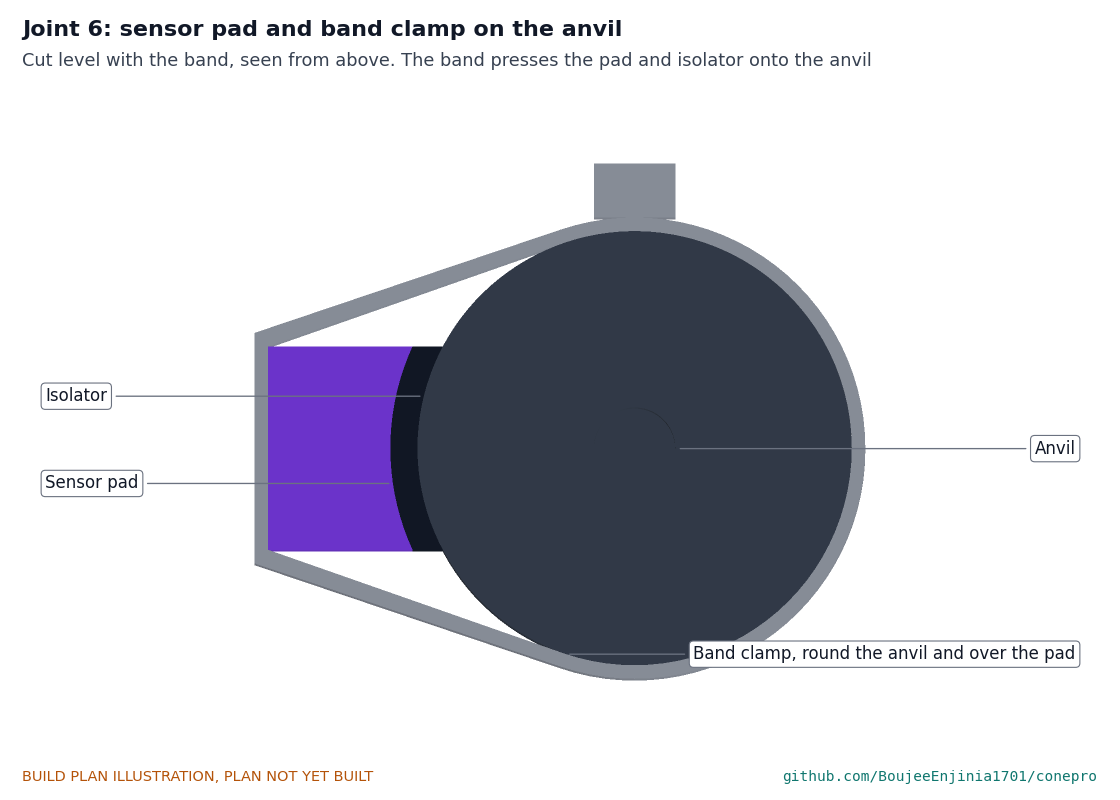
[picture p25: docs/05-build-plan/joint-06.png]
Figure 16. Joint 6: sensor pad and band clamp on the anvil


*Figure 16. Seen from above at the band: the band goes round the anvil and over the pad, pressing pad and isolator onto the anvil.*

The pad sits on the side of the anvil opposite the arm, its top 8 mm below the anvil's top face, under the hammer's overhang (Figure 9). The band clamp, about 12 mm wide, goes round the anvil and across the pad's outer face, with its screw housing on the far side.

**Check before moving on.** The pad is fully potted with no wire showing; it does not move when pushed by hand once the band is tight.

### 3.10 Reference plate

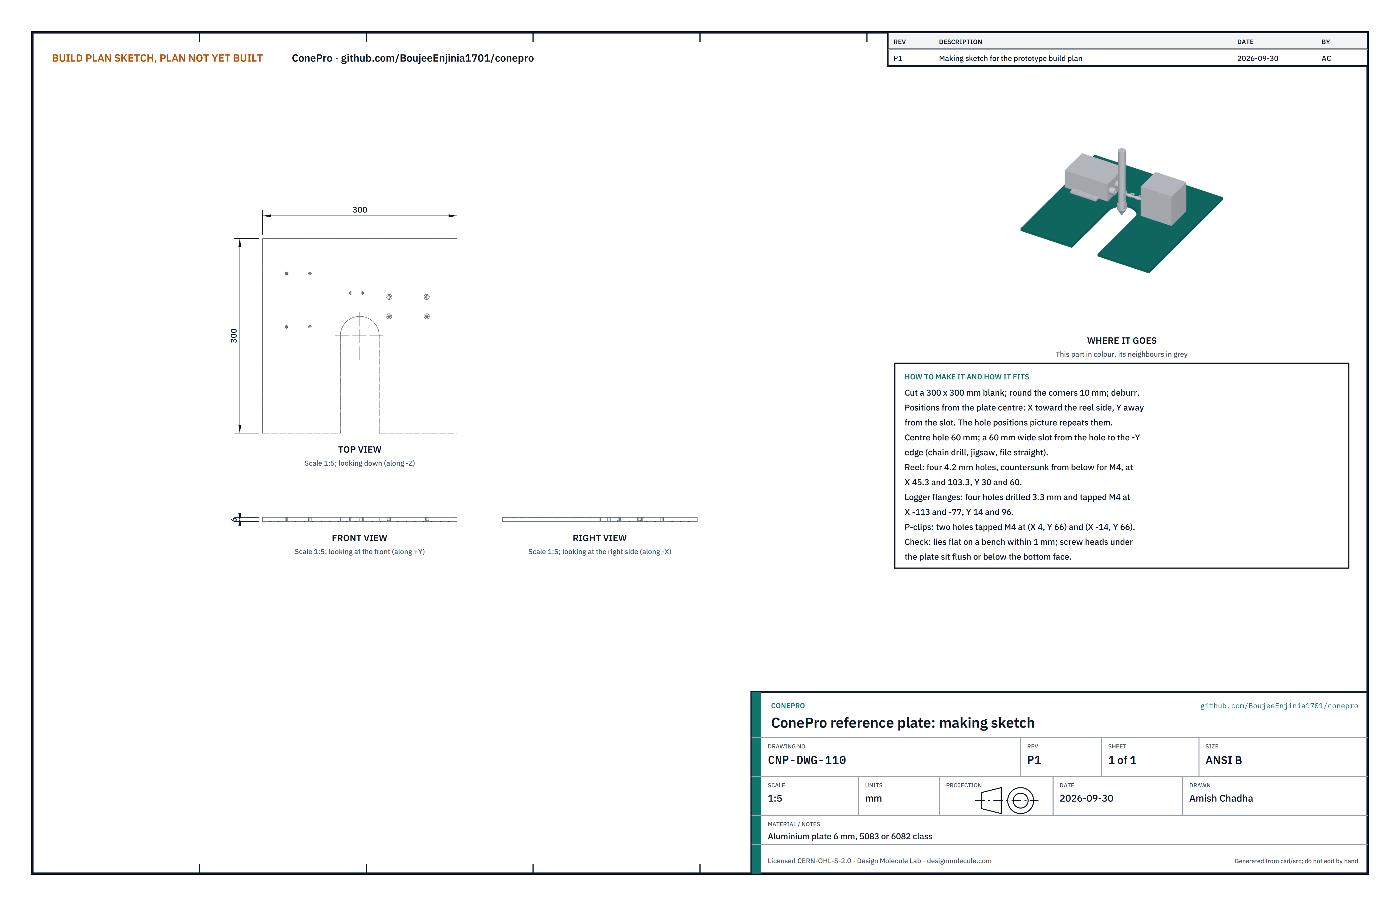
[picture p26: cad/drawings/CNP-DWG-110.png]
Figure 17. Making sketch of the reference plate


*Figure 17. Reference plate making sketch (CNP-DWG-110).*

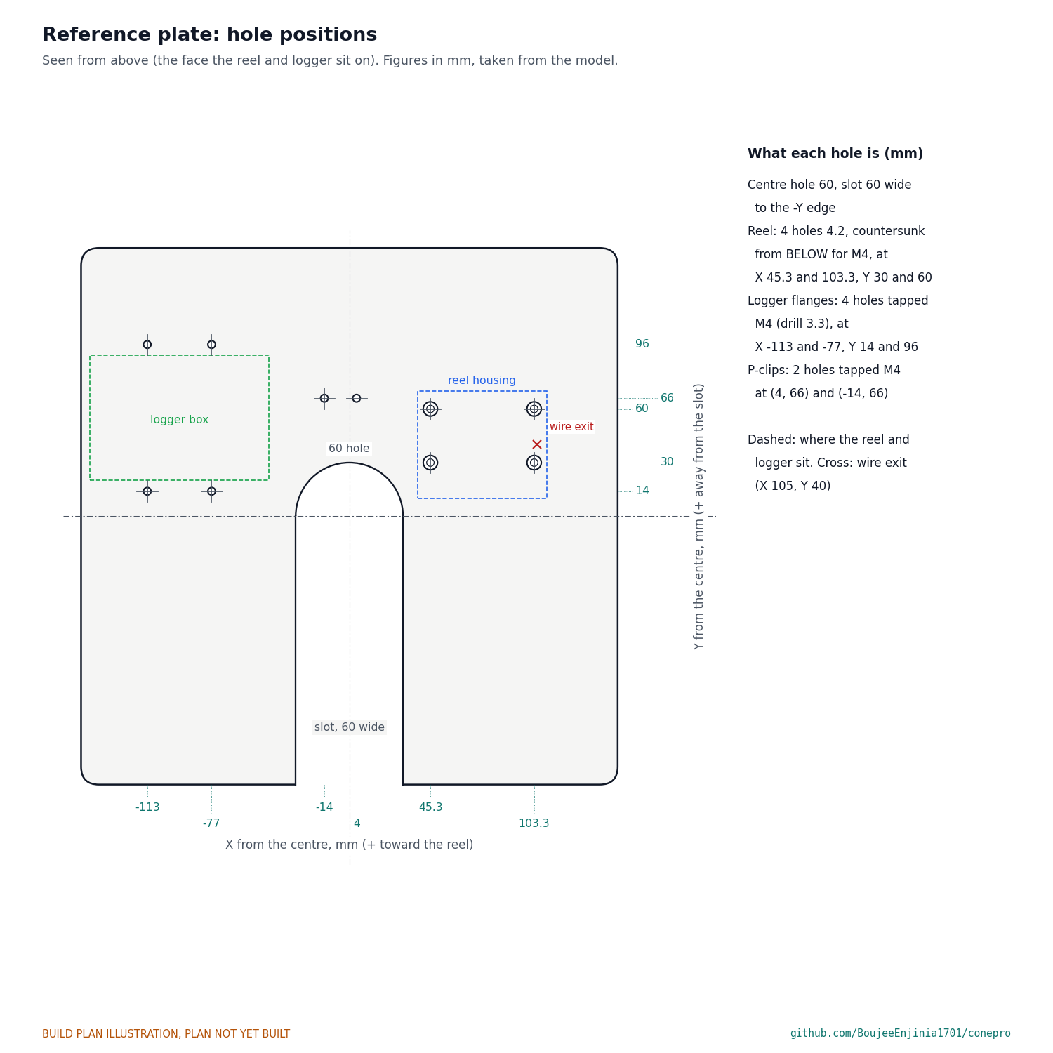
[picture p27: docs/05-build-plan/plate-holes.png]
Figure 18. Hole positions on the reference plate


*Figure 18. Every hole, measured from the plate centre.*

**What it is and what it is made from.** The plate that lies on the ground round the rod: the zero for the depth, and the base for the reel and logger. 5083 or 6082 class aluminium plate 6 mm.

**How to make it.**

1. Cut a 300 x 300 mm blank, round the corners to 10 mm, and mark the centre.
2. Cut the 60 mm centre hole and a 60 mm wide slot from the hole to one edge (the -Y edge): chain drill, cut with a jigsaw and file straight.
3. Reel holes: four 4.2 mm holes at X 45.3 and 103.3, Y 30 and 60, countersunk from below for M4 screws.
4. Logger holes: four holes drilled 3.3 mm and tapped M4 at X -113 and -77, Y 14 and 96.
5. P-clip holes: two holes tapped M4 at X 4, Y 66 and X -14, Y 66.
6. Deburr everything.

**How it fits the parts next to it.** The reel and logger sit on its top face (Figures 20 and 26). Its underside lies on the ground, so every screw head underneath must sit flush.

**Check before moving on.** Flat within 1 mm on a bench; the reel housing and logger box line up with their holes.

### 3.11 Reel housing and lid

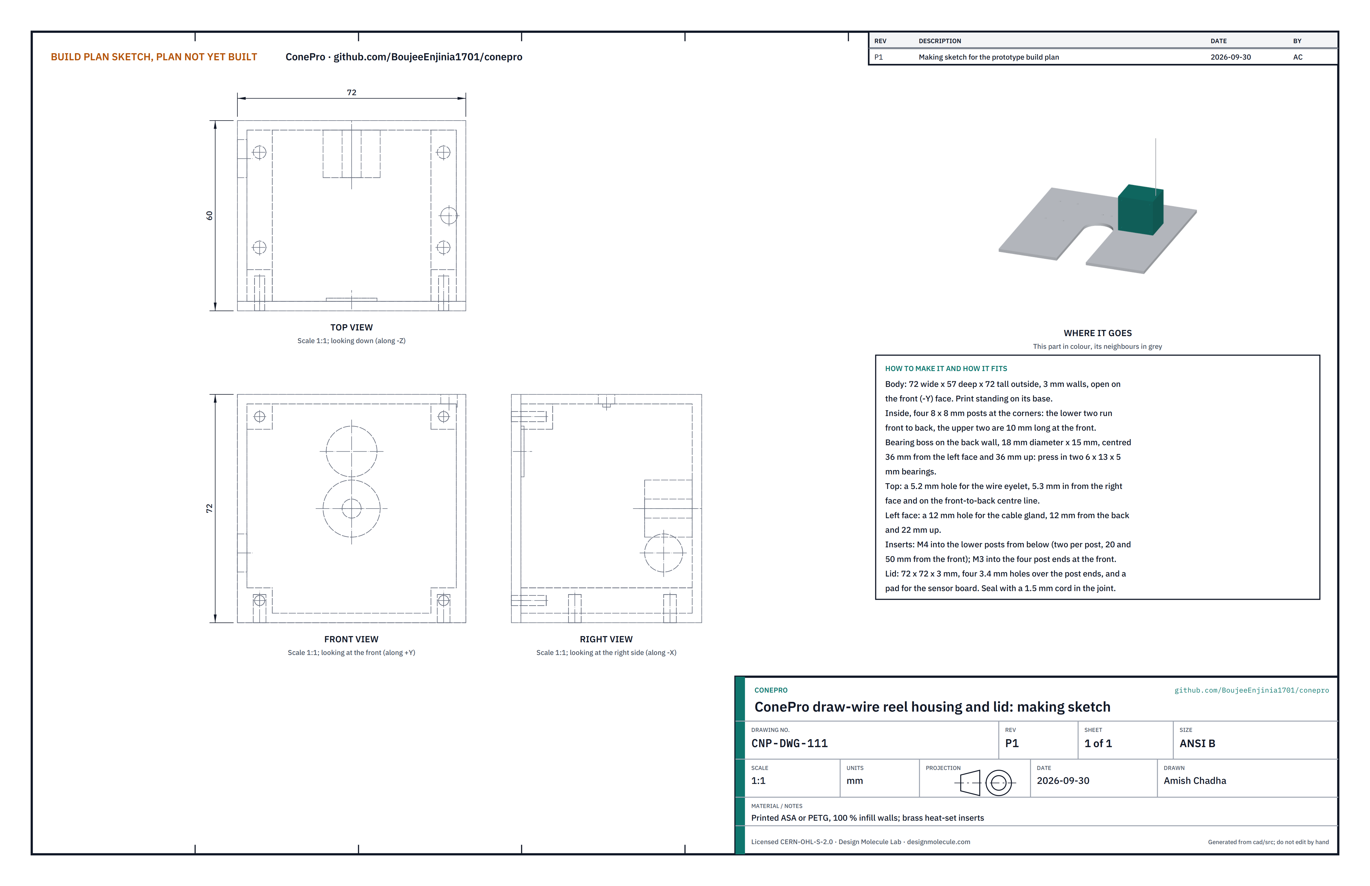
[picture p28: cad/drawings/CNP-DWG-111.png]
Figure 19. Making sketch of the reel housing and lid


*Figure 19. Draw-wire reel housing and lid making sketch (CNP-DWG-111).*

**What it is and what it is made from.** The box that holds the draw-wire drum and its sensor and keeps rain and dust out. Printed ASA or PETG with solid walls, brass heat-set inserts, two 6 x 13 x 5 mm bearings, a 1.5 mm sealing cord and a pressed-in wire eyelet.

**How to make it.**

1. Print the body 72 wide, 57 deep and 72 tall with 3 mm walls, open on the front face, standing on its base. Inside: an 8 x 8 mm post along each bottom corner, front to back; two short 8 x 8 x 10 mm posts at the top front corners; and an 18 mm bearing boss, 15 mm deep, on the back wall, centred 36 mm from the left face and 36 mm up.
2. Print the lid, 72 x 72 x 3 mm, with four 3.4 mm holes over the post ends and a small pad where the sensor board mounts.
3. Holes in the body: a 5.2 mm hole in the top, 5.3 mm in from the right face and half way back, for the eyelet; a 12 mm hole in the left face, 12 mm from the back and 22 mm up, for the cable gland.
4. Fit heat-set inserts: M4 into the underside of each bottom post, 20 mm and 50 mm from the front; M3 into the four post ends at the front.
5. Press the two bearings into the boss.

**How it fits the parts next to it.**

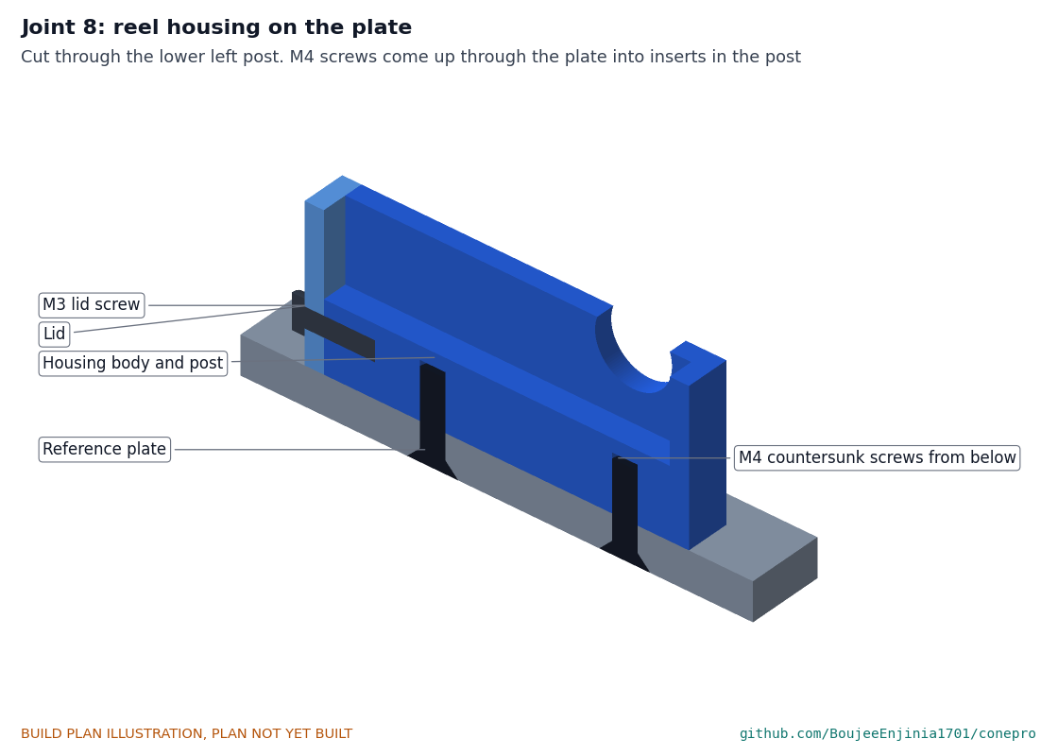
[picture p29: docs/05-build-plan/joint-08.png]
Figure 20. Joint 8: reel housing on the plate


*Figure 20. Cut through the lower left post: the M4 screws come up through the countersunk plate holes into the inserts; the M3 screws hold the lid on.*

**Check before moving on.** The lid seats all round on the sealing cord; the drum shaft turns freely in the bearings.

### 3.12 Drum and the parts inside the reel

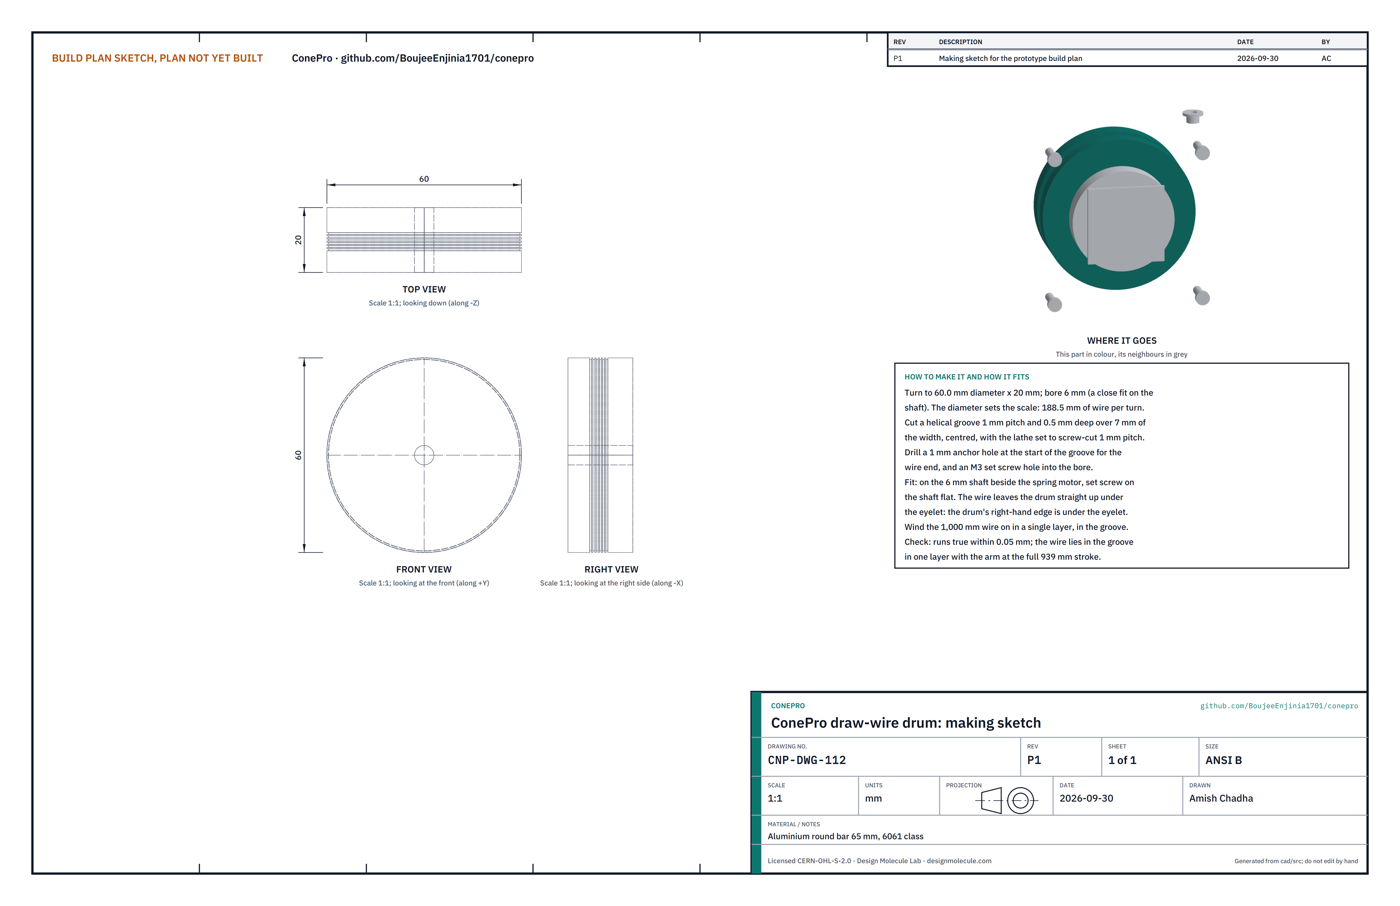
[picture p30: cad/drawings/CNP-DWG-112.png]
Figure 21. Making sketch of the drum


*Figure 21. Draw-wire drum making sketch (CNP-DWG-112).*

**What it is and what it is made from.** The drum the wire winds on: each turn is 188.5 mm of wire, which the angle sensor reads to 0.05 mm. 6061 class aluminium round bar 65 mm, a 6 mm steel shaft, a constant-force spring motor (3 to 5 N), a 6 mm diametric magnet, a 12-bit magnetic angle sensor board and about 1,000 mm of 0.45 mm coated 7x7 steel wire.

**How to make it.**

1. Turn the drum 60.0 mm diameter x 20 mm and bore it 6 mm, a close fit on the shaft. The diameter sets the scale, so hold it to 0.05 mm.
2. Screw-cut a helical groove, 1 mm pitch and 0.5 mm deep, over 7 mm of the width, centred.
3. Drill a 1 mm anchor hole at the start of the groove and an M3 set screw hole into the bore.
4. File a flat on the shaft for the set screw. Fit the spring motor beside the drum and the magnet on the shaft's front end.
5. Anchor the wire and wind it on in one layer, in the groove.

**How it fits the parts next to it.**

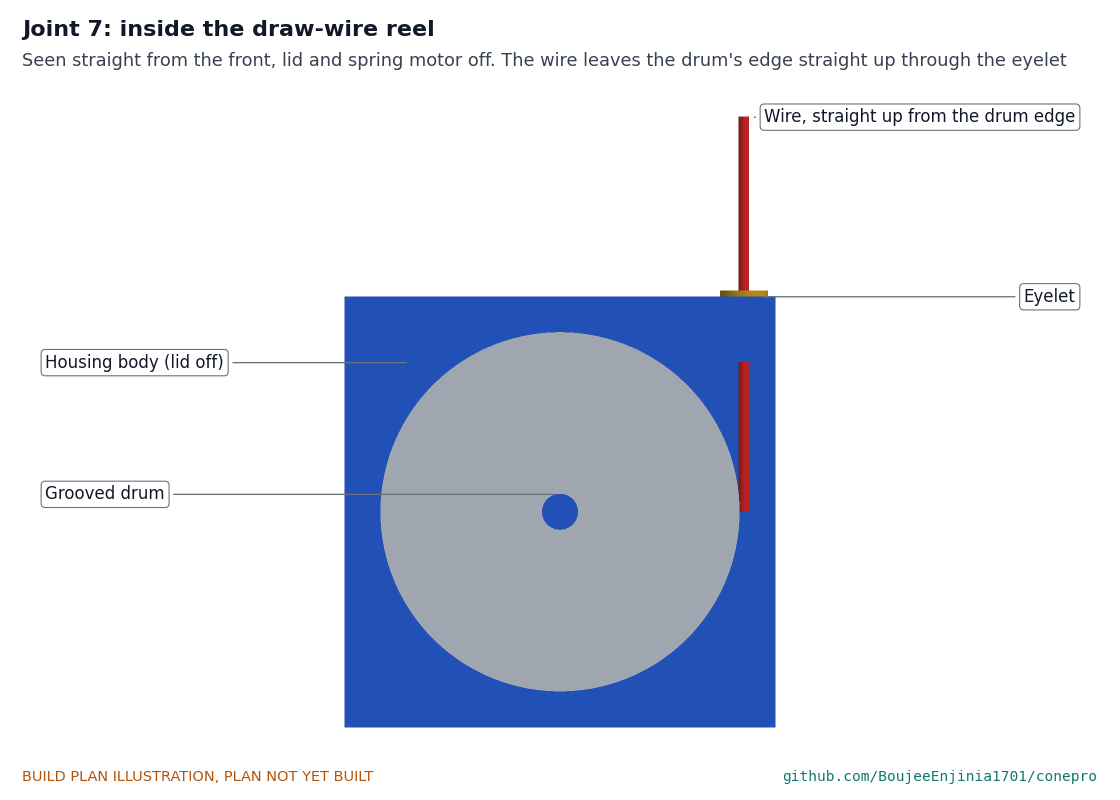
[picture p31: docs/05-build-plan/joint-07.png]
Figure 22. Joint 7: inside the draw-wire reel


*Figure 22. The drum's right-hand edge sits under the eyelet, so the wire leaves the drum straight up.*

The shaft runs in the two bearings in the back boss; the drum and spring motor sit on it, the magnet faces the sensor board on the lid 1.4 mm away. At the arm, the wire passes up through the eye, through the preloaded spring and into a crimped end stop:

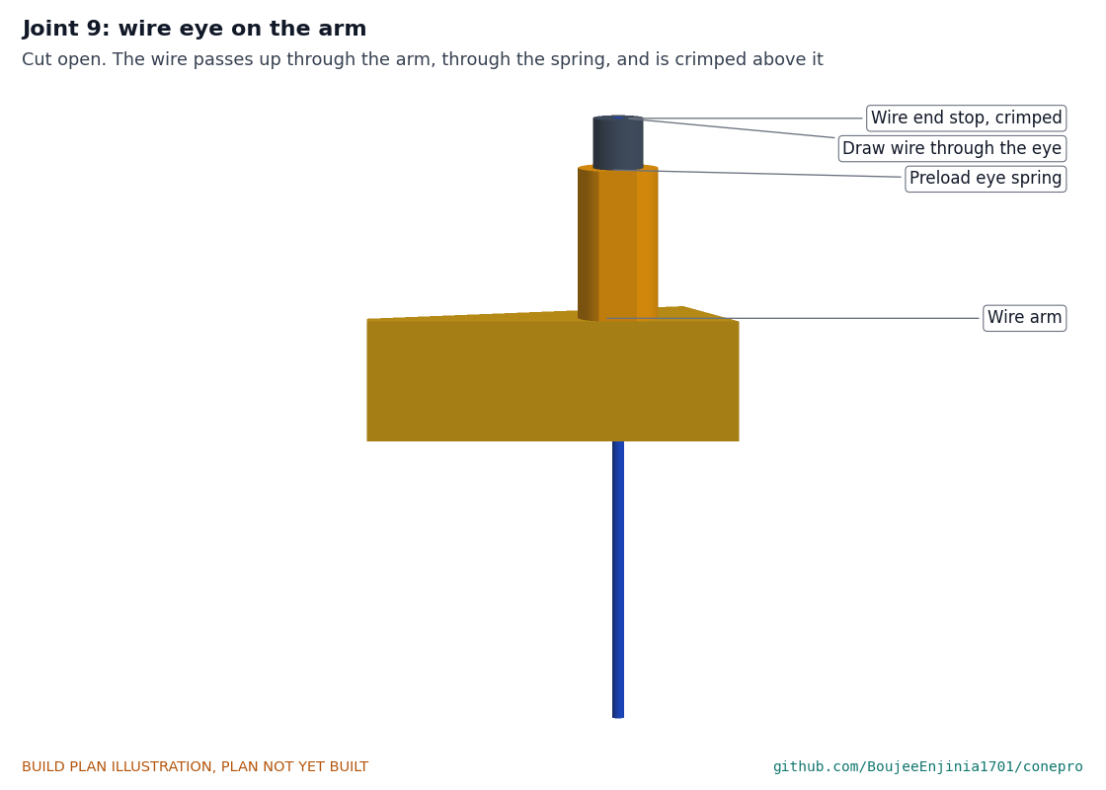
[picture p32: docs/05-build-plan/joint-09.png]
Figure 23. Joint 9: wire eye on the arm


*Figure 23. The spring sits on top of the arm; the end stop is crimped on the wire above it.*

**Check before moving on.** The drum runs true within 0.05 mm; the wire pays out and rewinds smoothly in one layer over its full length.

### 3.13 Logger box and wiring

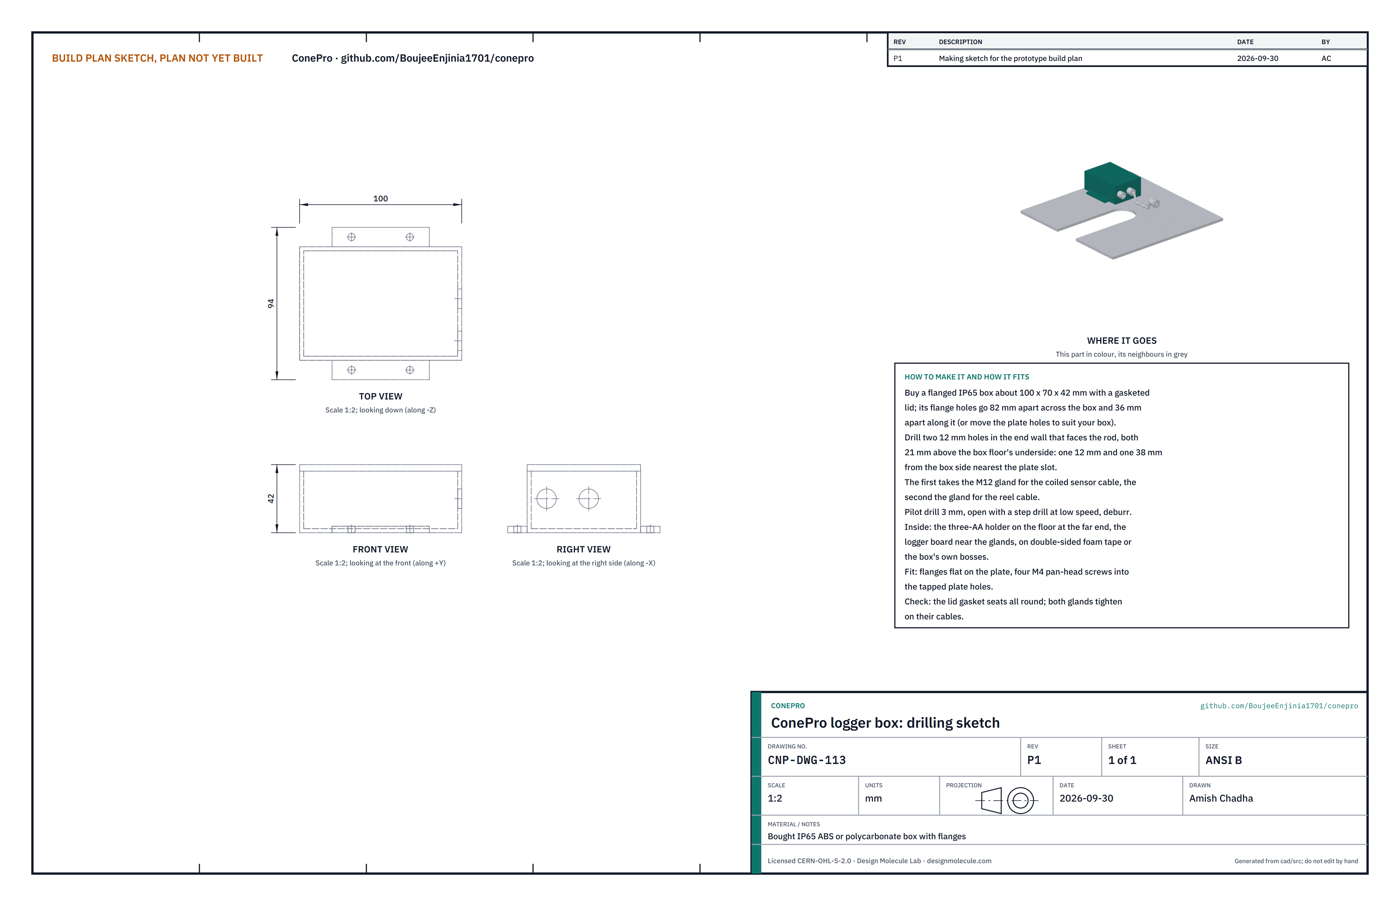
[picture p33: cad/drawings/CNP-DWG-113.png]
Figure 24. Drilling sketch of the logger box


*Figure 24. Logger box drilling sketch (CNP-DWG-113).*

**What it is and what it is made from.** The sealed box on the plate that holds the BLE logger board and three AA cells. A bought flanged IP65 box about 100 x 70 x 42 mm and two M12 cable glands.

**How to make it.**

1. Drill two 12 mm holes in the end wall that will face the rod, both 21 mm above the underside of the box: one 12 mm and one 38 mm from the side nearest the plate slot. Pilot 3 mm, open with a step drill at low speed, deburr.
2. Fit the glands: the first for the coiled pad cable, the second for the reel cable.
3. Fix the cell holder on the floor at the far end and the logger board near the glands, on the box's bosses or double-sided foam tape.
4. Wire as Figure 25 shows.

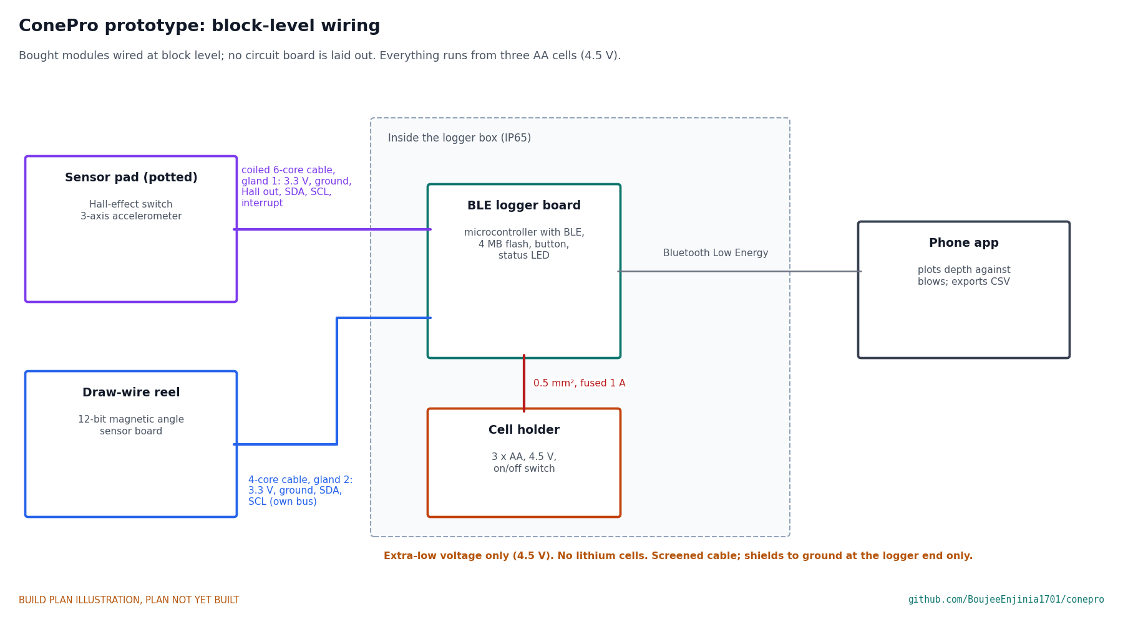
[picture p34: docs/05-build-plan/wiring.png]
Figure 25. Block-level wiring


*Figure 25. Block-level wiring. No circuit board is laid out at this stage; bought modules are wired at block level.*

1. Coiled cable, pad to logger, six cores: 3.3 V, ground, Hall output, the two bus lines and the accelerometer's interrupt.
2. Reel cable, four cores: 3.3 V, ground and the two bus lines of the angle sensor, on their own bus.
3. Cell holder to the logger board's battery input through a 1 A fuse and the on/off switch, 0.5 mm² wire.
4. Cable shields to ground at the logger end only.

**How it fits the parts next to it.**

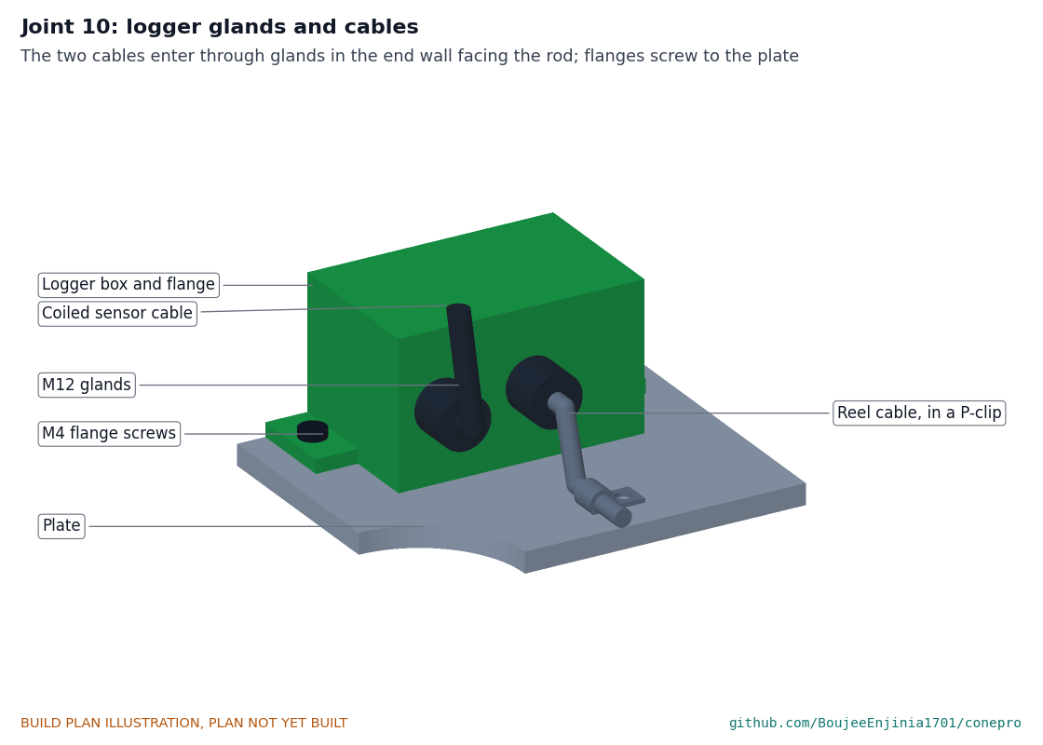
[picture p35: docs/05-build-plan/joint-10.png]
Figure 26. Joint 10: logger glands and cables


*Figure 26. Both cables enter through glands in the end wall; the flanges screw to the plate.*

The flanges lie flat on the plate and four M4 pan-head screws go into the tapped holes. The reel cable lies on the plate in two P-clips.

**Check before moving on.** The lid gasket seats all round; both glands grip their cables; every wire continues end to end.

### 3.14 Bought components

Buy to specification, not brand. Line numbers are those of the bill of materials.

- **Magnets (line 4).** Sixteen 8 x 4 mm N42 nickel-plated discs, plus one spare.
- **Roll pin and handle parts (line 6).** 6 x 40 mm spring steel roll pin; 20 mm bullseye level; two closed-end rubber grips about 33 mm across and 100 mm long for 26 mm tube.
- **Reel parts (line 8).** Two 6 x 13 x 5 mm sealed ball bearings; 6 mm silver steel shaft; constant-force spring motor of about 3 N retracted and 5 N extended; 6 x 2.5 mm diametric magnet; 12-bit magnetic angle sensor board about 30 x 30 mm; 0.45 mm coated 7x7 stainless wire; a ceramic or brass wire eyelet; a compression spring about 8 mm outside diameter, 15 mm free length, 2 N/mm; a crimp sleeve.
- **Sensor pad parts (line 10).** Hall-effect switch and 3-axis MEMS accelerometer on a small board, both rated to 10,000 g shock; 4 mm elastomer sheet; 12 mm stainless worm-drive band clamp for 50 to 80 mm.
- **Logger (line 11).** BLE microcontroller board with 4 MB flash, button and LED; three-AA holder with a switch; flanged IP65 box about 100 x 70 x 42 mm; three M12 cable glands (two for the logger, one for the reel).
- **Coiled cable (line 12).** Six-core screened coiled cable about 1.2 m extended, with strain reliefs.
- **Reel cable (line 17).** Four-core screened cable about 0.5 m, 5 mm outside diameter; two 5 mm P-clips.
- **Fixings (line 14).** Stainless: 4 x M4 x 14 countersunk screws (reel), 4 x M4 x 10 pan-head screws (logger), 2 x M4 x 8 screws (P-clips), 4 x M3 x 10 screws (reel lid), 1 x M5 x 25 socket screw (clamp), 1 x M3 set screw (drum); 4 M4 and 4 M3 brass heat-set inserts; medium thread locker for the screws only, never the rod, anvil and cone joints; slow-setting epoxy; potting epoxy. Also on line 14: the end cap for the upper rod's stud, turned from 32 mm aluminium bar 24 mm long, tapped M12 x 1.75 21 mm deep (blind) with a fluted grip, and a printed vinyl label for the hammer.
- **Carry bag (line 13), extraction lever (line 15) and extension rod (line 16)** are not needed to build or check the prototype.

## 4. Putting it together

In each picture the parts already fitted are grey and the part being fitted is in colour, with an arrow showing the way it goes in. Long rods are drawn short where only one end matters.

### Step 1: cone onto the lower rod

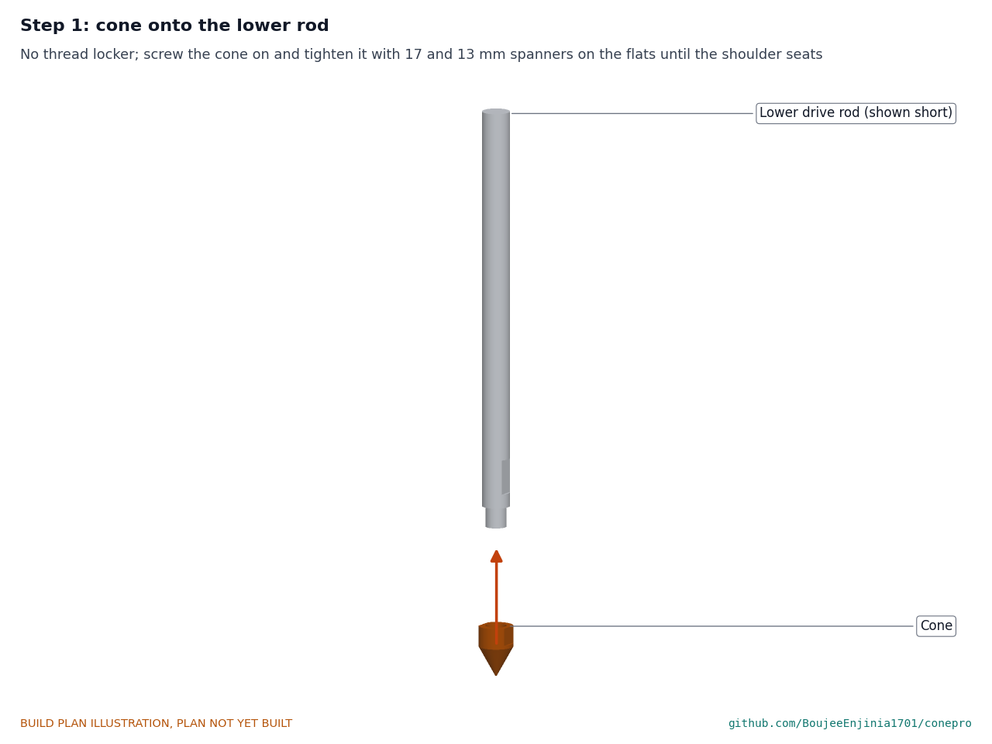
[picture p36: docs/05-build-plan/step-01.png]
Step 1


No thread locker (the cone is swapped for disposable cones); screw the cone on by hand, then put a 17 mm spanner on the cone's flats and a 13 mm spanner on the rod's flats and tighten until the shoulder seats firmly.

### Step 2: clamp collar onto the lower rod

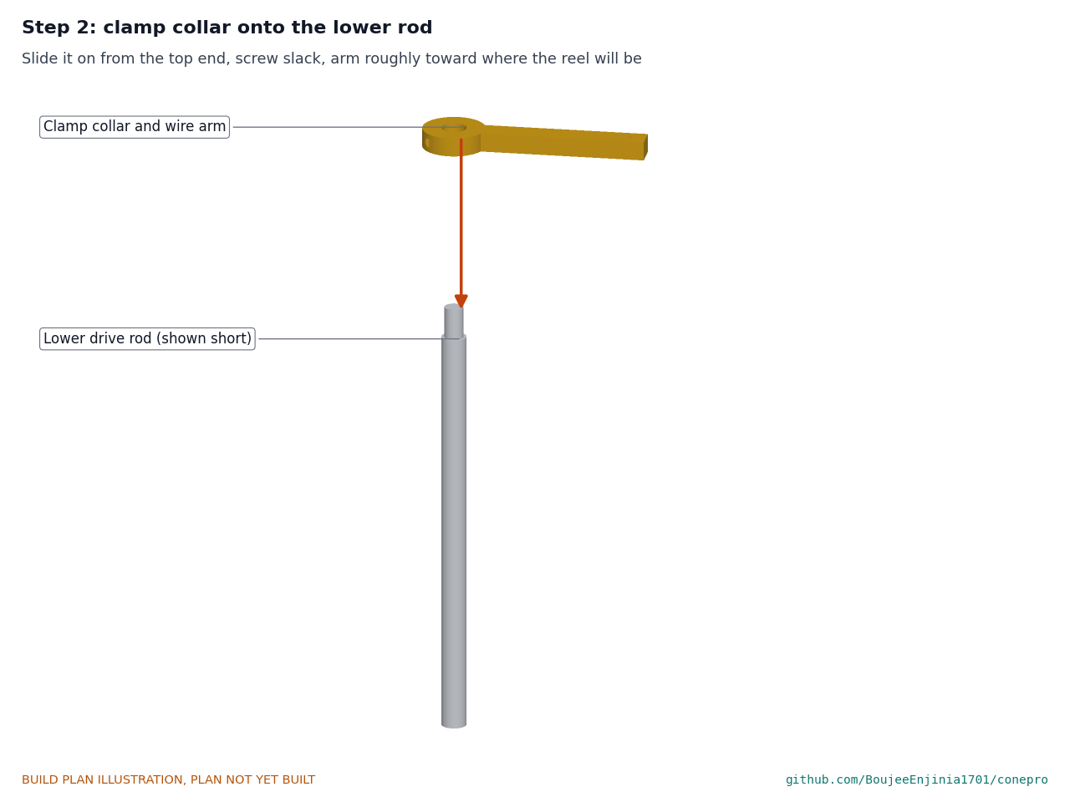
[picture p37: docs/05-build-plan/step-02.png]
Step 2


Slide the collar on from the top end with its screw slack.

### Step 3: anvil onto the lower rod

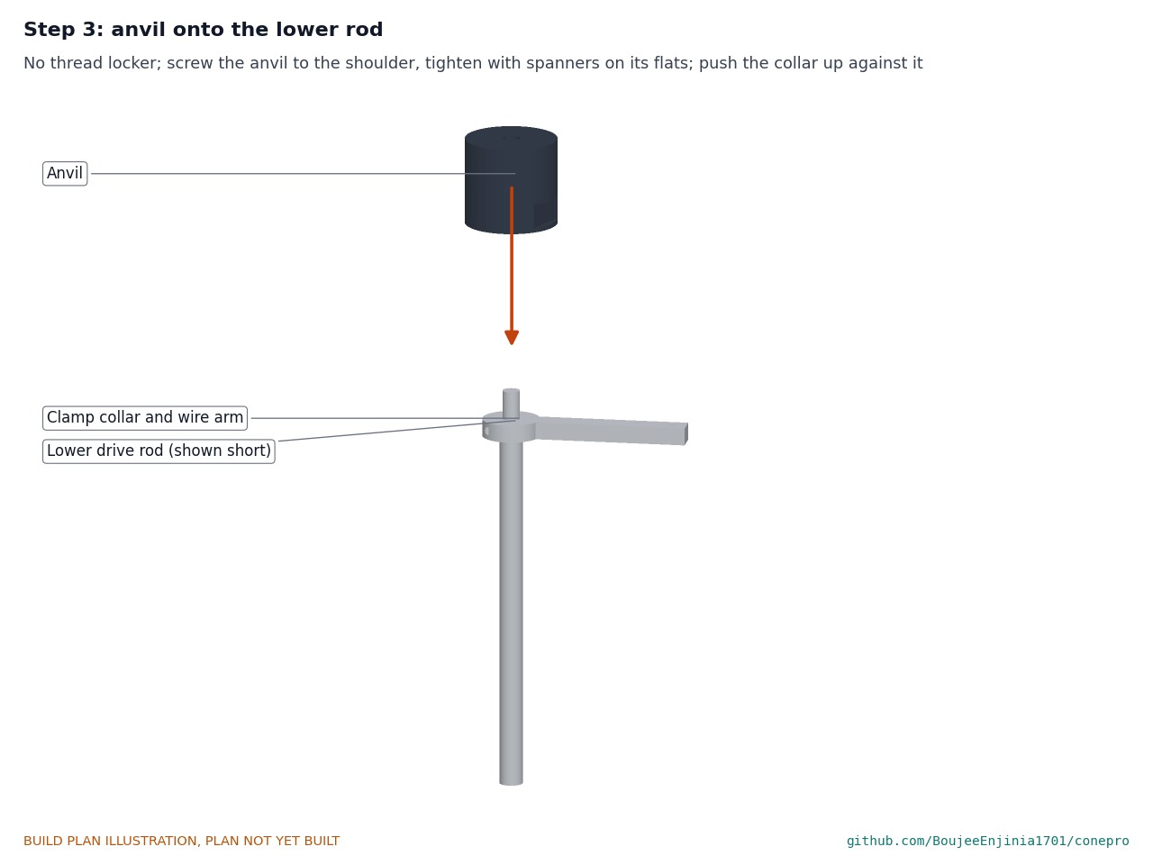
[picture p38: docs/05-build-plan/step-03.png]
Step 3


No thread locker; screw the anvil down to the shoulder and tighten it with a 55 mm spanner on its flats against a 13 mm spanner on the rod's flats. Push the collar up against the anvil's underside and snug its screw; it is aimed at the reel in step 13.

### Step 4: sensor pad and band onto the anvil

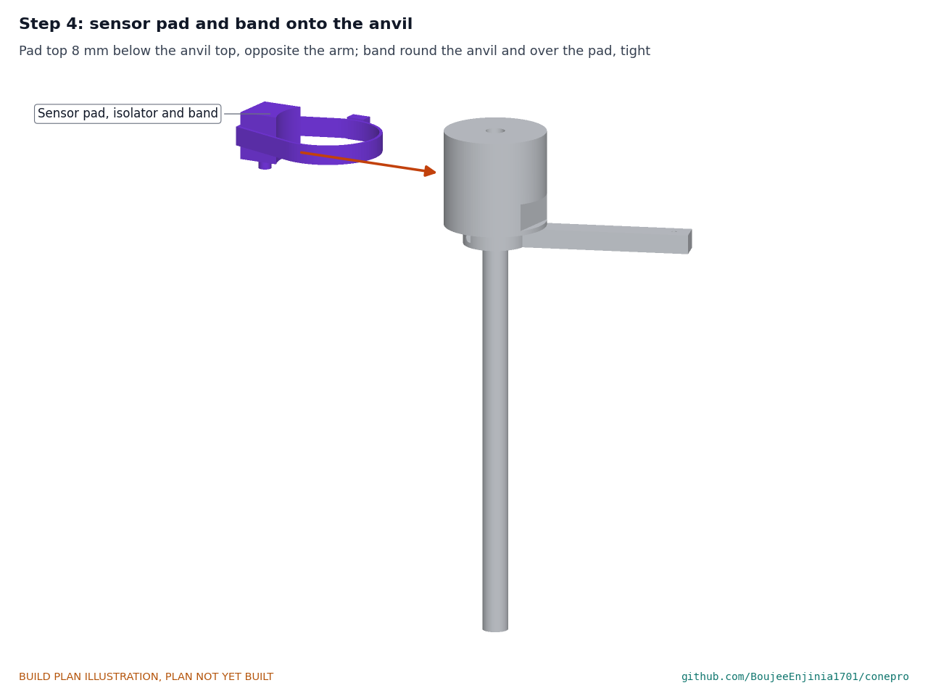
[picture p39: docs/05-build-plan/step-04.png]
Step 4


Hold the pad on the side of the anvil opposite the arm with its top 8 mm below the anvil top; pass the band round the anvil and over the pad and tighten it. Lead the coiled cable down.

### Step 5: hammer onto the upper rod, end cap on

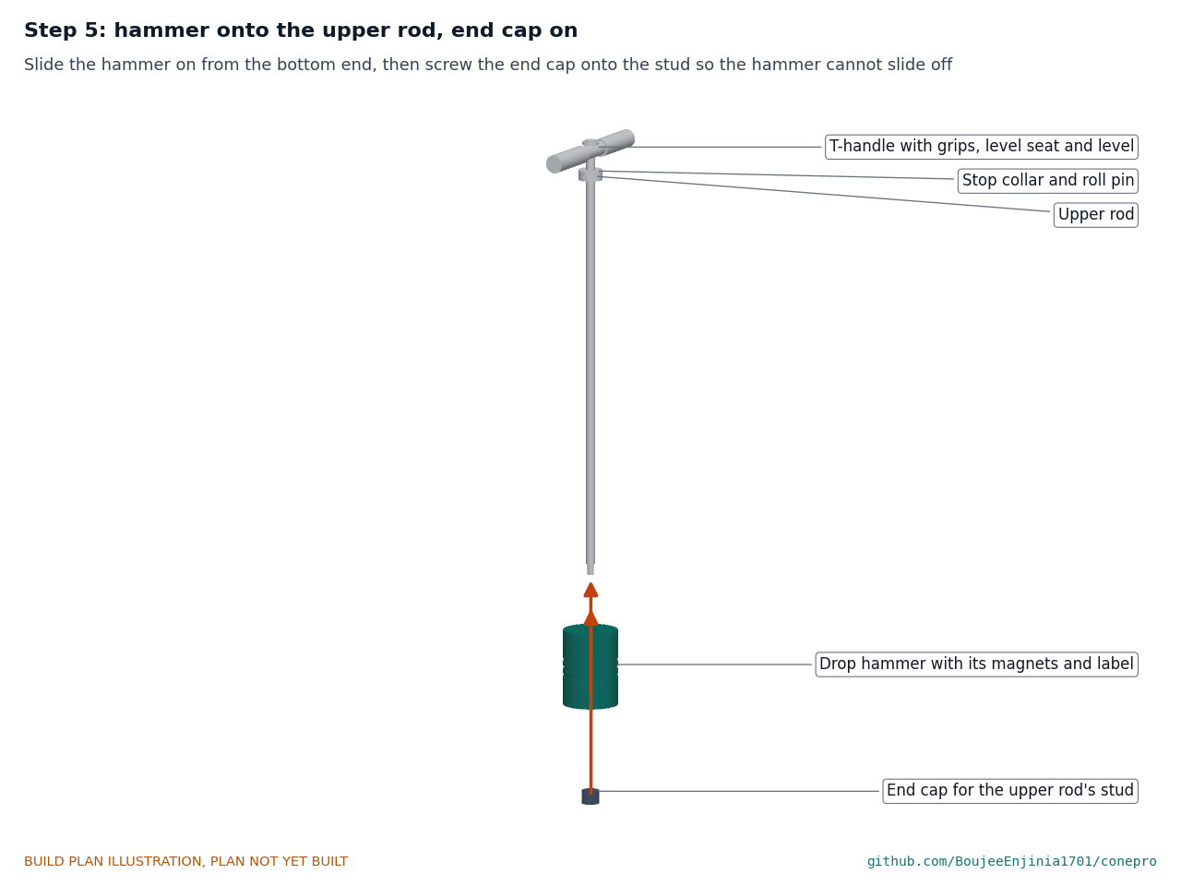
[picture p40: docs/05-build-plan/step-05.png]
Step 5


The upper rod already carries the pinned stop collar and the welded handle. Hold it handle down and slide the hammer on from the bottom end, strike face toward the stud, then screw the end cap onto the stud. **Hold point:** from now on keep a hand on the hammer whenever the rod is not upright on the anvil.

### Step 6: hammer assembly into the anvil

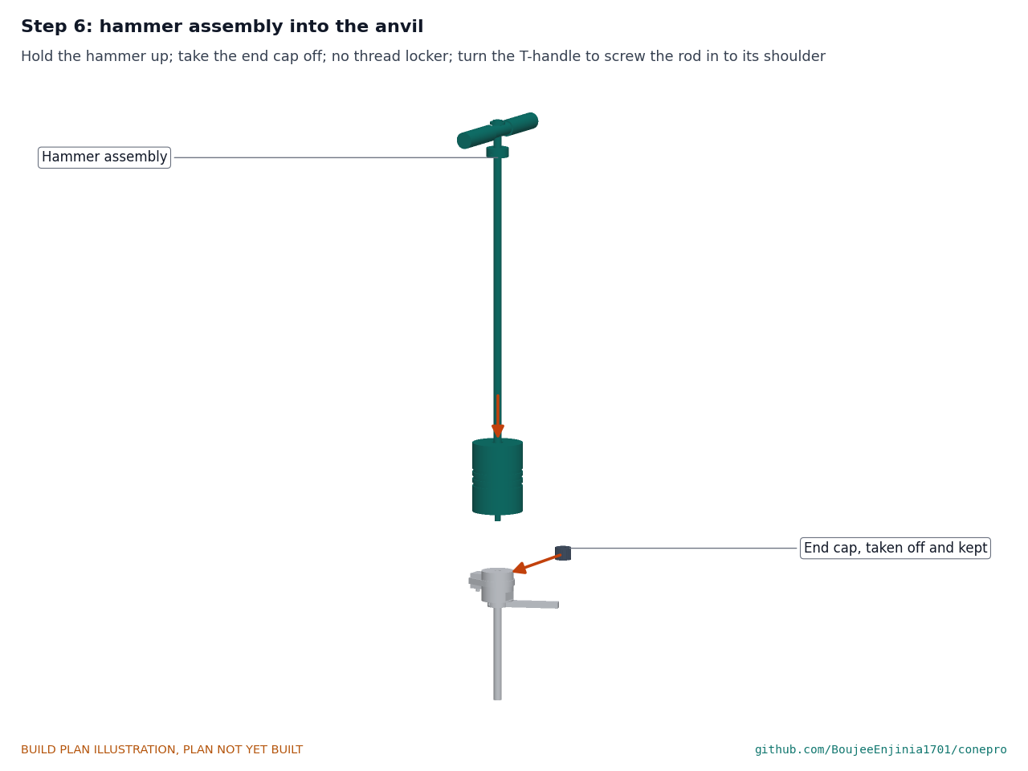
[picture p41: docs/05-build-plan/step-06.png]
Step 6


Hold the hammer up at the stop; take the end cap off the stud; screw the upper rod into the anvil to its shoulder, with no thread locker, turning it by the T-handle while a 55 mm spanner holds the anvil. Keep the end cap in the bag. Lower the hammer gently onto the anvil.

### Step 7: drum and shaft into the reel housing

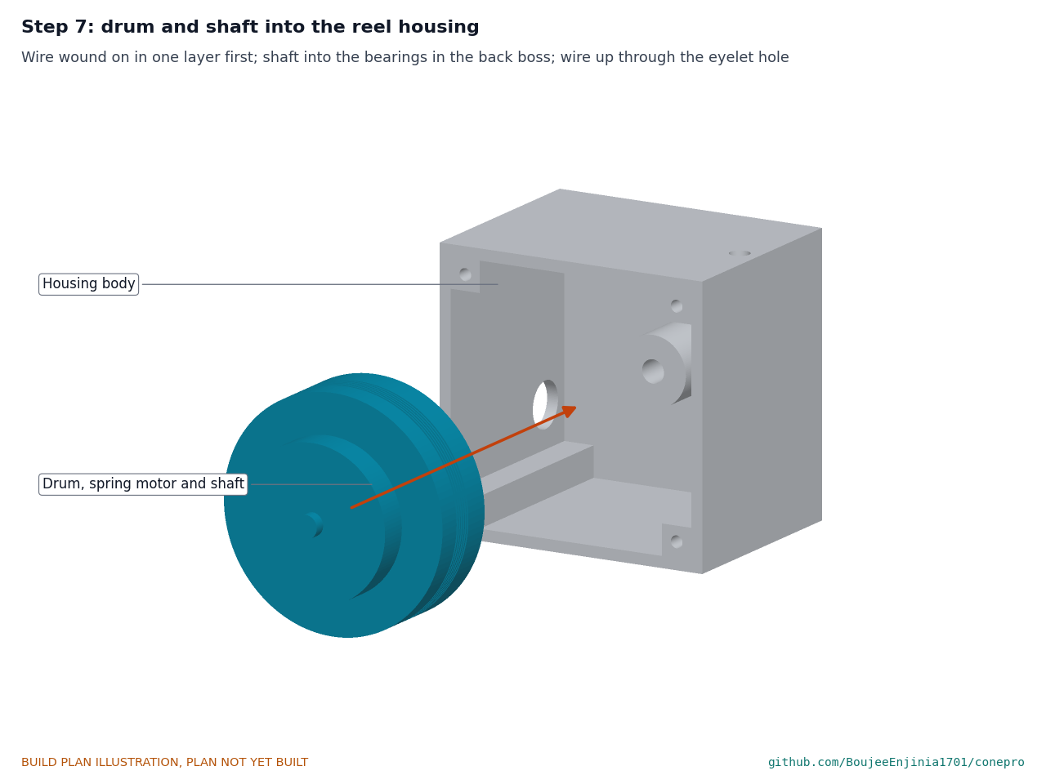
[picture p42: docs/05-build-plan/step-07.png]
Step 7


With the wire wound on and the spring motor and magnet fitted, push the shaft into the bearings from the front and lead the wire end up through the eyelet hole.

### Step 8: lid, sensor board and eyelet

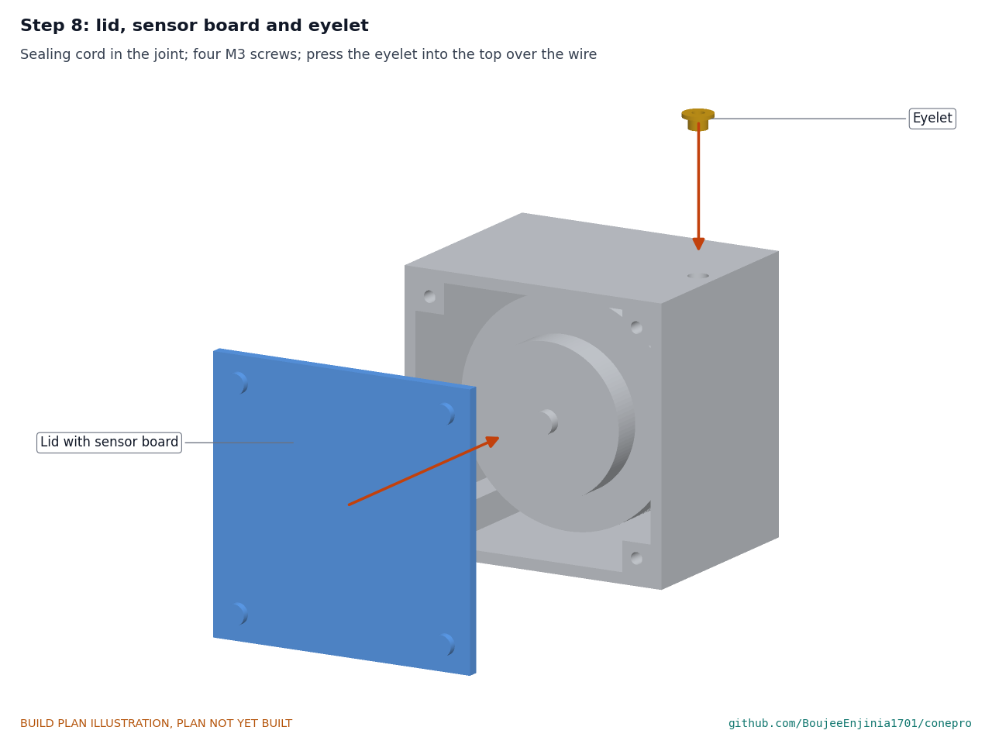
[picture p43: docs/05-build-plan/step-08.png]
Step 8


Fix the sensor board to the lid's pad facing the magnet. Lay the sealing cord, fit the lid with four M3 screws, and press the eyelet into the top over the wire. Fit the reel's cable gland.

### Step 9: reel onto the plate

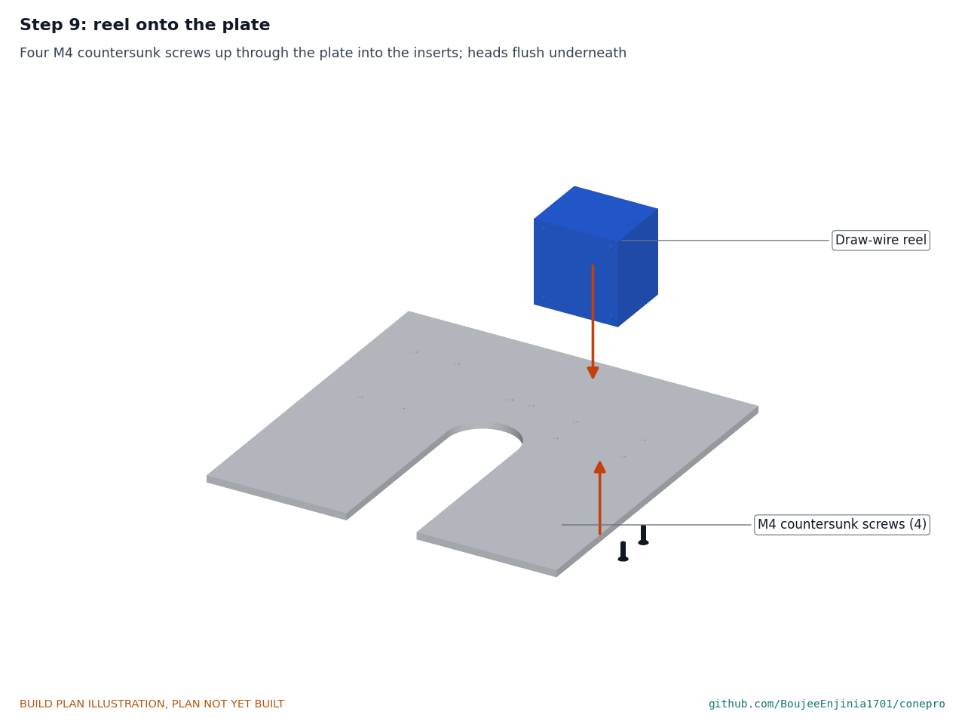
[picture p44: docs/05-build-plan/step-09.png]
Step 9


Four M4 countersunk screws up through the plate into the inserts; the heads sit flush underneath.

### Step 10: logger onto the plate

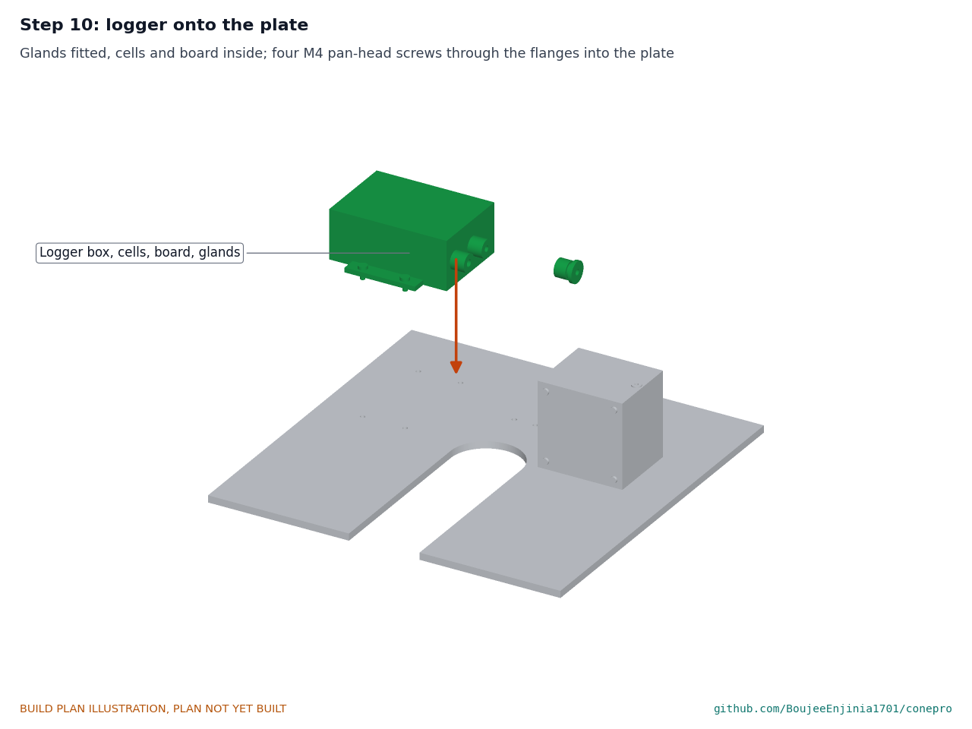
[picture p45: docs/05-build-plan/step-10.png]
Step 10


Glands fitted, cells out, board and holder inside. Four M4 pan-head screws through the flanges into the plate.

### Step 11: reel-to-logger cable

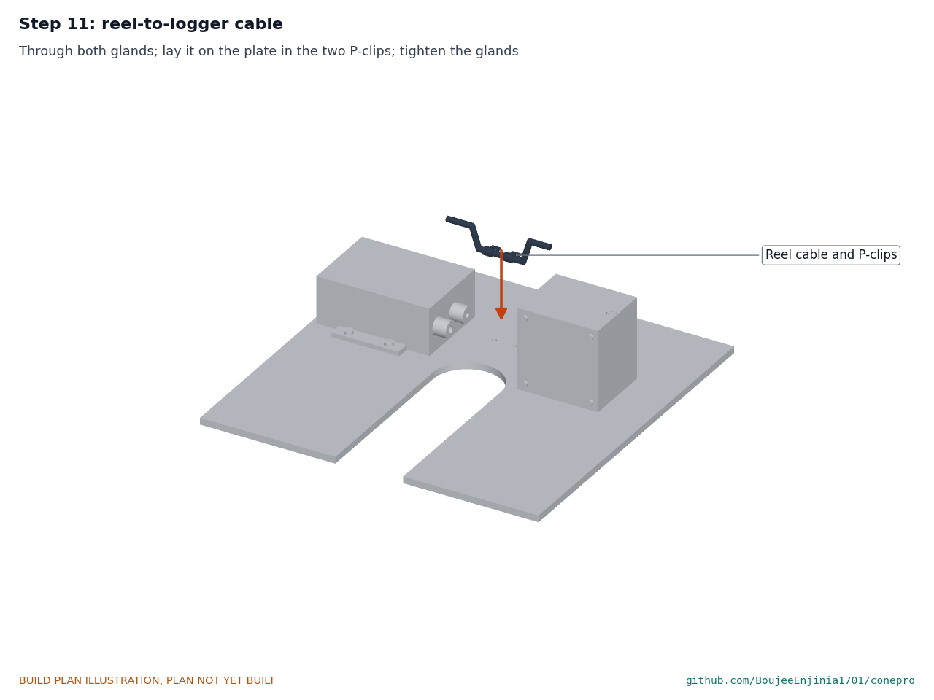
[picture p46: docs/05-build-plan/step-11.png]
Step 11


Pass the cable through both glands, connect it at both ends, lay it on the plate in the two P-clips and tighten the glands. **Hold point:** the wiring checks of section 3.13 pass before the cells go in.

### Step 12: plate round the rod at the test point

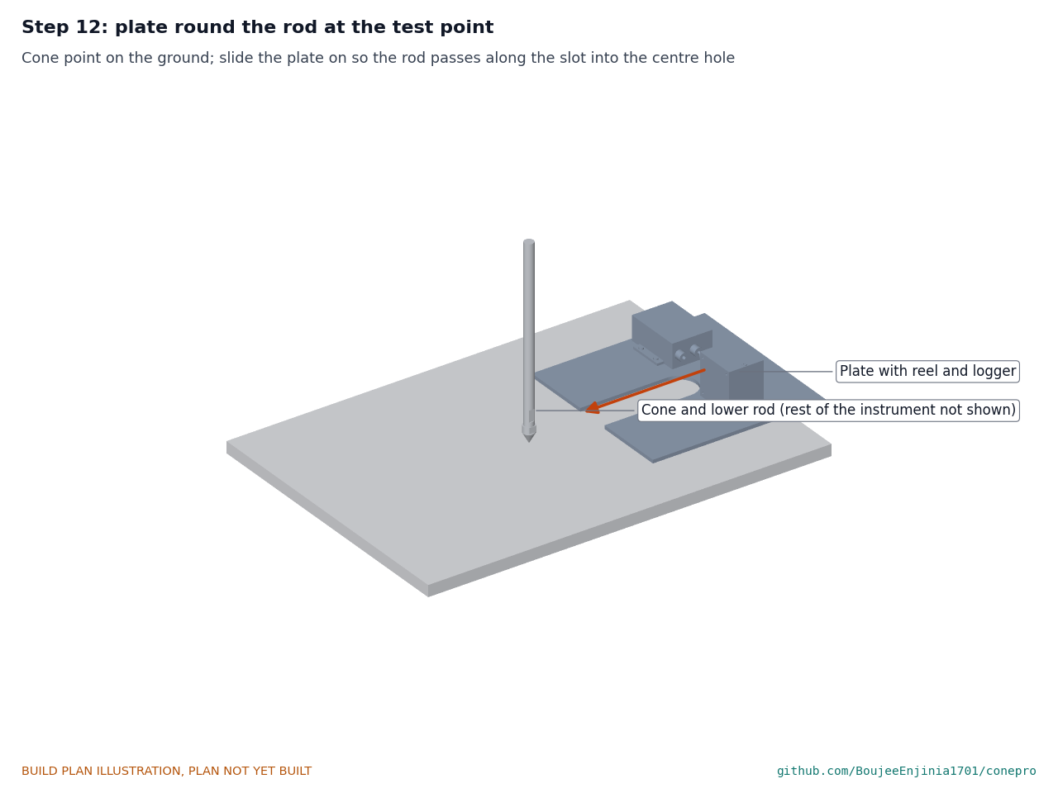
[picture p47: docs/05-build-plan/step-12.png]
Step 12


Stand the instrument with its cone point on the ground. Slide the plate on so the rod passes along the slot into the centre hole, reel toward the clamp arm.

### Step 13: wire to the arm and cable to the logger

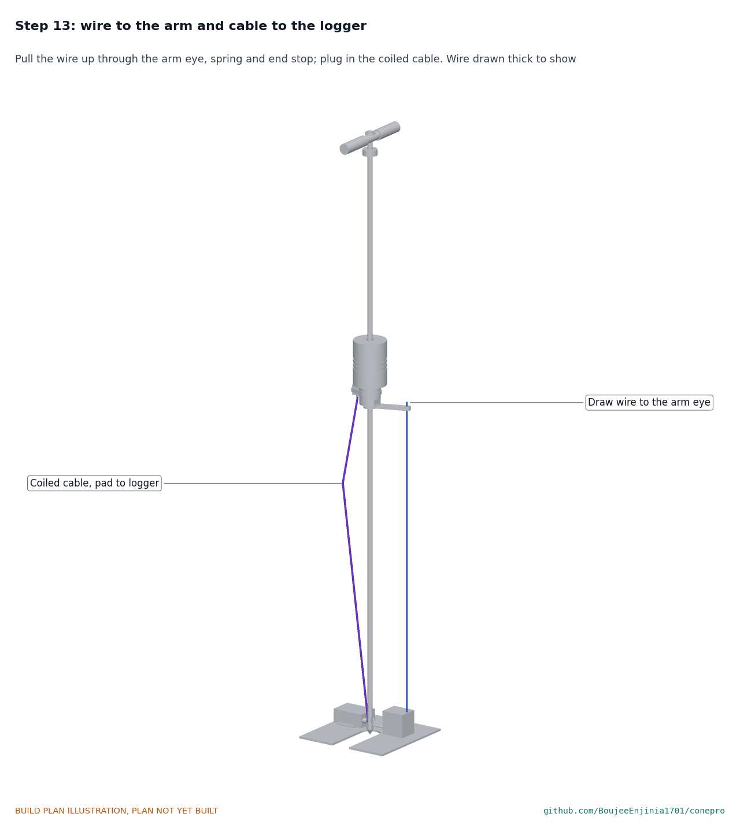
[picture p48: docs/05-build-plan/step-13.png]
Step 13


Turn the clamp arm so its eye is straight above the wire exit and tighten the M5 screw. Pull the wire up through the eye, thread on the spring, crimp the end stop on the wire with the spring just touching the arm. Lead the coiled cable down to the logger's first gland and tighten the gland. **Hold point:** safety stop S4 in section 6.

## 5. First checks

These are the checks a TRL 4 test report would record; this plan only lists them. Requirement numbers are those of CNP-REQ-001.

*Table 2. First checks.*

| Check | Requirement | How | Pass when |
| --- | --- | --- | --- |
| Hammer mass and drop | R1 | Weigh the hammer; measure from the anvil top to the hammer face at the stop | 8.00 kg within 10 g; 575 mm within 2 mm |
| Cone size and angle | R1 | Calipers and an angle gauge | 20.0 mm within 0.1 mm; 60° |
| Rod joints | R1 | Look at each shoulder with the joint tight | No gap at any shoulder |
| Hammer slides freely | R1 | Lift to the stop and let go, ten times | It falls freely every time and lands square |
| Wire runs freely | R2, R5 | Push the arm down the full 850 mm by hand and let it rise | The wire pays out and rewinds in one layer, with no slack at the drum |
| Depth reading | R2 | Logger on, rod vertical in a bench stand; compare the reading with the engraved rod at ten points over 850 mm | Within ±1 mm at every point |
| Blow count | R3 | Twenty blows on a soft target (a crate of sand) | Twenty blows counted, none extra |
| Tilt warning | R6 | Lean the rod past 5° | The warning shows between 4.7° and 5.3° |
| Clamp holds | R11 | Twenty blows, then look at the collar and arm | The collar is still against the anvil; the arm has not turned |
| Pad holds | R11 | After the twenty blows, look at the pad and band | No movement, no cracks in the potting |
| Logger sealed | R11 | Look at the lid gasket and both glands | Gasket even all round; glands grip their cables (the spray test comes later) |
| Mass and packed length | R10 | Weigh the set in its bag; measure the longest piece | 15.8 kg (16 kg or less); heaviest piece 9.96 kg; 1.1 m or less |

## 6. Safety stops

Stop at each point. Carry on only when everything listed is true.

- **S1. Before the first lathe or drill work on hardened steel.** Safety glasses on; the part held in a chuck or vice, never by hand; chips cleared with a brush.
- **S2. Before welding the handle.** A welding screen and gloves; no flammable material within 3 m; the rod and tube clamped square; or the job sent to a shop.
- **S3. Before the hammer goes on the upper rod.** The stop collar pin is fully driven and the handle welds are sound (no cracks, full fillet all round). The magnets are cured in their pockets.
- **S4. Before the first blow.** All three rod joints are tight on their shoulders, checked with spanners (no thread locker; check them again before each test); the clamp collar is tight against the anvil; the pad band is tight; no cable crosses the hammer's path or the pad top; safety glasses and hearing protection on; feet clear of the plate edge; nobody within 2 m.
- **S5. Before any blow at a real test point (outside this plan).** A utility locate for that point; the ground is not the edge of a trench or excavation.
- **S6. Before packing.** The upper rod is unscrewed with a hand under the hammer, and the hammer is held until the screw-on end cap is on the rod's M12 stud, so it cannot slide off the rod's lower end (the label on the hammer says so).

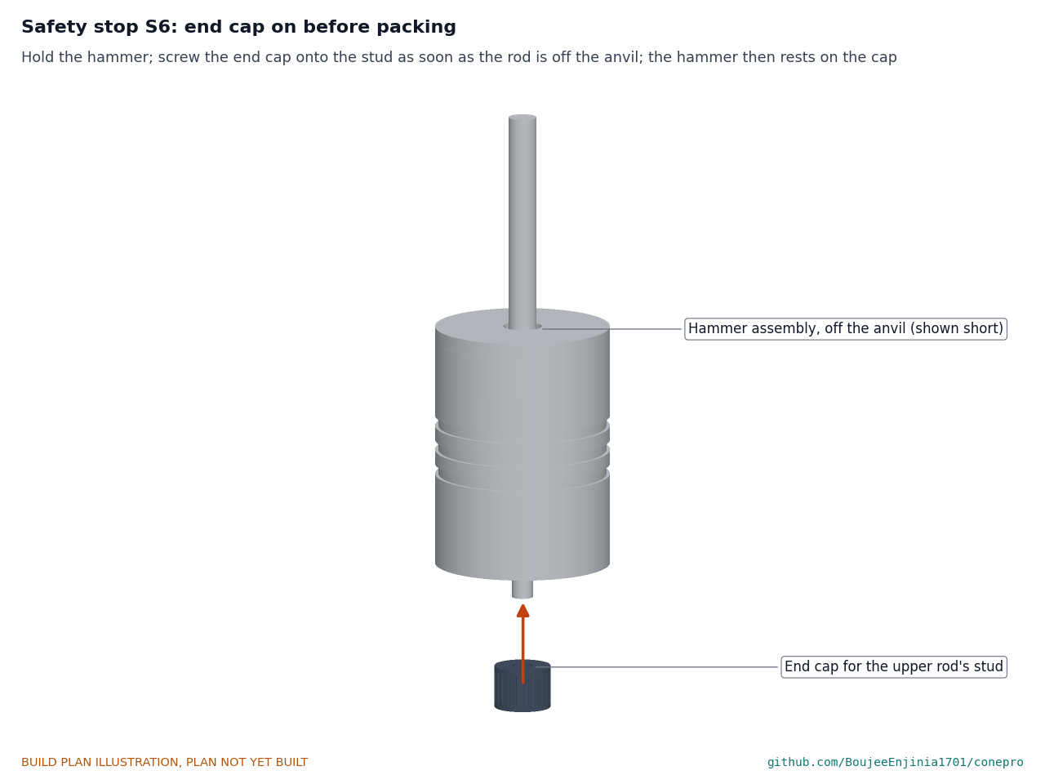
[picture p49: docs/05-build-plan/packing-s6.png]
Safety stop S6


## 7. Tools, skills and workspace

**Tools.** A metal lathe that can screw-cut M12 x 1.75 and a 1 mm pitch, with a 4-jaw chuck or collets for 16 mm rod and a steady for 1 m rods (or a machine shop for the turned parts); bench drill; drills 1 to 16 mm and a step drill to 12 mm; M3, M4, M5 and M12 x 1.75 taps; 13 mm and 17 mm spanners and a 55 mm (or large adjustable) spanner for the rod joints; a milling machine, or a file and a guide, for the spanner flats; hacksaw or bandsaw and a jigsaw with a metal blade; files; countersink; MIG or TIG welder (or a welding shop); 3D printer that prints ASA or PETG with a bed of at least 80 x 80 mm; soldering iron for heat-set inserts and wiring; crimp tool; calipers, steel rule, engineer's square, angle gauge; scale to 10 kg reading 10 g; multimeter.

**Skills.** Lathe turning and threading, marking out, drilling and tapping, basic welding (or a shop for it), through-hole soldering. All circuits run at 4.5 V or less from AA cells; no mains wiring is part of this build.

**Workspace.** A bench about 1.5 m long so the rods can lie flat; a metalwork corner kept apart from the electronics; a ventilated place for the printer and for welding.

**Personal protective equipment.** Safety glasses at the lathe, drill and every blow; hearing protection for blows and sawing; gloves for cut edges and welding; no gloves near a turning lathe or drill.

## 8. Where the numbers come from

- Model and constructability checks: `cad/src/model.py` (`python cad/src/model.py --check`, 73 checks); STEP and STL exports in `cad/step/` and `cad/stl/`.
- Pictures: `cad/src/build_plan_media.py`, using `.kit/build_views.py`; written to `docs/05-build-plan/` and `cad/drawings/CNP-DWG-101` to `CNP-DWG-113`.
- General arrangement: `cad/drawings/CNP-DWG-001.pdf`, Rev P6.
- Calculations: `docs/04-calcs/01-sizing.md` (CNP-CAL-001 v0.6) and `docs/04-calcs/sizing.py`; drop and hammer [A2], [A3], stroke [D1], [D2], depth error [E1] to [E4], wire spring [E5], magnet field [F1], masses [C1] to [C3], cost [L1].
- Bill of materials: `bom/bom.csv`.
- Decisions: `docs/decisions/0004-design-for-construction.md` (CNP-DDR-004), with CNP-DDR-001 to CNP-DDR-003; every decision made in `docs/06-design-decisions.md` (CNP-DEC-001).
- Requirements: `docs/03-requirements.md` (CNP-REQ-001 v0.8).

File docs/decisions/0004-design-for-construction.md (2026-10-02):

---
doc_id: CNP-DDR-004
title: ConePro design for construction
project: ConePro
doc_type: Design decision record
version: "0.3"
status: Draft
date: '2026-10-02'
author: Amish Chadha
license: CERN-OHL-S-2.0
revisions:
- version: "0.1"
  date: '2026-09-30'
  author: Amish Chadha
  change: Changes that make the concept physically buildable, with the reason for each; made under Amish's 2026-09-30 instruction to make the design physically buildable; open for his review
- version: "0.2"
  date: '2026-10-01'
  author: Amish Chadha
  change: Budget treated as a value-engineering target, with cost question A2 replaced by a value-engineering note
- version: "0.3"
  date: '2026-10-02'
  author: Amish Chadha
  change: Accepted by Amish with one exception (no thread locker on the rod, anvil and cone joints), including the recommendation for A1
---

# 0004: Design for construction

- **Date:** 2026-09-30
- **Status:** accepted with one exception. Amish, 2026-10-02: "i approve your recommendations for all 555 open decisions." This covers every change in Tables 1 and 2 and the recommendation for A1 in Table 3, now decided as recommended and recorded in the design decisions register (CNP-DEC-001). Every change was made under Amish's 2026-09-30 instruction to make the design physically buildable.
- **Exception (P2):** no thread locker on the rod, anvil and cone joints. The upper rod is unscrewed from the anvil for packing and disposable cones are swapped in stiff ground, so a thread locker would have to be broken and reapplied every time; the shoulders, not the threads, carry the blows. The joints are tightened with spanners and checked before each test.

## Context

On 2026-09-30 Amish asked for every repo to get an illustrated prototype build plan and wrote: "If you are realising that the design cannot be built as per concept - fix the design assumptions to match and be physically feasible as you draw the illustrations." The ConePro model of CNP-DDR-003 was a massing model with correct proportions and interfaces, but parts of it could not be made or joined as drawn: the rods had no threads, the wire arm ran through the rod, the stop collar and handle stem overlapped the rod and the tube, the band ran through the sensor pad, the reel was a solid block, and nothing held the reel or logger to the plate.

The model (`cad/src/model.py`) now builds every part as a separate solid, including fixings, and runs 64 constructability checks (`python cad/src/model.py --check`): parts that must touch do touch with no overlap, parts that must stay apart keep their stated clearance, and no two of its 39 components (parts and fixing sets) overlap. All 64 pass.

## Decision

*Table 1. Changes made to the model, the BOM and the calculations.*

| # | Problem in the concept | Change made | Why this way |
| --- | --- | --- | --- |
| P1 | The cone's 5 mm parallel shoulder could not hold a threaded hole: a 12 mm tapped hole of useful depth would break out through the 60° point. | The shoulder is 12 mm long (cone 29.3 mm overall), tapped M12 x 1.75 to 14 mm deep in its top face; hardened after tapping. | Keeps the 20 mm, 60° ASTM D6951 point. The rod shoulder bears on the cone's top face, so the thread only locates the cone. The instrument stands 7 mm taller (1,874 mm). |
| P2 | Rods, anvil and cone met as plain cylinders with no joint. | M12 x 1.75 studs turned on the rod ends (12 mm at the cone, 20 mm at the anvil) and M12 tapped holes 24 mm deep in both anvil faces; every joint seats on a square 16 mm shoulder, with medium thread locker (exception accepted 2026-10-02: no thread locker; tightened with spanners and checked before each test). | Blows pass through the shoulders, not the threads. One thread size for every joint; ordinary lathe work. |
| P3 | The handle stem overlapped the T-handle tube; the stop collar was solid where the rod passed through it; neither had a fixing. | The upper rod runs up through the stop collar and through a 16 mm cross hole in the tube, its top flush with the tube; the tube is welded to the rod; the collar is fixed by a 6 mm roll pin drilled through collar and rod at the drop height. | The pin lets the 575 mm drop be set on the finished hammer before drilling. Upper rod 776 mm above the anvil. |
| P4 | The bubble level was a block resting on the round tube along a line, with no fixing. | A 30 x 5 mm steel seat disc is welded on the rod top; a 20 mm bullseye level is bonded in a 3 mm recess in it. | A bullseye on the rod axis reads plumb directly; overall height is unchanged. |
| P5 | The hammer magnets had no defined position and would sit in the striking face. | Sixteen 8.2 mm pockets on an 82 mm circle, outside the 64 mm anvil strike area; magnets bonded 0.5 mm below the face; hammer length 136.5 mm to keep 8.00 kg. | Magnets are never struck. The Hall switch sees them from 8.5 mm instead of 8 mm; the calculated field between magnets is still 2.3 times the switch operate point [F1]. |
| P6 | The wire arm ran through the rod and the clamp collar; the arm had no joint to the collar; and only friction held the collar against the rod's acceleration of thousands of g. | Collar and arm cut in one piece from 12 mm aluminum plate (40 mm boss, 16 mm wide arm, 3.2 mm wire eye), split with a saw slit and an M5 clamp screw; its top face butts the underside of the anvil. | The anvil carries the clamp at every blow, so it cannot slip up the rod. One flat part, cut, drilled and tapped. The clamp lands on the reel 4 mm later, so the stroke grows (P1 and P6 together: 928 to 939 mm). |
| P7 | The band clamp passed through the sensor pad, the pad's flat face touched the round anvil on a line, and the isolator was not drawn. | The pad's face is curved to 36 mm radius on a 4 mm curved elastomer isolator; the band goes round the anvil and over the pad's outer face, pressing both on; a strain relief boss carries the cable out underneath. | Full contact through the isolator; a stock worm-drive band does the clamping; any 50 to 80 mm anvil works with a pad face of anvil radius plus 4 mm. |
| P8 | The draw-wire reel was a solid block, and a drum centred under the exit would let the wire leave 30 mm away from the exit eyelet. | A printed housing (body with posts and a bearing boss, screwed lid), a 60 x 20 mm grooved drum on a 6 mm shaft in two bearings, a spring motor, a shaft magnet and the angle sensor board on the lid. The drum is set so its edge is under the exit: the housing centre moves 30.7 mm toward the rod; the wire exit point and the housing size are unchanged. | The wire leaves the drum vertically through the eyelet, as the error budget assumes. The housing still clears the rod by 32 mm and the 72 x 60 x 72 mm size of CNP-DDR-003 is kept. |
| P9 | The reel and the logger sat on the plate with no fixing. | Reel: four M4 countersunk screws up through the plate into heat-set inserts in the housing posts. Logger: a flanged IP65 box held by four M4 screws into tapped holes in the plate. | Nothing stands proud under the plate, so it still lies flat on the ground. |
| P10 | No cable joined the reel's angle sensor to the logger (review item of 2026-09-26). | BOM line 17: a 4-core cable through M12 glands on the reel and the logger, lying on the plate in two P-clips ($6). | The sensor cannot work without it; it lies clear of the rod hole and below the arm's path. |
| P11 | The coiled cable ended inside the logger lid with no entry. | Two M12 glands in the logger end wall that faces the rod, for the coiled pad cable and the reel cable. | Sealed entries for IP65 (R11). |
| P12 | The wire ended at the arm with no eye spring or stop drawn. | The wire passes up through the arm's eye, through the preloaded eye spring of BOM line 8 and into a crimped end stop. | Matches the snap-tension calculation [E5]. |

*Table 2. Knock-on changes.*

| Item | Change | Reason |
| --- | --- | --- |
| Optional extension rod (BOM line 16) | M12 studs on both ends and a 20 mm OD x 40 mm coupling sleeve tapped M12 through; $15 to $16 | Two male-ended 16 mm rods cannot join without a sleeve, and a 16 mm rod is too thin to tap M12. The sleeve matches the cone diameter, so it follows the cone's hole. |
| Stroke and range | Stroke 928 to 939 mm, still limited by the wire arm on the reel; 850 mm usable unchanged [D1, D2] | P1, P6 |
| Depth error | Lean error at 850 mm after tilt correction 1.07 to 0.95 mm at 1° and 2.02 to 1.79 mm at 2° [E4] | Longer wire above the reel |
| Mass | Carried mass stays 15.7 kg; heaviest piece 9.83 kg [C2, C3] | Mass moves between parts; clamp 0.12 to 0.09 kg |
| Cost | Instrument $319 to $335; kit with both optional accessories $401, $1 over the $400 value-engineering target (see the register's Value engineering section) [L1] | Lines 6, 8, 14 and 16 repriced; line 17 added |
| Documents | CNP-CAL-001 v0.4, CNP-PRC-001 v0.6, CNP-REQ-001 v0.6; drawing CNP-DWG-001 Rev P5; making sketches CNP-DWG-101 to 113; build plan CNP-BLD-001; design decisions register CNP-DEC-001 | Follow the model. No requirement changes status. |

*Table 3. Proposed for Amish; A1 accepted as recommended on 2026-10-02.*

| # | Question | Options | Recommendation |
| --- | --- | --- | --- |
| A1 | When the upper rod is unscrewed from the anvil for packing, the 8 kg hammer can slide off its lower end onto the user's feet. Keeping the anvil on the upper rod instead makes the heaviest piece about 11.3 kg, over the 10 kg of R10. | (a) a screw-on end cap on the upper rod's M12 stud whenever it is off the anvil; (b) pack with the anvil on the upper rod and relax R10's heaviest piece; (c) leave it to the user guidance. | (a): a cheap cap that also protects the thread. This adds to the safety case, so it is Amish's decision. Accepted by Amish, 2026-10-02, with a label on the hammer saying so. |

(A2, on the kit cost, is now a value-engineering note: with both optional accessories the kit is $401 against the $400 value-engineering target, $1 over, and the instrument alone is $335.)

## Consequences

- With A1 accepted, a screw-on end cap goes on the upper rod's M12 stud whenever the rod is off the anvil, and a label on the hammer says so. With the P2 exception, the rod joints carry no thread locker and are checked before each test.
- `design_state: constructable` in `project.yaml`. The build plan CNP-BLD-001 shows every component and step in pictures generated from the model (`cad/src/build_plan_media.py`).
- Requirement status is unchanged: 9 met, 2 at risk (R2, R11), 4 not verifiable at TRL 3 (CNP-CAL-001 v0.4).
- The photoreal renders (`media/render-*.png`), `media/card.png`, `media/social-preview.png` and the appearance model `cad/src/product_model.py` still show the concept clamp, handle, pad and reel position; they need updating on Amish's Mac.
- Bought parts to confirm when ordered are in the register: the bubble level, spring motor, angle sensor board, flanged logger box, glands and band clamp.

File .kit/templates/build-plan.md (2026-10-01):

---
doc_id: PRJ-BLD-001
title: Project prototype build plan
project: Project name
doc_type: Build plan
version: "0.1"
status: Draft
date: YYYY-MM-DD
author: Amish Chadha
license: CERN-OHL-S-2.0
revisions:
  - version: "0.1"
    date: YYYY-MM-DD
    author: Amish Chadha
    change: First build plan; design made constructable
---

# Project prototype build plan

**Plan, not yet built.** How to build the first proof-of-concept prototype, component by component. Building and testing to it is TRL 4 work. Decisions still to be made are kept in the design decisions register (`docs/06-design-decisions.md`), not here.

## 1. What you are building

Every component, pulled apart and numbered in build order

One short paragraph: what the prototype is, how many components, which are made and which are bought, and the main ways they are made.

## 2. What changed to make it buildable

| Component | The concept had | The buildable design has | Why |
| --- | --- | --- | --- |

## 3. Making the components

### 3.1 Component name

Making sketch

**What it is and what it is made from.**

**How to make it.**

1. Mark out ...
2. Cut ...

**How it fits the parts next to it.**

Close-up of the joint

**Check before moving on.**

## 4. Putting it together

### Step 1: ...

Step 1

## 5. First checks

| Check | Requirement | How | Pass when |
| --- | --- | --- | --- |

## 6. Safety stops

## 7. Tools, skills and workspace

## 8. Where the numbers come from

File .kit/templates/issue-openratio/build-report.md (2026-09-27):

---
name: Build report
about: Tell us what happened when you built, printed or tested part of this design
title: "Build report: "
labels: build-report
---

This is a research and educational prototype, not a medical device. It is a TRL 3 concept and is not released for fabrication. If you build any part of it, you do so at your own risk. Reports help everyone.

**What you built** (part, sub-assembly or test)

**Materials, tools and settings**

**What worked**

**What did not work, with photos or measurements if you have them**

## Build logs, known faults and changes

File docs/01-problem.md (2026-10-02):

---
doc_id: CNP-PRB-001
title: ConePro problem statement
project: ConePro
doc_type: Problem statement
version: "0.4"
status: Draft
date: '2026-10-02'
author: Amish Chadha
license: CERN-OHL-S-2.0
revisions:
- version: "0.1"
  date: '2026-09-24'
  author: Amish Chadha
  change: Initial scaffold
- version: "0.2"
  date: '2026-09-25'
  author: Amish Chadha
  change: Populate to TRL 2 (users, context, constraints, prior work, open questions)
- version: "0.3"
  date: '2026-09-25'
  author: Amish Chadha
  change: Citations checked online and corrected (Kleyn report number, ORN 8 title); retrofit question closed by CNP-DDR-001 (D3)
- version: "0.4"
  date: '2026-10-02'
  author: Amish Chadha
  change: First co-design partner to approach, decided on 2026-10-02 (CNP-DEC-001)
---

# ConePro problem statement

Early site assessments need soil strength data within the hour, but laboratory geotechnical testing takes days to weeks, and the fast field alternative, the manual dynamic cone penetrometer (DCP), needs two people, a steel rule and a clipboard, and produces hand-written records that are slow to reduce and easy to get wrong. ConePro aims to keep the standard DCP test and remove the manual reading and transcription.

## The problem

The DCP is a simple, well-established field test. An 8 kg hammer dropped 575 mm drives a 20 mm, 60 degree cone into the ground on a 16 mm steel rod, and the penetration per blow (the DCP index, in mm per blow) gives a profile of soil strength with depth. ASTM D6951/D6951M standardizes the apparatus and method for shallow pavement applications and gives correlations from the DCP index to the California Bearing Ratio (CBR) ([ASTM D6951/D6951M-18](https://www.astm.org/d6951_d6951m-18.html)). The method goes back to Scala's cone penetrometer for pavement design in Australia (Scala 1956, "Simple methods of flexible pavement design using cone penetrometers," *New Zealand Engineering* 11 (2); [Informit record](https://search.informit.org/doi/10.3316/informit.218423931293630)), was developed for road assessment in South Africa (Kleyn 1975, *The use of the Dynamic Cone Penetrometer (DCP)*, in Afrikaans, Transvaal Roads Department, Pretoria, Report L2/75), and was adopted by the US Army Corps of Engineers for rapid airfield and road assessment (Webster, Grau and Williams 1992, *Description and Application of Dual Mass Dynamic Cone Penetrometer*, USACE Waterways Experiment Station, Instruction Report GL-92-3, [DTIC ADA251960](https://apps.dtic.mil/sti/tr/pdf/ADA251960.pdf)). The UK Transport and Road Research Laboratory published a program and manual for analyzing DCP data for roads in developing countries (Overseas Road Note 8, *A users manual for a program to analyse dynamic cone penetrometer data*, TRRL, 1990; [record](https://transport-links.com/fcdo-publications/orn8-a-users-manual-for-a-program-to-analyse-dynamic-cone-penetrometer-data-dos-version)).

The weak point is the reading. In the manual method, one person drops the hammer and a second reads the rod position against a separate rule after each blow or set of blows, then the record is typed up and reduced by hand or in a spreadsheet. That makes the test slow, needs two trained people, and introduces reading and transcription errors, which matter most in stiff layers where the penetration is only a few millimeters per blow.

Instrumented and automated penetrometers exist. Examples include variable-energy penetrometers that record the energy and penetration of every blow (the PANDA variable-energy penetrometer developed at Blaise Pascal University and sold by Sol Solution, France; [manufacturer literature](https://www.insitutek.com/products/panda-instrumented-dcp/)) and vehicle- or trailer-mounted automated DCPs. They are built for professional survey teams, are closed, and cost many times the $400 prototype budget (estimate; prices were not checked in this session). There is no open, low-cost, standard-geometry DCP with automatic depth and blow logging that a small contractor, NGO engineer or student can build, audit and repair.

## Users and context

| User | Need | Context |
| --- | --- | --- |
| Site engineer or technician at a small contractor or municipality | A quick, recorded strength profile for subgrade, trench backfill or a pad before work starts | Road edges, building plots, trenches; one person on site |
| NGO or humanitarian engineer | Screen ground for shelters, water tanks, latrines and access tracks where no lab is within reach | Remote sites, no reliable grid or cell signal, heat and dust |
| Low-volume road agency staff | Layer strengths along a road to plan gravel and drainage, in line with DCP-based design practice | Rural roads, many test points per day |
| Student or researcher | An open instrument and data format to study DCP correlations and soils | Teaching labs, field courses |

## What the user gets, and what they do not

ConePro gives a DCP index profile and an **indicative** CBR profile from the published correlations. It does not give an allowable bearing pressure for foundation design. Correlations from DCP results to bearing capacity exist but are soil-specific and scattered, so ConePro results are for screening and for deciding where proper geotechnical investigation is needed, not a substitute for it.

## Constraints

- Garage-buildable prototype, about $400 USD in parts, using machined or bought steel parts and off-the-shelf electronics modules.
- Keep the ASTM D6951 mechanical geometry (8 kg hammer, 575 mm drop, 16 mm rod, 20 mm 60 degree cone) so results can be compared with published correlations and existing DCP data.
- One person must be able to carry, set up and run a test.
- Works with no cell signal: data stays on the logger and the phone until the user exports it.
- Electronics must survive steel-on-steel impacts every few seconds, rain, dust and 0 to 45 °C.

## Out of scope

- Allowable bearing pressure or foundation design.
- Static cone penetration testing (CPT) with pushing rigs.
- Cloud services; the phone app exports files only.
- Motorized hammer lifting.

## Open questions

- Which user group to co-design with first? Decided by Amish on 2026-10-02: the first candidate to approach is a low-volume road agency (a county or district road department) that already runs manual DCP tests on unpaved roads, with a university pavement or geotechnical lab as the second choice. Not yet agreed with any partner.
- Build complete instruments, or also offer the sensor set as a retrofit? Decided by Amish, 2026-09-25 (CNP-DDR-001, D3): design the sensor set to fit standard DCPs, and build the complete instrument for the prototype.
- The sources above were checked online on 2026-09-25 (ASTM D6951 geometry and correlations, Scala, Kleyn, Webster and others, ORN 8, PANDA). Commercial prices for instrumented penetrometers are still unchecked.

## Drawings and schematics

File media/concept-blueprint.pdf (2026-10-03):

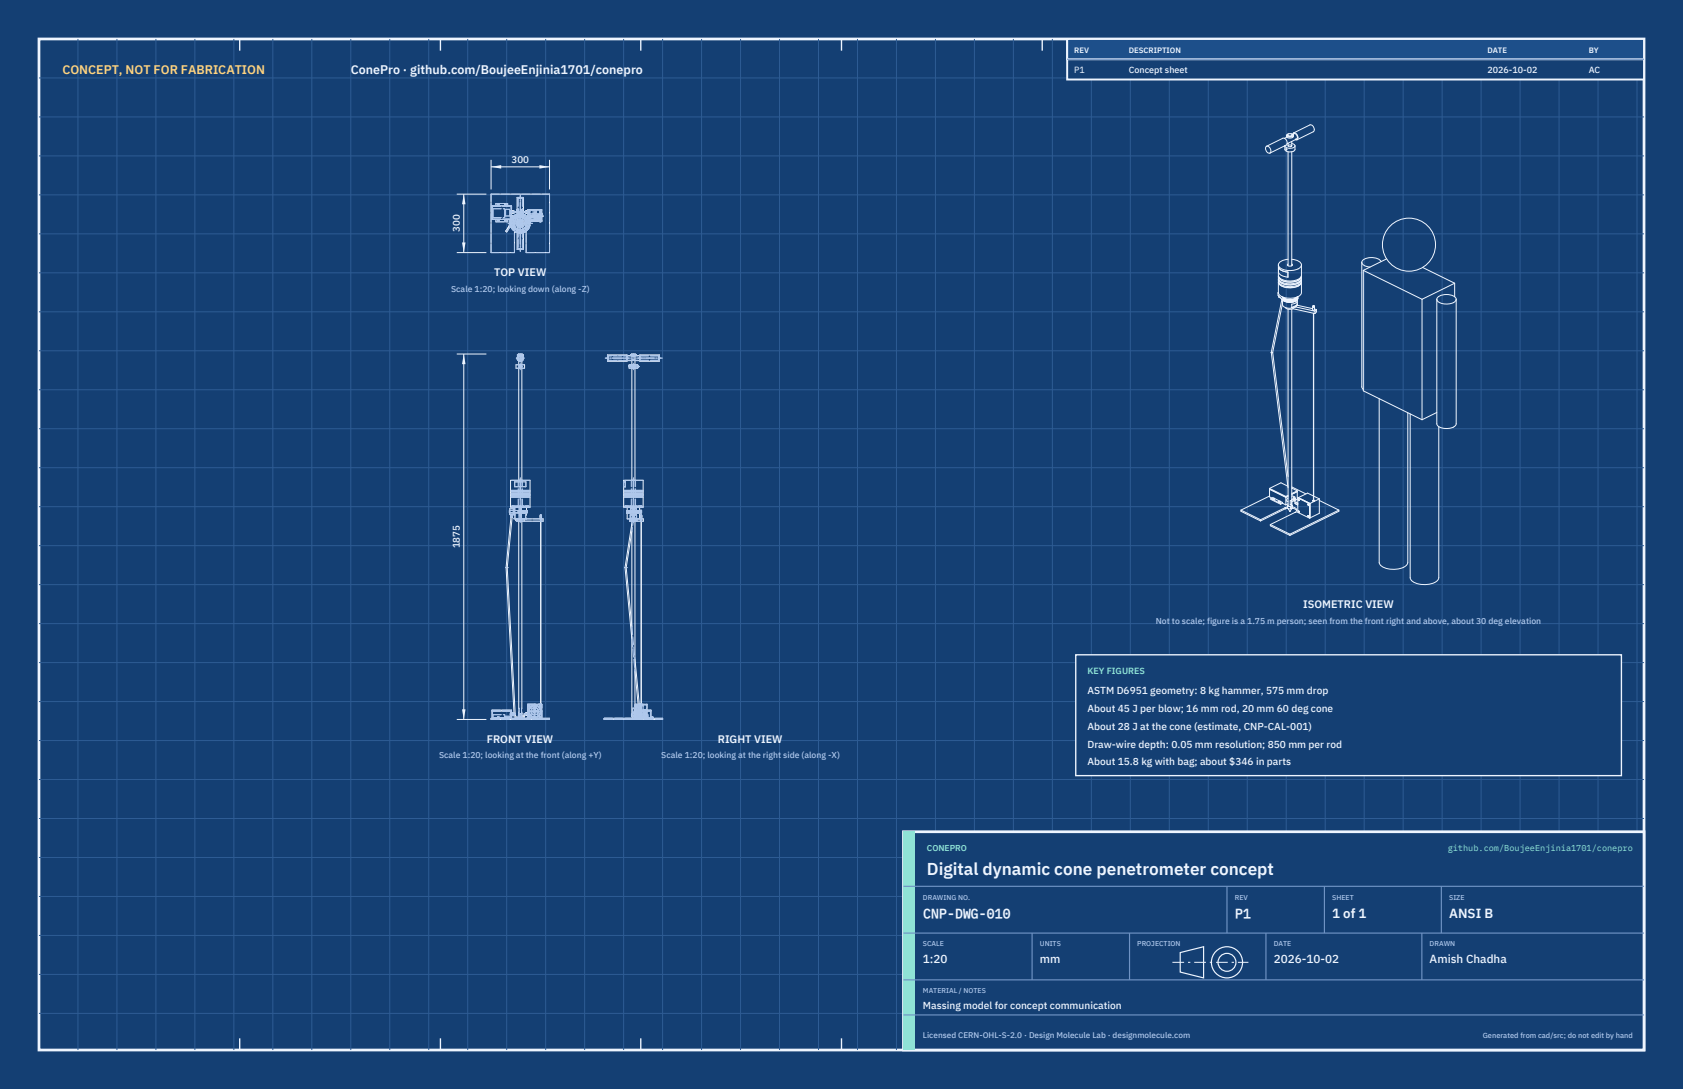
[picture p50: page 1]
CONCEPT, NOT FOR FABRICATION; ConePro · github.com/BoujeeEnjinia1701/conepro; FRONT VIEW; TOP VIEW; RIGHT VIEW; ISOMETRIC VIEW; REV; DESCRIPTION; DATE; Concept sheet; CONEPRO; github.com/BoujeeEnjinia1701/conepro; DRAWING NO. CNP-DWG-010; REV P1; SHEET 1 of 1; SIZE ANSI B; SCALE 1:20; UNITS mm; PROJECTION; DRAWN Amish Chadha; Licensed CERN-OHL-S-2.0 · Design Molecule Lab · designmolecule.com; Generated from cad/src; do not edit by hand

Scale 1:20; looking down (along -Z)

Not to scale; figure is a 1.75 m person; seen from the front right and above, about 30 deg elevation

KEY FIGURES
ASTM D6951 geometry: 8 kg hammer, 575 mm drop
About 45 J per blow; 16 mm rod, 20 mm 60 deg cone
About 28 J at the cone (estimate, CNP-CAL-001)
Draw-wire depth: 0.05 mm resolution; 850 mm per rod
About 15.8 kg with bag; about $346 in parts

Scale 1:20; looking at the front (along +Y)

Scale 1:20; looking at the right side (along -X)

Digital dynamic cone penetrometer concept

MATERIAL / NOTES
Massing model for concept communication

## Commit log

2026-09-24 Initial scaffold: standard open hardware layout, CERN-OHL-S v2 + MIT licenses
    Claude-Session: https://claude.ai/code/session_01XuhhSU4W6fYhgCfURbrkut
    [bom.csv]
2026-09-25 Adopt portfolio kit v1.3.0: session commands, scale figure, 3D viewer, flow diagrams
    Adds .claude/commands (/populate, /advance-trl3, /rein-in, /refresh-media)
    so every Claude Code session starts from the standard prompts, and extends
    concept media with a 1.75 m scale figure, an interactive glTF viewer and
    system or energy flow diagrams. TRL cap 3 unchanged.
    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
2026-09-25 Kit v1.3.1: renderer fixes from the TremorTrace pilot
    Context scale parts for small objects, cutaway exclusions, and text
    labels in flow diagrams.
    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
2026-09-25 Populate conepro to a strong TRL 2 with concept media (batch 7)
    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
    [bom.csv]
2026-09-25 Advance conepro to TRL 3 (batches 7 and 8)
    Decisions approved by Amish 2026-09-25 recorded in DDR-001. TRL 4 is on hold.
    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
    [bom.csv, conepro-assembly.step, conepro-assembly.stl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]
2026-09-26 Accept all recommendations (DDR-002), switch footer to designmolecule.com, add README write-up with new inspiration point
    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
    [bom.csv, conepro-assembly.step, conepro-assembly.stl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]
2026-09-27 Product appearance model and photoreal renders
    Adds cad/src/product_model.py (appearance model for renders only, all main
    dimensions from model.py) and Blender renders in media/render-*.png,
    captioned with the project, repository and viewing direction. README leads
    with the product render; trl stays 3.
    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
2026-09-27 Reel housing grown to 72 x 60 x 72 mm for the 60 mm drum
    Amish approved the recommendation on 2026-09-27 (CNP-DDR-003). Stroke
    928 mm, still clear of the 850 mm usable range; R5 met, R2 at risk.
    Model, appearance model, STEP and STL, drawing (Rev P3), concept media,
    calculations, requirements, precis and BOM updated. Photoreal renders
    follow in the next commit.
    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
    [bom.csv, conepro-assembly.step, conepro-assembly.stl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]
2026-09-27 Re-render with the larger reel housing and 60 mm drum
    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
2026-10-01 Image quality pass: legible exploded views, flow diagrams and drawing sheets
    Kit 1.6.1 image layout: the parts list sits in its own column, number bubbles sit on visible parts and never overlap, small parts get a leader, pictures are cropped to the subject, flow labels keep numbers with their units, and sheet captions and the revision table no longer overprint. Concept images, blueprint and general arrangement sheet regenerated; repo-specific labels moved clear of other text and lines.
2026-10-01 Kit 1.7.0: constructable design, illustrated build plan and design decisions register
    The design is now constructable: every part can be made and fits its neighbours, with each change recorded in a Design for construction decision record (made under Amish's 2026-09-30 instruction; ope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
    [bom.csv, conepro-assembly.step, conepro-assembly.stl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]
2026-10-01 Budget treated as a value-engineering target
    Amish, 2026-10-01: the budget is a hypothetical control target that keeps the design on a value-engineering lens, not a spending limit. Documents now state the value-engineering target and the estima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
2026-10-02 Record Amish's approval of the open-decision recommendations
    Amish approved the recommendation on every open decision in the design decisions register ("i approve your recommendations for all 555 open decisions.", 2026-10-02). Each decision is moved to Decisio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
2026-10-03 Carry approved follow-ups into the design and redo photoreal renders
    Amish approved the follow-up actions from the open-decision sign-off ("APPROVED CHANGES, COMPLETE THESE", 2026-10-02), the design-for-construction change tables in ten repos, the last wave's open dec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
    [bom.csv, conepro-assembly.step, conepro-assembly.stl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]
2026-10-03 Record Amish's 2026-10-03 decisions; FlatTrike fork and PotPress guard fixes
    Amish, 2026-10-03: "PalletPilot - i accept it"; "FlatTrike - i accept your design recommendation, proceed and execute the solution for fork direction or caster"; "PotPress - move forward with the four guard fixes. I accept the cost."; "GravitySort - i accept your recommendation"; "TIght Margins - i accept the margins"; "Cost over target - i accept all the cost variations and overruns". FlatTrike knuckle forks turned to trail (35 mm trail); PotPress finer mesh, small-hole plates, top beam and crank bracket covers, ISO 13857 desk check now met on paper. Registers, requirements, drawings, pictures, renders and PDFs upd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

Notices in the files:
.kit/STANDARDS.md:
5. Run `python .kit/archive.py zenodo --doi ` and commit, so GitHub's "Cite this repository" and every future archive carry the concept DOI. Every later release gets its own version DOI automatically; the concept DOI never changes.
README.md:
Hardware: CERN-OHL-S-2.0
